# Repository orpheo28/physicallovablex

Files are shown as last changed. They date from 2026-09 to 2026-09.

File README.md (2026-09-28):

# PhysicalLovableX

Describe a physical product in one sentence; get a 3D model, its unit cost, a factory shortlist, and a package a factory can quote from.

## In 30 seconds

**What it does.** A Studio where you describe a product ("a Whoop competitor, screenless, 5-day battery"), see it in 3D with its cost at 500 / 2,000 / 10,000 units and its top factories, refine it by prompting, then press **Make it** to autofill the rest of the path to production: factories, negotiation, tooling, QC, logistics and duties, cash plan, brand. The output is a **Launch Dossier** (EN + CN).

**For whom.** Hardware founders, first consumer-electronics founders who have a prototype and pledged money and are stuck on production (`gtm-harness/context/icp.md`).

**The thesis.** Hardware ships late because nobody translates the idea into what a factory can build: making it manufacturable, choosing components, passing certification, speaking the factory's language. It is not mainly a design problem or a factory-access problem. We do the translation. The primitive is the **Factory Pack**: a spec package a factory can quote and build without back-and-forth. Every later layer (negotiation, QC, logistics, financing) consumes it (`docs/PRODUIT.md`, `docs/PRD.md` §1-3).

**How.** In software the AI writes code; in hardware, **CAD is code**. The AI writes build123d programs, they run in a sandbox, the result is measured, and on an error the AI repairs its own code.

## Links

| | |
|---|---|
| Live app | https://physicallovablex.vercel.app (password in the email) |
| Public docs | https://physicallovablex.vercel.app/docs |
| Agent guide | https://physicallovablex.vercel.app/agents.md (also `/llms.txt`) |
| Demo video | see email |

## What you can do

1. **Describe.** One sentence, in idea mode or prototype mode (paste a BOM).
2. **See.** The product in 3D, unit cost at 500 / 2k / 10k, and a top-3 factory shortlist on one screen. First version in 18-24 s over several live runs.
3. **Refine by prompting.** "Add SpO2 and skin-temperature sensing", "make it pink", "thinner, 8 mm pod". Each prompt creates a restorable version with a diff (CAD, BOM with real LCSC parts, costs, measured DFM, certifications, shortlist). Geometry changes are made by the AI editing its own build123d program, which is re-run, re-measured and self-repaired on error; the code is visible in the "CAD code" tab. Colour and feature refines take 4-7 s, geometry refines 11-24 s.
4. **Touch a part.** Click a part in the 3D view to change its colour, material or a dimension. This is a deterministic edit with no AI call (1.6-3.8 s in QA) and still produces a new version with a diff.
5. **Look inside.** Anatomy mode walks through the product layer by layer, generated from the real BOM. It is labelled "Illustrative internal layout — not a routed PCB".
6. **Make it.** 13 steps autofill to the Launch Dossier (EN + CN) in 54-88 s live, or instantly on the 7 showcases recorded through Make it (11 showcases in all).

**Pro CAD (shipped, on by default).** Standard fasteners, inserts and bosses with ISO 273 clearance holes (`app/api/cad/stdparts/`); assemblies with joints and measured interference and clearance checks (`app/api/cad/assembly/`: 0 interferences on all showcases, and it caught and fixed a real propeller collision on the drone); dimensioned technical drawings in the Studio, the Factory Pack and the Dossier (`app/api/cad/drawings/`). Flags `CAD_DETAIL_LEVEL=pro`, `CAD_ASSEMBLY=1`, `CAD_DRAWINGS=1` (`app/contracts/api.md`).

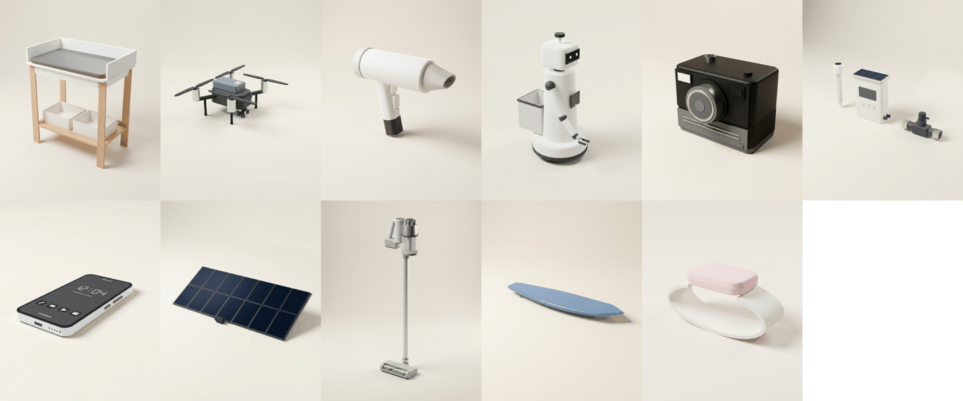
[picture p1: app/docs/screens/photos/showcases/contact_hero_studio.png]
Showcase gallery: 11 recorded products, rendered from their CAD


| Overview: cost at three volumes, shortlist, labels | Refine by prompting and by touching a part |
|---|---|
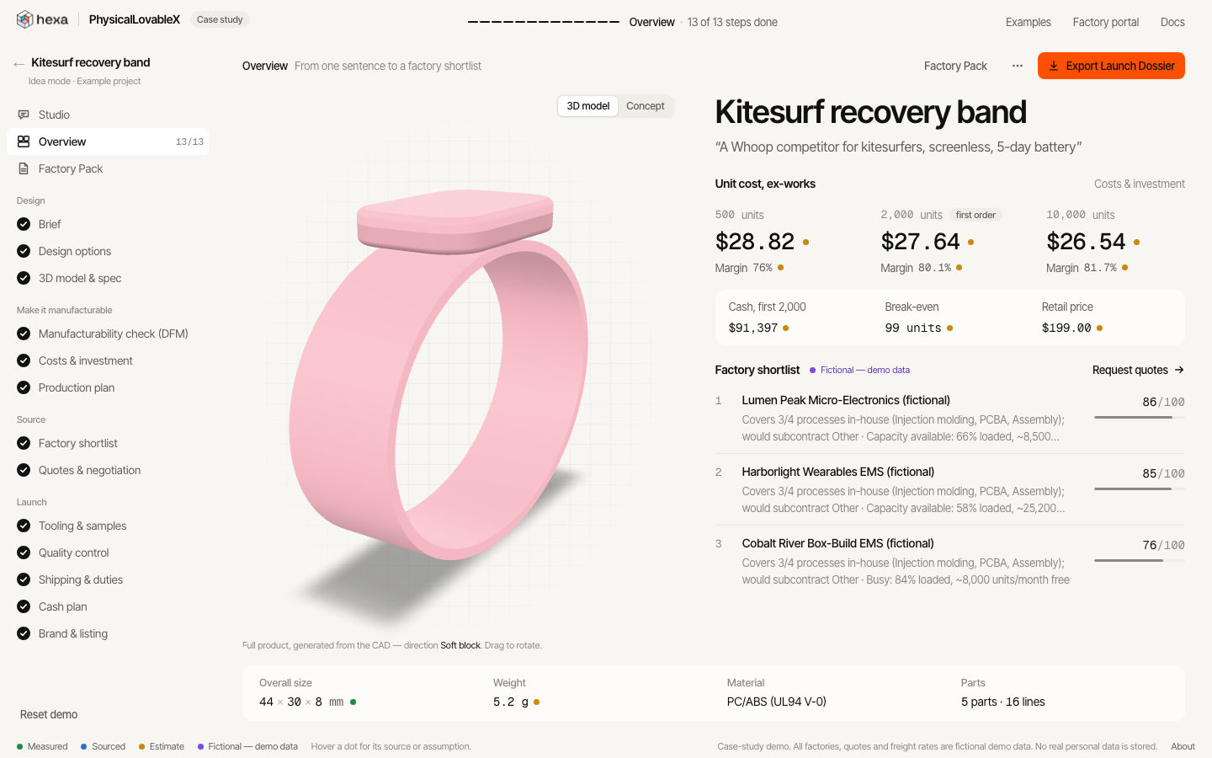
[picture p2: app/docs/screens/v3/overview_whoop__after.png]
Overview of the kitesurf recovery band
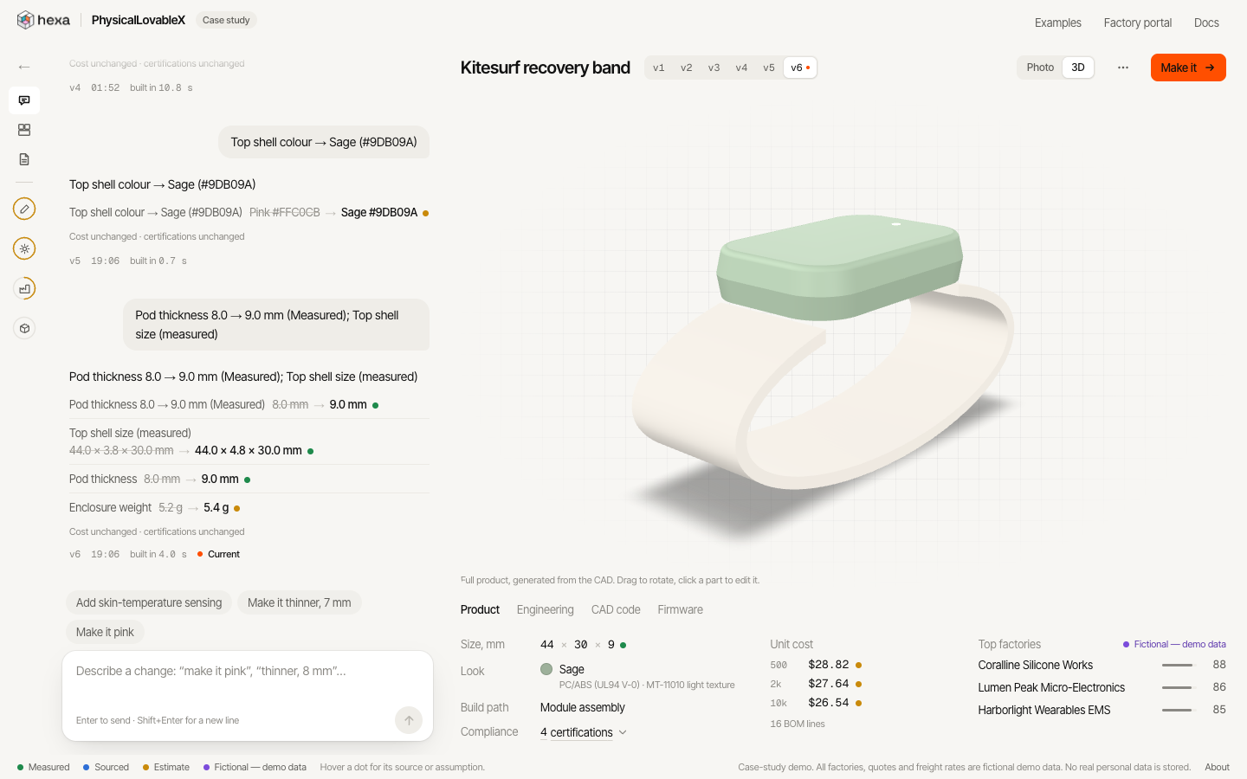
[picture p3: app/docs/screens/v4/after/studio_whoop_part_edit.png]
Studio with version history and part edits
|  |  |

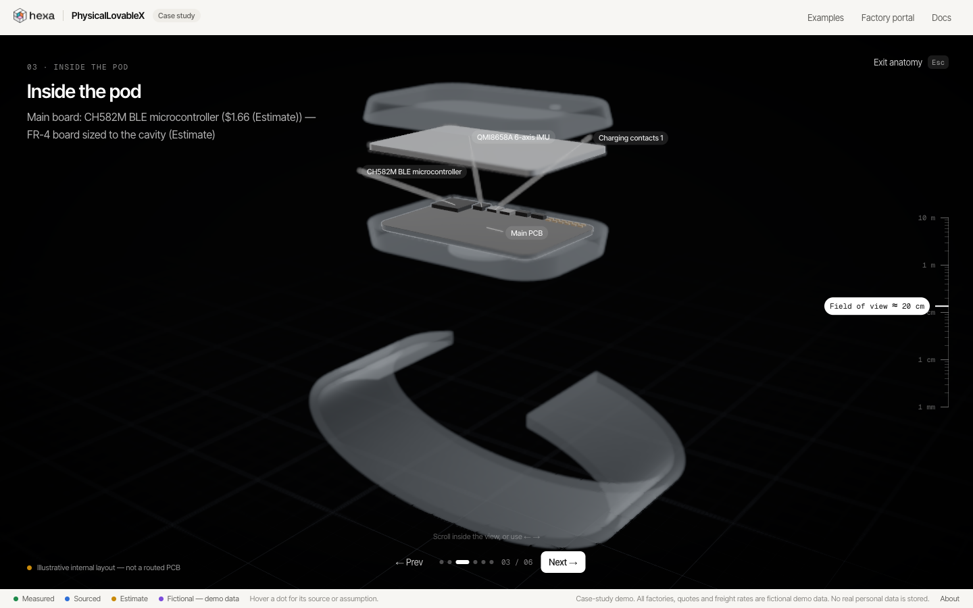
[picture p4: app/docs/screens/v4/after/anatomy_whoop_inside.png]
Anatomy mode: illustrative internal layout from the BOM


Timings: `docs/PRODUIT.md`, `app/docs/DEMO_SCRIPT.md` (measured live over several runs; they vary), `app/docs/QA_REPORT.md`.

## The brief → where it lives

| Case layer | What it means here | Where it lives |
|---|---|---|
| **Lovable layer** | Plain language in → design, CAD, spec, investment, production plan; refine by prompting | `app/api/studio/` (versions, refine, part edits), `app/api/cad/codegen/` (AI-written CAD), `app/api/stages/` (13-stage runner), `app/web/src/app/projects/[id]/studio/page.tsx` |
| **Alibaba layer + production MCP** | The spec is matched to a factory network that exposes capacity through an MCP; any agent can search capacity and request quotes | `app/factory_mcp/server.py` (7 tools), `app/api/mcp_http/` (served at `/mcp`), `app/docs/MCP_DEMO.md`, `app/web/src/app/factories/` (portal) |
| **Infra** | DFM, factory selection, agent negotiation, tooling, QC, logistics and duties, financing | `app/api/dfm/`, `app/api/agents/` (incl. `negotiation/`), `app/api/costs/` (cost, landed cost, HTS, freight), `app/api/engineering/` |
| **Value** | The Factory Pack and the Launch Dossier (PDF, EN + CN) | `app/api/export/` (`factory_pack.py`, `pdf.py`), `app/contracts/artifacts.py` (`FactoryPack`) |
| **Why now** | Generative AI can write and repair CAD code; the gap is translation, not sourcing (sourcing is commoditised) | `docs/PRD.md` §2-3, `app/docs/CAD_BENCH.md`, `gtm-harness/CLAUDE.md` (thesis v2) |

## What is real and what is simulated

Every number on screen, in the API and in the PDF carries one of four labels:

| Label | Meaning |
|---|---|
| **Measured** | Computed by code on the CAD (dimensions, volume, draft, wall thickness, physics checks) |
| **Sourced** | Real price or official rate, with source and date |
| **Estimate** | An assumption, shown |
| **Fictional — demo data** | Invented for the demo; factory names end with "(fictional)" |

**Data sources (Sourced):** LCSC / JLCPCB parts snapshot for component prices and stock (dated 2026-09-26); USITC HTS schedule and CBP CROSS rulings for the tariff line and duties; Drewry World Container Index for the sea-freight lane; eCFR and EUR-Lex for certification citations; EU PVGIS for solar yield; V-Trust for the QC man-day benchmark. Code: `app/api/costs/` (`lcsc.py`, `hts.py`, `precedent.py`, `freight.py`, `landed.py`), `app/api/agents/certification.py`, `app/api/engineering/solar.py`.

**Limits** (`app/docs/public/limits.md`):
- CAD is concept-level: good enough to see, measure, cost and brief a factory; not tooling-ready. About 80% of the translation is automated; humans and real factories cover the rest.
- The Anatomy internal layout is illustrative, not a routed PCB. Electronics stop at a power tree, netlist-level connections and a power budget.
- The generated firmware skeleton is not compiled or tested.
- All 15 partners (11 factories, 1 integrator, 3 installers), their capacity, quotes, negotiation replies, carrier freight quotes and transit days are fictional. The negotiation is a real agent loop over the MCP tools, but every reply is simulated; in Make it the quote is auto-approved and flagged.
- The HTS line is a precedent from CBP rulings, not a binding classification.
- The CN translation is machine-made and labelled "to be reviewed by a native speaker".

Stage-by-stage table of what is real: `app/README.md` ("Real vs simulated"). Audit of the labels: `app/docs/HONESTY_AUDIT.md`.

## Measured numbers

| What | Result | Source |
|---|---|---|
| Studio, first version | 18-24 s over several live runs | `docs/PRODUIT.md`, `app/docs/DEMO_SCRIPT.md` |
| Refines | colour and feature 4-7 s; geometry (AI edits its CAD) 11-24 s | same |
| Make it, 13 steps to the Launch Dossier | 54-88 s live (≈ $0.34 in one run) | same |
| Part edits (no AI) | colour 1.6 s, material 1.6 s, dimension 3.8 s (one QA run) | `app/docs/QA_REPORT.md` (3D wave regression, §3) |
| Core path, one live QA run | idea → v1 23.7 s; "Add SpO2…" 5.2 s; "Make it pink" 4.2 s; Dossier export 0.35 s, 38 pages | `app/docs/QA_REPORT.md` (§7) |
| Text-to-CAD benchmark | 20/20 prompts valid on the first try, 95 % within ±25 % of target size, 100 % OCCT-valid; ≈ 27 s per prompt | `app/docs/CAD_BENCH.md` |
| Retrieval-augmented CAD prompts (84 example programs) | no measurable gain on this benchmark; kept off by default | `app/docs/CAD_BENCH.md` |
| Backend tests | 719 passed, 31 skipped (final whole-suite run, C5 regression, 28 Sep; verdict "ready for pass-7") | `app/docs/QA_REPORT.md` ("C5 — pro CAD integration (28 Sep)") |
| Assembly checks | 0 interferences on all showcases; caught and fixed a real propeller collision on the drone | `app/api/cad/assembly/` |
| Web checks | `tsc --noEmit`, `lint`, production build: all pass (same run) | `app/docs/QA_REPORT.md` |
| Anatomy | 5 products, 6-7 steps each, open in ≤ 0.17 s | `app/docs/QA_REPORT.md` (§5) |

The QA report also lists the open bugs found at each wave, with severity.

## Architecture

```mermaid
flowchart LR
  L[Framer landing page] --> W
  U[Founder in a browser] --> W
  subgraph Vercel
    W[Next.js web app<br/>password gate · /backend proxy<br/>/docs · /agents.md · /llms.txt]
  end
  subgraph Railway
    A[FastAPI<br/>stage runner · Studio · cost engine]
    C[build123d sandbox<br/>AI-written CAD, measured]
    D[(SQLite<br/>projects · versions)]
    M[factory_mcp<br/>7 tools · fictional network store]
    H["/mcp<br/>Streamable HTTP, Bearer token"]
    A --> C
    A --> D
    A --> M
    H --> M
  end
  W --> A
  A --> O[OpenRouter<br/>main · fast · CN · image routes]
  X[External agents<br/>Claude Code, Claude Desktop, scripts] --> H
```

**Stack.** Python 3.12 with uv, FastAPI, build123d 0.13 (OpenCascade), SQLite, the official MCP Python SDK. Next.js 16, React 19, three.js with react-three-fiber (model-viewer fallback via `?viewer=basic`). Models through OpenRouter on four routes (main, fast, CN, image), configured by environment. Every LLM call goes through `app/api/llm.py` (JSON-schema validation, one retry); any stage failure serves a cached example with a visible banner. Deploy: Railway for the API (Dockerfile, volume at `/data`), Vercel for the web.

## Repository map

```
app/                     the product (see app/README.md)
  api/                   FastAPI backend
    stages/              13-stage runner, plug-in registry, fixture fallback
    studio/              versions, refine jobs, part edits, restore
    cad/                 build123d CAD: families, codegen/ (AI-written CAD), anatomy/, photos/, stdparts/, assembly/, drawings/
    dfm/                 measured DFM on the STEP
    costs/               cost engine, LCSC, HTS, duties, freight, landed cost
    agents/              brief, DFM review, certification, planning, brand, negotiation/
    engineering/         physics checks, electronics, firmware skeleton, build strategy, solar
    export/              Factory Pack assembly and Launch Dossier PDF
    mcp_http/            the production MCP over HTTP at /mcp
    fixtures/            cached examples and showcases (the fallback path)
  web/                   Next.js app (Studio, 13 stages, Overview, portal, public docs)
  factory_mcp/           production MCP server (7 tools) and the fictional network
  contracts/             Pydantic models, JSON schemas, API contract (read first)
  tests/                 pytest suites, CAD benchmark harness, 10-prompt runner
  docs/                  QA report, CAD benchmark, demo script, deploy, honesty audit, public docs, screenshots
  scripts/demo_start.sh  one-command local start
gtm-harness/             go-to-market agent harness (context, skills, workflows, playbooks)
gtm/                     landing copy, sequences, content plan, video scripts
docs/                    PRD.md (full spec), PRODUIT.md (one-page product definition)
```

**Start here** — the 10 files that explain the system fastest:

1. `app/contracts/api.md` — every route, section by section, including the Studio refine job
2. `app/api/stages/runner.py` — how a stage runs and falls back to a cached example
3. `app/api/studio/engine.py` — start, refine, restore; one commit per version or nothing
4. `app/api/cad/codegen/engine.py` — the AI writes build123d, the sandbox runs it, it is measured and repaired
5. `app/api/cad/anatomy/` — the illustrative internal layout built from the BOM (no LLM)
6. `app/api/costs/engine.py` — deterministic cost engine; the LLM only proposes BOM lines
7. `app/api/engineering/service.py` — physics checks, electronics, firmware skeleton
8. `app/factory_mcp/server.py` — the 7 production MCP tools
9. `app/web/src/app/projects/[id]/studio/page.tsx` — the Studio screen
10. `gtm-harness/CLAUDE.md` — ICP, signals, positioning, thesis in one page

## Go-to-market

- `gtm-harness/` is a Claude Code harness for founder-led outreach. `CLAUDE.md` is the one-page brief; `context/` holds the ICP (late crowdfunded consumer-electronics founders first), six scored buying signals with decay, positioning, competitor battlecards, metrics and personas.
- `gtm-harness/skills/` has nine repeatable procedures (ICP scoring, account research, signal-to-sequence, teardown, value pack, reply handling, call debrief, weekly update, AEO check); `workflows/` and `playbooks/` cover routing, campaigns, enrichment, and what to do when a founder replies.
- Rules built in: every claim carries a source or is marked Hypothesis; a human approves and sends every message; no contact data is stored in the repo.
- `gtm/` holds the landing page copy and Framer components, the written (not executed) sequences, a four-week content plan, the GTM stack by phase, and the demo and launch video scripts.

## How it was built

- **Orchestration.** One Monitor session planned the work and dispatched about 40 parallel Claude Code worker sessions (W0-W29, C1-C5). Each worker owned its folders (`app/README.md`, "Layout and owners").
- **Contracts first.** Pydantic models, JSON schemas, the API contract and generated TypeScript types were frozen before the first wave (`app/contracts/`). Changes are additive and recorded per worker in `api.md`.
- **Fixtures and fallbacks.** Every stage has a cached example: on an AI failure it serves that example with a visible "Cached example" banner instead of an error.
- **QA waves.** Dedicated QA sessions ran regression passes between waves, up to release checkpoint pass-6 (`app/docs/QA_REPORT.md`).
- **Timeline.** Saturday 26 to Monday 28 September 2026.
- **Budget.** The product's own model calls (development, QA, benchmarks) cost about $17 on OpenRouter, measured on the key's usage counter ($16.69 after the CAD benchmark, `app/docs/CAD_BENCH.md`). Each QA wave records its live spend in the QA report.

## Run it locally

```bash
cd app
cp .env.example .env        # optional: add OPENROUTER_API_KEY and the model routes; without a key every stage serves fixtures
uv sync
(cd web && npm install)
scripts/demo_start.sh       # API on :8000, production web build on :3000, seeds demos and showcases, prints READY
```

Tests:

```bash
uv run pytest                                   # offline, no key needed
cd web && npx tsc --noEmit && npm run lint && npm run build
```

Details: `app/README.md` (run, env guards, contracts), `app/docs/DEMO_DAY.md` (start script, offline backup). Deploy (Railway API + Vercel web): `app/docs/DEPLOY.md`. Production MCP setup: `app/docs/MCP_DEMO.md`.

## Roadmap (next 90 days)

- **Real factory onboarding through the MCP.** The registration flow exists; real, audited factories do not yet. First ones introduced by intermediaries who already hold factory trust (`docs/PRD.md` §18).
- **Human-reviewed Factory Packs (tier 2).** An engineer signs every pack before a real factory sees it, with a committed landed price.
- **Text-to-PCB.** Today electronics stop at the power tree and netlist-level connections.
- **A fine-tuned CAD model**, trained on programs that pass the sandbox and the measurements.

## Credits and licences

- [build123d](https://github.com/gumyr/build123d) — CAD kernel interface (OpenCascade)
- [three.js](https://threejs.org) — 3D viewer
- [Poly Haven](https://polyhaven.com) — CC0 studio HDRI (`app/docs/BRAND.md`)
- [earthtojake/text-to-cad](https://github.com/earthtojake/text-to-cad) (MIT) — DFM measurement ported in `app/api/dfm/measure.py`
- [CDFER/jlcpcb-parts-database](https://github.com/CDFER/jlcpcb-parts-database) (MIT) — LCSC / JLCPCB parts snapshot
- [bd_warehouse](https://github.com/gumyr/bd_warehouse) (Apache-2.0) — reference data for standard parts; not a dependency (`app/api/cad/stdparts/README.md`)

## License

Source-available for evaluation only ([LICENSE.md](LICENSE.md)): you may read, clone, run and analyse it (including with AI assistants) to evaluate the project. Any other use, including commercial use, redistribution, derivative works or model training, needs written permission. Copyright 2026 Orphéo Hellandsjo.

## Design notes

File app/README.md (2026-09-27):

# PhysicalLovableX — MVP

## What it is
The Lovable of physical products, built as a **Studio**: describe a product in a sentence, see it in 3D with its cost and top factories (first version in 18-24 s over several live runs), then refine it by prompting: colour and feature changes take 4-7 s, geometry edits 11-24 s, and each creates a restorable version with a diff (CAD, real LCSC parts, costs, measured DFM, certifications, shortlist).
In software the AI writes code; in hardware **CAD is code**: the AI writes build123d code, it runs in a sandbox, is measured and self-repaired on error (visible in the "CAD code" tab); physics checks then run on the measured model. Concept-level geometry: about 80% of the translation is automated, humans and real factories cover the last 20%.
**Make it** autofills the rest (factories via the production MCP, agent negotiation with auto-approvals flagged, tooling, QC, logistics and duties, cash plan, brand) to the Launch Dossier (EN + CN), 13 steps in 54-88 s live, or instantly on the 11 recorded showcases; the 13 stages stay as the detailed view, in 4 phases. The primitive is the **Factory Pack**.
Real: AI-written CAD, measured DFM and physics checks, LCSC prices, HTS/duties, PVGIS, Drewry freight index. Fictional and labeled: the 15 fictional partners (11 factories, 1 integrator, 3 installers), their quotes, carrier freight; firmware skeletons are generated, not compiled or tested. The production MCP is served over HTTP at `/mcp` (`docs/MCP_DEMO.md`). The build strategy (full design / module assembly / ODM customisation) is chosen per product, and 11 recorded showcases are included.
Specs: `../PRD.md` (§8.2-8.5), `../PLAN.md`, `../MONITOR.md`; demo: `docs/DEMO_SCRIPT.md`.

## Run
```bash
# API (from mvp/) — Python 3.12 via uv
cp .env.example .env            # add OPENROUTER_API_KEY + the 3 model routes; without a key every stage serves fixtures
uv sync
uv run uvicorn api.main:app --port 8107         # any free port; keep 8000/3000 for the deployed setup
# parallel dev sessions: isolate state, e.g. DB_PATH=api/data/w7.db FILES_DIR=api/data/files_w7 (the factory store follows: api/data/w7_network.db)
curl -X POST localhost:8107/demo/reset          # seeds the 2 cached examples (desk lamp, tracker card) + resets the factory network

# Web
cd web && npm install && NEXT_PUBLIC_API_URL=http://localhost:8107 npm run dev

# Tests (offline, no key, temp DB/network/CAD dirs — covers tests/, api/, factory_mcp/)
uv run pytest

# The 10 PRD test prompts against a running API (live if the key is set) → tests/results/<timestamp>.md
uv run python tests/run_prompts.py --base-url http://localhost:8107 [--only 3,4,5]

# Production MCP server (stdio) — see factory_mcp/README.md for Claude Code / Desktop config
uv run python -m factory_mcp.server
```

Env guards: `LLM_MAX_TOKENS` (per request), `LLM_MAX_REQUESTS` (per API process), `LLM_TIMEOUT_S`,
`LLM_REASONING_EFFORT` (default `low`), `STAGE_TIMEOUT_S` (default 45 — hard cap per stage and on the Factory Pack, then the
cached fixture with reason "timeout"). Key stays server-side; `.env` is gitignored.

Autorun is asynchronous (serverless-friendly): `POST /projects/{id}/autorun` → 202, then poll `GET /projects/{id}` every 2 s
(`autorun.state`, `autorun.current_stage`, per-stage status). `?wait=true` keeps the synchronous behaviour for scripts.

Latest live run: `tests/results/` (10/10 pass, wow screen ≈ 1 min per prompt — see the report for per-stage times).

## Deploy
Web on Vercel (root `web/`), API + CAD on Railway (`Dockerfile` + `railway.toml`, volume at `/data`). Full click-by-click steps,
env vars, rollback and costs: **`docs/DEPLOY.md`**. Agents prepare, the owner clicks deploy.

| Env (API) | Effect |
|---|---|
| `API_SHARED_KEY` | set → every route except `GET /health` (files included) needs header `X-App-Key`; unset → open (local dev). The web password (`APP_PASSWORD`) is a separate, web-only variable |
| `MAX_STORED_PROJECTS` | keep only the N most recent generated-CAD folders in `FILES_DIR` (default 30; Railway trial volume ≈ 0.5 GB) |
| `CORS_ORIGINS` | comma-separated allowed web origins (default `http://localhost:3000`) |
| `RATE_LIMIT_PER_DAY` | live runs per client IP per 24 h on `POST /projects`, `/stages/*/run`, `/autorun` (default 20, 0 = off; only when a key is set) → 429 |
| `DEMO_READONLY=1` | no live AI runs (403); cached demo projects, fixtures, portal and PDF still work — zero-cost public mode |
| `SEED_DEMO_ON_EMPTY=1` | seed the two demo projects at startup when the DB is empty (set in the Docker image) |
| `DB_PATH`, `FILES_DIR`, `FACTORY_MCP_DB` | `/data/app.db`, `/data/files`, `/data/network.db` in the image (Railway volume) |

Local container check: `docker build -t plx-api . && docker run -p 8000:8000 plx-api` (peak ≈ 365 MiB for a CAD build + export; image 2.0 GB, ≈ 470 MB compressed).
Honesty audit of the numbers shown to users: `docs/HONESTY_AUDIT.md`.

## Contracts (read before coding)
- `contracts/artifacts.py` — Pydantic models for the 13 stage artifacts, Factory Pack, network records, `Label`, `LabeledValue`.
- `contracts/api.md` — routes · `contracts/stage_runner.md` — plug-in API · `contracts/fixtures.md` — fixture layout.
- Regenerate schemas + TS types after a (Monitor-approved) contract change:
  `uv run python -m contracts.export_schemas && (cd web && npm run gen:types)`.

## Layout and owners
| Folder | Owner |
|---|---|
| `contracts/`, `api/main.py`, `api/llm.py`, `api/db.py`, `api/discovery.py`, `api/stages/` | W0 (W7 for integration fixes) |
| `web/` | W1 |
| `api/cad/`, `api/dfm/` | W2 |
| `api/costs/` | W3 |
| `api/agents/` (except `negotiation/`) | W4 |
| `factory_mcp/`, `api/agents/negotiation/` | W5 |
| `api/fixtures/`, `api/export/`, `tests/` | W6 |

Stage modules register with `@stage_handler(n)` and are auto-discovered at startup; nobody edits `api/main.py`.
Every LLM call goes through `api.llm.complete_json` (JSON schema validation + 1 retry); any stage failure serves the
cached fixture with `fallback: true` and a visible "Cached example" banner — the demo never 5xx's on an AI failure.

## Real vs simulated
Honesty labels everywhere (screen + PDF): **Measured** (computed on the CAD), **Sourced** (real price/official rate +
date + URL), **Estimate** (assumption shown), **Fictional — demo data**. Factory names are invented and end with "(fictional)".

| Stage / artifact | What is real | What is simulated or estimated | Label |
|---|---|---|---|
| 1 Brief | Live LLM (main route), ≤5 clarifying questions with defaults, idea + prototype (pasted BOM) modes | Target price when not stated | Estimate |
| 2 Design | 3 parametric directions (LLM proposes, code clamps), real GLB per direction | AI concept renders are illustrative, not the CAD | — |
| 3 CAD + spec | build123d two-shell enclosure → STEP / STL / GLB; dimensions from the STEP bounding box | Weight = measured volume × assumed density; BOM proposed by the LLM | Measured / Estimate |
| 4 DFM | **Measured** draft, undercut, projected area, wall thickness on the STEP (port of text-to-cad DFM, MIT); AI-reviewed alerts with cited rules (never contradict a measurement); rule-based certification map by market; component risk from the LCSC snapshot | Certification costs/lead times; clamp tonnage formula | Measured / Sourced / Estimate |
| 5 Investment | **Real LCSC/JLCPCB prices + stock** (snapshot 2026-09-26) for matched electronic lines; deterministic cost engine, 3 volumes, tooling, cash, margin, break-even | Mechanical parts, assembly, tooling ranges, unmatched parts | Sourced / Estimate |
| 6 Production plan | Process per part with reason | Lead times | Estimate |
| 7 Matching | Deterministic scoring via the production MCP (`search_capacity`) | **The 15 fictional partners (11 factories, 1 integrator, 3 installers) and their capacity** | Fictional — demo data |
| 8 RFQ + negotiation | Real agent loop over the MCP tools (`request_quote` → `submit_quote` → `counter_offer` → `accept_quote`), LLM factory agents with distinct personalities, clamped by policy | **Quotes, replies, final terms** | Fictional — demo data |
| 9 Tooling + samples | Milestones computed from the negotiated lead time; payment split follows the approved quote's terms; date checks | Durations beyond the quote | Estimate / Fictional |
| 10 QC | ISO 2859-1 sample size (General II), defects mapped to spec lines, $268/man-day benchmark | Inspection days | Sourced / Estimate |
| 11 Logistics | HTS from the closest **CBP CROSS ruling precedent** + cached USITC schedule (general rate Sourced; Section 301 Sourced when a ruling cites a 9903.88.xx heading, e.g. lamp 8513.10.40.00 = 3.5 % + 25 %, tracker 8517.62.00.90 = Free + 7.5 %); sea freight derived from the **Drewry WCI** lane rate (Sourced) | Classification itself (precedent, not binding — confirm with a broker), LCL/FCL derivation and air $6/kg by chargeable weight (Estimate), transit days (Fictional) | Sourced / Estimate / Fictional |
| 12 Financing | Cash curve = stage 5 total cash, allocated to stage 9 milestones | Financing options are typical ranges | Estimate |
| 13 Brand | Live LLM name options, packaging spec, landing copy, Shopify + Amazon drafts | — | Estimate |
| Factory Pack / PDF | Assembled from stages 1-6; CN machine translation via the CN route (labeled "to be reviewed by a native speaker") | — | as per source |

Cached examples (`api/fixtures/desk_lamp`, `api/fixtures/tracker_card`, regenerated by their `build_*.py`): measured DFM
values are the real output of `api/dfm/measure.py` on `api/cad/prebuilt/<id>/enclosure.step`; landed cost, duties,
freight and stages 11-12 are computed by the live `api/costs` code (`api/fixtures/_live.py`); LCSC prices are real
(jlcsearch, 2026-09-26); design images: `dN.png` = AI concept render (illustrative), `hero_dN.png` = rendered from the CAD.

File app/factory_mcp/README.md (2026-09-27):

# factory_mcp/ — Production MCP (PRD §10)

**Owner: W5.** The "Alibaba layer": a fictional production network exposed as an MCP server, so **any agent**
(ours, Claude, ChatGPT, a buyer's own agent) can query capacity the same way. Research (E_usines.md) found no
public capacity API: the network *creates* the data through factory onboarding (`register_capacity`).

> Everything here is **Fictional — demo data**: the 15 fictional partners (11 factories, 1 integrator, 3 installers), their capacity, quotes, replies and past performance.
> Every name ends with "(fictional)".

| File | What |
|---|---|
| `network.py` | Plain Python (no MCP import): SQLite store + the 7 tools + `list_factories / get_factory / list_rfqs` (factory portal) |
| `server.py` | MCP server (official SDK v2 `MCPServer`, ex-`FastMCP`) exposing the 7 tools over `network.py` |
| `data/factories.json` | 15 seed partners, `kind` factory / integrator / installer: W0's 4 ids + mould maker, box-build EMS, die-caster, 1688-style workshop; 3 installers (W20); 2 wearable EMS + 1 drone/robot integrator (W21); LSR overmolder Coralline (W21b) |
| `data/seed_rfqs.json` | Demo RFQs for the desk lamp (portal history) |
| `data/network.db` | Runtime state (gitignored). Path: `$FACTORY_MCP_DB`, else next to `$DB_PATH` (`app.db` → `factory_network.db`, `<name>.db` → `<name>_network.db`, so isolated DBs never share a store), else here. SQLite WAL |

## Tools
| Tool | Caller | Returns |
|---|---|---|
| `register_capacity(name, region, processes[], materials[], moq, certifications[], lead_time_days, monthly_capacity, current_load_pct)` | factory | `factory_id` |
| `search_capacity(process, material, quantity, certifications_required[], deadline?)` | platform | ranked `FactoryMatch[]` with `score_breakdown` + `reasons` |
| `get_factory_profile(factory_id)` | platform | `Factory` (capacity, audit notes, past performance) |
| `request_quote(factory_id, factory_pack_id, quantities[])` | platform | `rfq_id` |
| `submit_quote(rfq_id, unit_price_per_tier{qty: usd}, tooling_usd, moq, lead_time_days, payment_terms, exceptions[])` | factory agent | `quote_id` (new version) |
| `counter_offer(quote_id, proposed_changes{unit_price_pct, tiers, tooling_usd, moq, lead_time_days, payment_terms}, rationale)` | platform agent | new `Quote` version (`countered`) |
| `accept_quote(quote_id)` | platform, after founder approval | order draft |

`search_capacity` is deterministic: score = 100 × (0.35 process fit + 0.15 MOQ + 0.15 certifications + 0.15 load
+ 0.20 lead time); factories that do not run the process are excluded; ties break on id.

## Run
```bash
cd 04_LIVRABLE/mvp
uv run python -m factory_mcp.server          # stdio
```

**Claude Code**
```bash
claude mcp add physicallovablex-production -- uv --directory /ABS/PATH/04_LIVRABLE/mvp run python -m factory_mcp.server
```

**Claude Desktop** (`claude_desktop_config.json`)
```json
{
  "mcpServers": {
    "physicallovablex-production": {
      "command": "uv",
      "args": ["--directory", "/ABS/PATH/04_LIVRABLE/mvp", "run", "python", "-m", "factory_mcp.server"]
    }
  }
}
```
Then ask e.g. "Which factories can injection-mould PC/ABS at 2,000 units with ISO 9001?".
The API (stages 7-8, factory portal) and the MCP server share the same store when run with the same env.

## Tests
```bash
uv run pytest factory_mcp api/agents/negotiation     # offline, temp store, no key
```

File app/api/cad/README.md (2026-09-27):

# api/cad/

**Owner: W2 — CAD + DFM.** Only this session edits this folder.

- `build.py` — `build_direction(params, out_dir, name=None)` → `{"step","stl","glb"}`. build123d two-shell
  enclosure (top/bottom split at `split_ratio`, real wall, 1.5° draft on every vertical wall via tapered
  extrusions, drafted M2.5 screw bosses). Families: 0 soft rounded box · 1 puck · 2 slim slab. Cached by
  params hash in `<out_dir>/_cache/`. Files live in `api/data/files/<project_id>/` (`FILES_DIR` overrides).
- `directions.py` — `@stage_handler(2)`: LLM "fast" proposes 3 directions (one per family) → clamped by
  `normalize`; deterministic presets by brief category when the LLM is unavailable. GLB at `/files/<pid>/dN.glb`.
- `spec.py` — `@stage_handler(3)`: direction from `inputs.direction_id` → chosen → first. Dimensions Measured
  from the STEP bounding box, weight = measured volume × stated density (Estimate). BOM/block diagram:
  LLM "fast" → cached example BOM → generic template. `cad_files` = chosen `/files/<pid>/dN.glb` ("Full product — materials", first GLB = viewer default) then
  `/files/<pid>/enclosure.{step,stl,glb}` ("Moulded parts (DFM)"; DFM reads the STEP).
- `look.py` (W12) — per-part PBR materials + full-product viewer GLB. `look_for(material, finish)` → role → glTF
  material (moulded body/lower shell in the direction colour, anodised aluminium, powder coat, TPE rubber, lit frosted
  diffuser, status light pipe, USB-C port, stainless steel). `build_assembly` = the two shells + feet/button/light
  pipe/port (+ diffuser for lighting, stainless bowl for pet/food) → **dN.glb**. dN.step/stl and `enclosure.*` stay
  the moulded shells only (DFM input); stage 3 recolours `enclosure.glb` from the chosen direction.
- `renders.py` (W12) — one AI concept render per direction (`LLM_IMAGE_MODEL` via OpenRouter, 1024² PNG,
  `/files/<pid>/dN.png` → `render_url`). Runs in parallel with the CAD builds; 25 s timeout + 1 retry inside a 27 s
  stage budget, else `render_url = null` (never fails stage 2). Honesty: Assumption `a2_render` (estimate)
  "AI concept render — illustrative, not the CAD".
- `_blender_render.py` (W12, offline) — `blender -b -P api/cad/_blender_render.py -- in.glb out.png [1600] [128]`:
  Cycles render of a material GLB (3-point area lights, shadow catcher, #F7F6F3 seamless background, 3/4 camera
  framed on the bbox, denoise). Produced `prebuilt/<id>/hero_dN.png` for both demos (Blender 5.2.2, ~45 s each).
  Caption: "Rendered from the CAD". Not in the live path.
- `wearables.py` (W17) — families **3 wearable_band** (pod L × W × thickness incl. a 0.8 mm drafted optical sensor window,
  two drafted shells; `strap_width` / `strap_length` → LSR strap drawn in the full-product GLB only) and **4 ring**
  (length = width = outer Ø, height = band width, wall = band thickness; drafted annular halves + drafted inner sensor
  bump). Own plausible ranges in `normalize` (`build.py` delegates for family ≥ 3); `look.build_assembly` uses
  `assembly_parts` (top = body colour, bottom = accent, strap = body). Used by the Studio (api/studio) for wearables.
- `files.py` — `GET /files/{project_id}/{filename}`: `api/data/files/<pid>/` → `api/cad/prebuilt/<pid>/` → 404.
  Whitelisted names, resolved path must stay in its base dir.
- `prebuilt/` — committed demo CAD, regenerate with `uv run python -m api.cad._prebuild`:
  `demo_desk_lamp` (d1 column / d2 arc / d3 puck concepts as full lamps with materials + dN.png renders (`--renders`); enclosure = moulded head housing + base shell) and
  `demo_tracker_card` (small presets; enclosure = d3 slim slab 86 × 54 mm).
- `test_cad.py` — `uv run pytest api/cad api/dfm`.

Contracts: `contracts/artifacts.py`, `contracts/api.md`, `contracts/stage_runner.md`, `contracts/fixtures.md`. Never edit `contracts/`, `api/main.py`, `pyproject.toml`, `web/package.json` — send a CONTRACT CHANGE REQUEST to the Monitor.

## W29 — finished GLBs, parts, anatomy
- `glb.py` — every GLB the pipeline writes goes through `glb.finalize` (called by `look.apply_materials` and
  `families.apply_look`): scene root `product` → one node per part (`part_id`, PartMeta extras) → mesh children
  `<material role>.<n>`; baked transforms (metres, +Y up), OCCT normals averaged across face seams within 30°, welded
  vertices, no UVs; PBR + KHR clearcoat / sheen / transmission / ior / specular / emissive_strength per role.
  Tessellation: `build.glb_tolerance` (linear = size / 2500 mm, 0.12 rad). A finished GLB is only recoloured.
- `parts.py` — which label is which part: the label call sites (traced in the codegen sandbox and in-process family
  builds) → variable / comment keywords → semantic role; the P keys each part depends on → editable parameters.
  `partnames_curated.py` pins the names of the recorded showcase programs (keyed by the program minus its P dict).
- `anatomy/` — `GET /projects/{id}/anatomy`: package table (`packages.py`), numpy primitives (`mesh.py`), family rules
  + storyboard (`layout.py`); companion `anatomy_v<n>.glb` + `.json`, cached per version (showcases: precomputed).
- `_w29_regen.py` — `python -m api.fixtures._showcase w29 [slugs…]` rebuilds the showcase / demo GLBs, bakes /parts
  extras and anatomy (no LLM). Studio side: `api/studio/parts.py` (GET /parts), `api/studio/edit.py` (POST edit).

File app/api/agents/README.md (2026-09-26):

# api/agents/

**Owner: W4 — Agents.** Only this session edits this folder.

Stage 1 (brief + ≤5 clarifying questions, both modes), 6 (production plan), 9 (tooling + samples), 10 (QC), 13 (brand) via `@stage_handler(n)`; plus reusable functions for stage 4 (AI-reviewed DFM text, component risks, certification map) that W2 calls. Every LLM call goes through `api.llm.complete_json`. The `negotiation/` sub-folder belongs to W5.

Contracts: `contracts/artifacts.py`, `contracts/api.md`, `contracts/stage_runner.md`, `contracts/fixtures.md`. Never edit `contracts/`, `api/main.py`, `pyproject.toml`, `web/package.json` — send a CONTRACT CHANGE REQUEST to the Monitor.

## What lives here (W4)

| Module | Stage / function | LLM route | Without a key |
|---|---|---|---|
| `brief.py` | stage 1 (idea + prototype mode, ≤5 questions with defaults, answers from `inputs["answers"]`) | main | raises → fixture |
| `dfm_review.py` | `ai_review(spec, bom, measured) -> list[DFMIssue]` (stage 4, called by W2) | main | deterministic checklist |
| `certification.py` | `certification_map(brief, spec) -> list[Certification]` (stage 4, called by W2) | fast (optional nuance) | rule-based core |
| `production_plan.py` | stage 6 | fast (reasons + notes only) | code-written reasons, `generated_by="code"` |
| `tooling.py` | stage 9 (dates + 30/70 payments, Python date check → assumptions) | none | always code |
| `qc.py` | stage 10 (ISO 2859-1 General II, AQL 0/2.5/4.0, spec_refs validated) | fast | code-derived defects |
| `brand.py` | stage 13 | fast | raises → fixture |

`_common.py`, `_planning.py` are private helpers (lead-time table, sample-size table, formulas). Prompts: `prompts/*.md` (`{{placeholders}}`).

### `BriefArtifact.category` vocabulary (fixed — W2/W3 may rely on it for defaults)
`lighting`, `ble_accessory`, `iot_sensor`, `wearable`, `audio`, `input_device`, `kitchen_appliance`, `mechanical`, `other`.

### Stage 1 answers
`POST .../stages/1/run {"inputs": {"answers": {"q1": "US + EU", "q3": "€39"}}}` — keys are question ids (`q1`..`q5`) or topics (`markets`, `volume`, `target_price`, `battery`, `wireless`). An unanswered question keeps its default in `answer` and gets `skipped: true`.

### Stage 9 inputs
Optional `{"start_date": "YYYY-MM-DD"}` (default: next Monday). Lead time: stage 8 `final_terms` → recommended quote → stage 6 plan → defaults.

### Tests
`uv run pytest api/agents --ignore=api/agents/negotiation` — offline (key cleared by `api/agents/conftest.py`); `test_live_smoke.py` runs one tiny call per configured route only if `OPENROUTER_API_KEY` is set.

**Sourced citations (W13).** `certification.py` quotes 47 CFR Part 15 (15.19, 15.101, 15.103, 15.107, 15.109, 15.247, 15.407) from
`data/certs/fcc_part15.json` (written once by `_fetch_ecfr.py`, eCFR text as of 2026-09-22, retrieved 2026-09-26) in the FCC rows'
`applies_because`. CE / UKCA / UN38.3 rows carry hand-written EUR-Lex, gov.uk and IATA references (Sourced for the citation only);
costs and lead times stay Estimates.

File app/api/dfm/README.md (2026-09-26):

# api/dfm/

**Owner: W2 — CAD + DFM.** Only this session edits this folder.

- `measure.py` — measured geometry checks on a STEP file (straight two-half pull along ±Z by default):
  draft per B-rep face (flag < 1°, < 3° on textured finishes), undercut candidates (ray occlusion per body),
  projected area → clamp-tonnage estimate, sampled wall thickness. Every `measurement` is `label: measured`
  with the check in `source_or_assumption`; the tonnage is stated as an Estimate with its formula.
- `stage.py` — `@stage_handler(4)`: measured issues first, then `api.agents.dfm_review.ai_review` (W4),
  `api.agents.certification.certification_map` (W4) and `api.costs.lcsc.component_risk` (W3), each in its own
  try/except → that section from the project's cached example with an Assumption. ≥3 issues guaranteed.
  If the measured part fails (no STEP, OCCT crash) the handler raises and the runner serves the fixture.
- `test_dfm.py` — `uv run pytest api/cad api/dfm` (offline, no key).

## Credit

The measurement logic (draft per face vs pull with flat faces read exactly and curved faces at the 5th
percentile of their area, tangent bands excluded, absolute area floor; straight-pull occlusion undercut
test per body with zero-draft faces trapped only if blocked both ways; rasterised silhouette projection) is
ported from **earthtojake/text-to-cad**, `skills/dfm/scripts/mold_tool.py` (DFM skill, PR #391),
MIT License, Copyright (c) 2026 Thompson Labs LLC — https://github.com/earthtojake/text-to-cad.
The port works on OCCT B-rep faces (build123d/OCP) instead of trimesh meshes, so it needs no extra dependency.

MIT License text (as required): Permission is hereby granted, free of charge, to any person obtaining a copy
of this software and associated documentation files (the "Software"), to deal in the Software without
restriction, including without limitation the rights to use, copy, modify, merge, publish, distribute,
sublicense, and/or sell copies of the Software, and to permit persons to whom the Software is furnished to do
so, subject to the following conditions: The above copyright notice and this permission notice shall be
included in all copies or substantial portions of the Software. THE SOFTWARE IS PROVIDED "AS IS", WITHOUT
WARRANTY OF ANY KIND, EXPRESS OR IMPLIED.

Contracts: `contracts/artifacts.py`, `contracts/api.md`, `contracts/stage_runner.md`, `contracts/fixtures.md`. Never edit `contracts/`, `api/main.py`, `pyproject.toml`, `web/package.json` — send a CONTRACT CHANGE REQUEST to the Monitor.

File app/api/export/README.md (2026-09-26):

# api/export/

**Owner: W6 — Fixtures + Export + Tests.** Only this session edits this folder.

`@provider("export_pdf")` → Launch Dossier PDF bytes (ReportLab, CN via STSong-Light) and `@provider("factory_pack")` → assemble FactoryPack from stages 1-6 (+ CN questions via route `cn`).

Contracts: `contracts/artifacts.py`, `contracts/api.md`, `contracts/stage_runner.md`, `contracts/fixtures.md`. Never edit `contracts/`, `api/main.py`, `pyproject.toml`, `web/package.json` — send a CONTRACT CHANGE REQUEST to the Monitor.

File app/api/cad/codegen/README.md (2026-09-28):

# api/cad/codegen/ — text-to-CAD engine (W19)

In hardware, CAD is code. The LLM (route `main`) writes a build123d program, we run it in a sandbox, measure the
result, and feed errors back for self-repair, the way Cursor fixes a compile error. Deterministic parametric
families (`api/cad/families/`) are both the seed the LLM starts from and the fallback when it fails.

```python
from api.cad.codegen import generate_cad, refine_cad, classify, seed_for, LABEL

r = generate_cad(brief, requirements=None, category=None, seed_family=None,       # new model
                 project_id=pid, dims=(L, W, H) | Dimensions | None, colour="#RRGGBB")
r = refine_cad(pid, "make the bin 20% larger")                                     # edit latest model_vN.py
r = generate_cad(brief, previous_code=code, instruction="…", project_id=pid)        # same, explicit
```

`r` = `{status: ok|repaired|fallback|failed, version, code, source, label, category, seed_family, files{step,stl,glb},
urls{…: /files/<pid>/model_vN.*}, code_url (/projects/<pid>/cad/code/N), bbox_mm, volume_mm3, parts[{label, role,
bbox_mm, volume_mm3}], attempts[{n, kind, llm_seconds, run_seconds, error, error_kind}], notes, parent_version, seconds}`.
Files: `model_vN.{py,glb,step,stl,json}` in the project files dir. Versions are never overwritten.

- `classify.py`: brief → `wearable | furniture_child | vacuum | home_robot | irrigation | solar_roof | board |
  lighting | ble_accessory | generic` → (family, variant).
- `sandbox.py`: AST whitelist (imports only build123d/math, no open/exec/eval/getattr/dunders/"_" attributes/file
  I/O), then `python -I -B _runner.py` in a fresh temp dir, clean env (no secrets), rlimits (CPU, AS
  `CODEGEN_MEM_MB`=1280, DATA `CODEGEN_DATA_MB`=640, FSIZE; single-threaded OpenBLAS — tuned for a 1 GB container, see docs/DEPLOY.md), 25 s wall clock kills the process group, macOS Seatbelt (no network, no writes
  outside the temp dir).
- `_runner.py`: child process. Restricted builtins + import guard, calls `build()`, checks solids, exports.
- `routes.py`: `GET /projects/{id}/cad/code/{n}` (files.py does not serve `.py`). Mount with `register(router)`.

Honesty: `LABEL` = "AI-generated CAD (concept level) — geometry measured on the result"; fallbacks carry
`FALLBACK_LABEL` and a note. Tests: `uv run pytest tests/test_codegen.py tests/test_cad_families.py` (LLM mocked).

## Retrieval-augmented prompts (C4, `CODEGEN_RAG=1`, default off)

- `library.py` + `examples/`: 84 sandbox-verified build123d programs (17 family seeds, the generic example, 66 idioms:
  `encl_` enclosures, `form_` revolve/loft/sweep/threads, `mech_` patterns/mirrors/joints), docstring = title,
  description, `tags:`; measured facts in `examples/index.json` (`python -m api.cad.codegen.library --reindex`).
- `retrieval.py`: pure-Python BM25 → up to 4 examples (2 in edit mode) within a 9,000-char budget (5,000 in edit
  mode), seed family excluded, weak matches dropped.
- `engine.py`: when the flag is on — `SYSTEM + RAG_RULES` (verified build123d do/don't list), the examples block
  appended to the generate/edit prompt, `repair_hints(error)` in repair prompts, and `result["rag"]["examples"]`.
  Flag off = prompts byte-identical to before (tested).
- Measured in docs/CAD_BENCH.md (`tests/cad_bench.py`): no gain over the current prompt with `gpt-6-sol`
  (100 % valid first try in both modes), 2.7× prompt tokens → left off. Tests: `tests/test_codegen_rag.py`.

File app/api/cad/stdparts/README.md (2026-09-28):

# api/cad/stdparts/ — standard parts + DFM detail (C1)

**Switch:** `CAD_DETAIL_LEVEL=basic|pro` (default `basic`; read at call time). At `basic` every family, seed program
and GLB is exactly what it was before C1 (golden test `tests/test_c1_stdparts.py::test_basic_is_unchanged`, recorded
from the pre-C1 HEAD). At `pro` the families add real hardware, joints and moulding features.

| module | what |
|---|---|
| `tables.py` | dimension tables (ISO / datasheets) + unit-price Estimates + citations |
| `hardware.py` | `StdPart` constructors: `screw` (pan ISO 14583 / countersunk ISO 14581 / socket ISO 4762), `pt_screw`, `hex_nut`, `washer`, `heat_set_insert`, `dowel_pin`, `wood_dowel`, `wood_screw`, `cam_lock`, `magnet`, `bearing`, `spur_gear`, `tripod_insert`, `fin_box`, `leash_plug`, `gasket` |
| `dfm.py` | rule-applying generators: `screw_boss`, `rib`, `gusset`, `snap_fit`, `uniform_fillet`, `parting_split`, `clearance_hole`, `tap_hole`, `weld_lip`, `gasket_groove` (+ `RULES` with citations) |
| `joints.py` | `screw_joint` (screw + insert / nut / tapped / thread-forming + boss, sized from the tables), `add_parts`, `named`, `material_role`, `std_length` |
| `bom.py` | `bom_lines(parts)`, `bom_items(lines)` → `BOMItem`, `merge_into(spec_items, lines)`, `family_lines(name, params)`, `hardware_names` / `node_extras` (GLB node names + extras) |
| `enclosure.py` | W2 / W17 two-shell products (lamp, boxes, tracker card, wearable pod): `enclosure_details(params)`, `pro_viewer_parts(params, features)`, `joint_for(params)` — in-process only |
| `level.py` | `detail_level()`, `is_pro()` |

A `StdPart` has `.part` (build123d solid in its own frame), `.meta` (kind, role, standard, size, material…) and `.bom`
(part text, standard, `unit_price_usd`, `price_label="estimate"`). `.at(x, y, z, rx, ry, rz)` / `.along(origin,
direction)` place a copy tagged `std_meta`. Geometry is cached per spec and drawn as 16-sided prisms (below the GLB
30° crease angle, so they shade round at ~60 triangles each); threads are not modelled (length / pitch in the meta).

## Dimension tables (all mm)

| part | standard | M2 | M2.5 | M3 | M4 | M5 |
|---|---|---|---|---|---|---|
| socket head dk / k / key | ISO 4762 | 3.98 / 2 / 1.5 | 4.68 / 2.5 / 2 | 5.68 / 3 / 2.5 | 7.22 / 4 / 3 | 8.72 / 5 / 4 |
| pan head dk / k / drive | ISO 14583 | 4.0 / 1.6 / T6 | 5.0 / 2.1 / T8 | 5.6 / 2.4 / T10 | 8.0 / 3.1 / T20 | 9.5 / 3.7 / T25 |
| countersunk dk / k | ISO 14581 (90°) | 4.4 / 1.2 | 5.5 / 1.5 | 6.3 / 1.65 | 9.4 / 2.7 | 10.4 / 2.7 |
| hex nut m / s | ISO 4032 | 1.6 / 4 | 2 / 5 | 2.4 / 5.5 | 3.2 / 7 | 4.7 / 8 |
| washer d1 / d2 / h | ISO 7089 | 2.2 / 5 / 0.35 | 2.7 / 6 / 0.55 | 3.2 / 7 / 0.55 | 4.3 / 9 / 0.9 | 5.3 / 10 / 1.1 |
| clearance fine / medium / coarse | ISO 273 | 2.2 / 2.4 / 2.6 | 2.7 / 2.9 / 3.1 | 3.2 / 3.4 / 3.6 | 4.3 / 4.5 / 4.8 | 5.3 / 5.5 / 5.8 |
| tap drill (d − P) | ISO 2306 | 1.6 | 2.05 | 2.5 | 3.3 | 4.2 |
| heat-set insert OD / L / hole | McMaster-Carr 94459A | 3.6 / 4 / 3.2 | 4.0 / 4 / 3.6 * | 4.7 / 5.7 / 4.0 | 6.3 / 8.2 / 5.6 | 7.1 / 9.5 / 6.4 |
| insert boss OD (2 × hole) | Covestro part design guide | 6.4 | 7.2 | 8.0 | 11.2 | 12.8 |

M1.6: ISO 4762 3.14 / 1.6, ISO 1580 pan 3.2 / 1.0, ISO 7046 countersunk 3.0 / 0.96, ISO 4032 1.3 / 3.2.
\* M2.5 insert interpolated (not in the 94459A table) — Estimate. Values cross-checked against the data tables of
bd_warehouse 0.3.0 (Apache-2.0).

Other parts: bearings ISO 15 (608 = 8 × 22 × 7, 625, 688, 6000, 6001, 6200) · dowel pins ISO 2338 m6 · wood dowels
DIN 68150 (Ø8 × 35) · cam connector Häfele Minifix 15 (Ø15 × 13.5 cam, Ø8 bolt hole, 24 mm edge) · tripod socket
ISO 1222 (1/4"-20 UNC, 5.5 mm min depth) · spur gears ISO 53 (20°, addendum 1·m, dedendum 1.25·m) · NdFeB discs,
fin box, leash plug: catalogue classes. Unit prices: catalogue order of magnitude at ~2,000 pcs, labelled Estimate.

## DFM rules (dfm.RULES)

| generator | rule | source |
|---|---|---|
| `screw_boss(…, "insert")` | hole = insert datasheet hole, OD = 2 × hole, height ≥ insert length + 0.5 | McMaster-Carr 94459A; Covestro *Part and Mold Design* |
| `screw_boss(…, "pt")` | hole 0.8·d, OD 2·d, engagement ≥ 2·d | EJOT DELTA PT design guide |
| bosses | 0.5° outside draft | Protolabs design guide |
| `rib` / `gusset` | thickness 0.6 × wall, height ≤ 3 × wall, 0.5° draft | Protolabs (60 % rule); Covestro |
| `snap_fit` | y = 0.67·ε·L²/h, L ≥ 5·h, ε(PC/ABS) = 2.5 %, 30° lead-in, 90° retention | Covestro *Snap-Fit Joints for Plastics* |
| `uniform_fillet` | r_in ≥ 0.5·t, r_out = r_in + t | Protolabs |
| `clearance_hole` / `tap_hole` | ISO 273 fits, DIN 974-1 counterbores / d − P | ISO 273, DIN 974-1, ISO 2306 |
| `weld_lip` | 90° energy director, height = base / 2 | Branson / Emerson ultrasonic part design |
| `gasket_groove` | depth 0.75·cord (25 % squeeze), width 1.4·cord | Parker O-Ring Handbook ORD 5700 |
| `parting_split` | split on the widest section, 0.3 mm reveal | Protolabs |
| draft | families keep their own draft (W2 1.5°, tapers): pro never removes it | — |

## Families at pro (`# === PRO DETAIL ===` block in each family module)

| family | pro detail |
|---|---|
| drone | body split on its parting line, 4 × M2 into inserts; 8 × M3 socket + nuts clamp the arms; motors on M3 16 × 19 (≥ 22 mm stators) or M2 12 × 12; M5 prop nuts |
| stick_vacuum | motor housing split + 3 radial PT screws into bosses; floor head 4 × PT screws into bosses; snap-fit bin latch + release button |
| home_robot | 6001-2Z bearing per wheel + M5 axle screw + washer; torso → base 4 × M4 into inserts in bosses; rear access panel, 4 × M3 countersunk into inserts |
| camera | bottom plate split off, 4 × M2 countersunk into inserts; 2 × M2 per end cap; ISO 1222 tripod insert |
| smartphone (ODM) | 2 × M1.6 countersunk at the bottom edge into the tapped frame; 6 × M1.6 board screws into tapped midframe bosses |
| irrigation | EPDM perimeter gasket in a face-seal groove, lid 4 × M4 into inserts |
| furniture | 16 beech dowels Ø8 × 35 + 8 Minifix cams at the rail / leg joints, 8 wood screws 4 × 30 into the top |
| board | fin boxes flush in the bottom (replace the basic slabs) + leash plug in the deck — no screws |
| lamp / boxes (W2 0-1) | `enclosure.py`: screws up through W2's floor bosses into inserts in new top-shell bosses (M2 / M2.5 / M3 by footprint) |
| tracker card (W2 slab ≤ 90 × 14) | ultrasonic-weld energy director on the bottom-shell rim, screwless |
| wearable pod (W17) | 2 × M2 into inserts in top-shell bosses |

Placed hardware becomes one GLB node per spec (`"M3 × 12 socket screws ×16"`, role fastener, layer `fasteners`,
extras: standard, size, count, `bom_item_id` = `hwN`, `unit_price` Estimate, DFM rule for features). The spec BOM
lines come from `bom.family_lines(name, params)` → `bom.merge_into(spec_items, lines)` (same `hwN` ids).

## Codegen sandbox

AI programs may `from api.cad.stdparts import <name>` for the names in `SANDBOX_NAMES` only (AST check in
`codegen/sandbox.py`, re-checked by the runner's import guard; `import api…`, star imports and other modules stay
forbidden). The package imports only build123d / math / dataclasses / os at module level. At pro the family seed
code includes its pro block; `PROMPT_SNIPPET` documents the helpers for the system prompt.

## Dependency decision: bd_warehouse not added

bd_warehouse 0.3.0 installs against build123d 0.13 and its fasteners / bearings build, but: `SpurGear` fails
("Edges are disconnected"), a `HeatSetNut` is 90 faces / 0.6 s (knurls) — 8 of them blow the 5 s budget, its fastener
classes are BuildPart-context oriented, and the codegen sandbox needs an auditable pure-build123d module. We vendor the
few parametric parts as our own code (numbers cross-checked against bd_warehouse's CSVs, credited above); no new
dependency, pyproject.toml / uv.lock unchanged.

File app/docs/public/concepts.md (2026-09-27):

# Concepts

## Factory Pack

The Factory Pack is the primitive: a spec package a factory can quote and build without back-and-forth. It contains the structured spec, CAD, BOM with component risk, DFM alerts, certification checklist, estimated landed cost, questions for the factory (EN + CN) and the assumption register.

Every later step consumes it: negotiation starts from it, QC checks against it, financing uses its cost model, logistics uses its landed cost. Each Studio version produces its own Factory Pack. Fetch it with `GET /projects/{id}/factory-pack`.

## Versions and diffs

Every prompt in the Studio creates a **version**. A version records:

- `message` — what you asked.
- `status` — `running`, `done` or `failed`.
- `changes[]` — a typed diff. Each change has an `area` (color, material, shape, dimensions, feature, component, price, markets, requirement, certification, cost), a `label`, `before`, `after` and a `label_kind`.
- `preview` — GLB and render URLs, the CAD program URL (`code_url`), measured dimensions, unit costs, top factories, required certifications.
- `cad_pending` — true while the AI CAD model of the version is generated or edited in the background.

How a refine works: one LLM call turns your message into typed operations (set color, set material, set dimensions, add a component, `regenerate_geometry` for a change of form, ...). Code then applies them deterministically: every value is re-checked and clamped, the CAD is rebuilt, the spec is measured on the new STEP, the BOM is matched to LCSC parts, DFM re-runs, costs and the shortlist are recomputed. The model never invents a measurement.

Restoring a version makes it current. Steps 8-13 and the Factory Pack of the previous current version are discarded (they described another product); Make it rebuilds them.

## The 13 steps in 4 phases

| Phase | # | Step |
|---|---|---|
| **Design** | 1 | Brief |
| | 2 | Industrial design (3 directions) |
| | 3 | CAD + technical spec |
| **Make it manufacturable** | 4 | DFM, components, certification |
| | 5 | Investment (500 / 2k / 10k, tooling, cash, margin, break-even) |
| | 6 | Where and how to produce |
| **Source** | 7 | Factory matching |
| | 8 | RFQ + agent negotiation |
| **Launch** | 9 | Tooling + samples |
| | 10 | Quality control (AQL) |
| | 11 | Logistics + duties |
| | 12 | Financing (cash curve) |
| | 13 | Brand + distribution |

Steps 1-7 are what the Studio keeps current. **Make it** runs 8-13 and assembles the Factory Pack.

## Honesty labels

Every number renders with one label. Hover for its source or assumption.

| Label | Meaning |
|---|---|
| **Measured** | Computed on the CAD (e.g. bounding box from the STEP, wall thickness, draft). |
| **Sourced** | A real price or official rate with a date and URL (LCSC parts, HTS duty rates, Drewry index, PVGIS, standards citations). |
| **Estimate** | An assumption, shown. Mechanical parts, assembly, tooling ranges, certification costs, lead times. |
| **Fictional — demo data** | Invented for the demo: the factory network, quotes, negotiation replies, carrier freight, transit days. |

If a step could not run live it serves a cached example and the app shows a "Cached example" banner (`fallback: true`). A cached example may be a different product.

## Build strategies

The engineering layer picks how a product of its category realistically gets built. All figures (MOQ, entry cost, lead time) are Estimates with stated assumptions.

| Strategy | Meaning | Categories |
|---|---|---|
| **Full design** | You design every part; a factory builds to your CAD and drawings. | furniture (baby), surfboard, lighting, tracker, generic |
| **Module assembly** | You design around bought-in, pre-certified modules (motor + driver, battery pack, radio module, heater + fan). | drone, irrigation, wearable, hair dryer, vacuum, rooftop solar |
| **ODM customization** | Nobody designs these from scratch for a first product: customise an ODM's reference platform. | smartphone, camera, home robot |

The result is the `build_strategy` field of the engineering artifact (`GET /projects/{id}/engineering`); its `strategy` is `full_design`, `module_assembly` or `odm_customization`. It is also shown in the Factory Pack and the Launch Dossier.

## Categories supported

Category packs: wearable, furniture (baby), home robot, vacuum, irrigation, rooftop solar, surfboard, lighting, tracker, **drone**, **hair dryer**, **camera**, **smartphone**, and a generic consumer-electronics pack. Factories can list specialities: a specialist of another category scores 50% on process fit in matching.

## Showcase gallery

`GET /examples` lists recorded examples, complete through Make it. Opening one costs nothing: everything is cached, including Studio versions and AI CAD programs. See [Engineering](/docs/engineering).

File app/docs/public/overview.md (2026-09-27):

# Overview

PhysicalLovableX turns a sentence into a physical product you can see, refine and prepare for manufacturing.

In software, the AI writes code. In hardware, **CAD is code**: the AI writes [build123d](https://github.com/gumyr/build123d) code, runs it in a sandbox, measures the result and repairs its own errors. You see the product in 3D with its unit cost and a factory shortlist, change it by prompting, and press **Make it** to run the rest of the path to a launch package.

## The loop

| Step | What happens |
|---|---|
| **Describe** | One sentence: "A Whoop competitor, screenless, 5-day battery." |
| **See** | The product in 3D, its unit cost at three volumes, and the top factories, on one screen. |
| **Refine** | Prompt changes ("add SpO2 and skin-temperature sensing", "make it pink", "thinner, 8 mm pod", "target retail $149"). Each prompt creates a restorable **version** with a diff: CAD, BOM with real LCSC parts, costs, measured DFM, certifications, shortlist. |
| **Make it** | One action runs factories (via the production MCP), agent negotiation, tooling, QC, shipping and duties, cash plan and brand, and produces the **Launch Dossier** (EN + CN). |

Recorded examples open instantly at no AI cost from the showcase gallery (`GET /examples`). The Studio is the primary interface. The 13 stages behind it are the detailed view of the same project (see [Concepts](/docs/concepts)).

## Recorded timings

Measured live over several runs. Not guarantees, and they vary with load and the product:

- First version: 18-24 s.
- Colour or feature refine: 4-7 s.
- Geometry refine (the AI edits its CAD program): 11-24 s.
- Make it, 13 steps to the Launch Dossier: 54-88 s live; instant, $0 on a recorded showcase.

## What is real, what is demo

Every number in the product carries one label: **Measured**, **Sourced**, **Estimate** or **Fictional — demo data**.

- **Real:** AI-written CAD and its measurements, measured DFM checks, physics checks, LCSC prices and stock (dated snapshot), HTS lines from CBP CROSS rulings, the Drewry freight index, PVGIS solar yield.
- **Fictional and labeled:** the 11 factories, 1 integrator and 3 installers, their capacity, quotes and negotiation replies, carrier freight quotes and transit days.
- **Categories:** wearables, furniture, home robot, vacuum, irrigation, rooftop solar, surfboard, lighting, tracker, drone, hair dryer, camera, smartphone. The build strategy (full design, module assembly or ODM customization) is chosen per category.
- **Generated, not verified:** firmware skeletons are labeled "not compiled or tested".

Details in [Limits](/docs/limits).

## Connect your agent

The production MCP is served over Streamable HTTP at `/mcp`. Use your own token; never paste it into a shared config.

**Claude Code** (from the project's demo guide):

```bash
claude mcp add --transport http physicallovablex-production \
  https://physicallovablex-production.up.railway.app/mcp \
  --header "Authorization: Bearer $MCP_TOKEN"
```

**Claude Desktop** (stdio bridge via `mcp-remote`, needs Node). Edit `claude_desktop_config.json`:

```json
{
  "mcpServers": {
    "physicallovablex-production": {
      "command": "npx",
      "args": ["-y", "mcp-remote", "https://physicallovablex-production.up.railway.app/mcp",
               "--header", "Authorization:${AUTH_HEADER}"],
      "env": { "AUTH_HEADER": "Bearer PASTE_MCP_TOKEN_HERE" }
    }
  }
}
```

**Cursor** and **Codex** (untested): both are MCP clients that accept a Streamable HTTP server URL with a custom header. Point them at `https://physicallovablex-production.up.railway.app/mcp` with header `Authorization: Bearer <token>`. We have not tested these two clients; if your client only speaks stdio, use the `mcp-remote` bridge shown above.

**Any MCP client, no setup** — check the endpoint with curl:

```bash
curl -s https://physicallovablex-production.up.railway.app/mcp \
  -H "Authorization: Bearer $MCP_TOKEN" \
  -H "Content-Type: application/json" \
  -H "Accept: application/json, text/event-stream" \
  -d '{"jsonrpc":"2.0","id":1,"method":"tools/list"}'
```

Full reference: [Production MCP](/docs/production-mcp).

## Where next

- [Quickstart](/docs/quickstart) — first product in the app and through the API.
- [Concepts](/docs/concepts) — Factory Pack, versions, the 13 steps, honesty labels, build strategies.
- [Studio API](/docs/studio-api) — every route.
- [Production MCP](/docs/production-mcp) — the 7 tools.
- [Engineering](/docs/engineering) — category packs, build strategy, physics checks, firmware, prototype path.
- [Limits](/docs/limits) — honest scope.
- [agents.md](/agents.md) — instructions for AI agents.

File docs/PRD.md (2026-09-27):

# PRD — PhysicalLovableX

| | |
|---|---|
| Status | v1.2 — locked for the case study (26/09/2026) |
| Market | US-first founders (FCC first), Chinese factories; EU (CE/UKCA) supported in the certification map |
| Owner | Orphéo |
| Companion docs | `PRODUIT.md` (one-page definition), `PLAN.md` (build and delivery plan), `gtm-harness/context/*` (ICP, positioning, signals) |
| Evidence base | `../02_RECHERCHE/parallel/00_SYNTHESE.md`, `D_unit_economics.md`, `E_usines.md`, `B_concurrence.md`, `../02_RECHERCHE/lecons_inputs.md` |

---

## 1. TL;DR

PhysicalLovableX turns an idea or a working prototype into a manufactured, shipped, ready-to-sell product.

**The experience is a Studio:** describe a product in a sentence, see it in 3D with its cost and top factories, refine it by prompting ("measure heart rate", "make it pink", "thinner, 8 mm pod", "target $149"), then press **Make it** to autofill the rest of the pipeline up to a Launch Dossier (EN + CN). Every prompt creates a restorable version with visible diffs (§8.2). The 13 stages (§8) are the detailed view of the same project.

- **Top layer ("Lovable"):** plain language in → industrial design, CAD, technical spec, investment needed, where and how to produce.
- **Bottom layer ("Alibaba"):** the spec is matched to a curated network of Chinese factories that expose their capacity through a **production MCP**.
- **Our infra:** DFM, factory selection and negotiation, tooling, QC, logistics, financing.

**Positioning:** in software the AI writes code; in hardware, **CAD is code**. The AI writes build123d code, it runs in a sandbox, is measured, and is self-repaired on error. **Honest scope:** concept-level geometry; about 80% of the translation is automated; humans and real factories cover the last 20% (tier 2). A working prototype takes weeks, not minutes.

**The bet (thesis v2):** the bottleneck in hardware is neither design nor the factory. It is the **translation** between the two: making the product manufacturable, choosing components, passing certification, and speaking the factory's language.

**The primitive is the Factory Pack:** a spec package a factory can quote and build without back-and-forth. Every later layer consumes it.

---

## 2. Problem and evidence

| # | Evidence | Source |
|---|---|---|
| 1 | More than 75% of Kickstarter projects deliver late; ~9% never deliver | Mollick, SSRN (2014, 2015) — `00_SYNTHESE.md` facts 1-2 |
| 2 | Hardware demand is growing: Kickstarter Design & Tech pledges +64% in 2025; the most funded campaign ever is hardware (eufyMake E1, ~$47M) | Kickstarter PBC Report 2025 — facts 3-4 |
| 3 | In 30 hand-coded late campaigns, **18 of 24 documented causes** are engineering/redesign, components or certification — not factory access | `gtm-harness/CLAUDE.md` (small, non-random sample) |
| 4 | "We didn't speak [the manufacturer's] language" — Halliday COO | Engadget, 21/07/2026 |
| 5 | US duty now depends on the HTS line: IEEPA duties not collected since 24/02/2026, Section 301 remains, de minimis suspended | CBP, Federal Register — `D_unit_economics.md` |
| 6 | Factory capacity is not digitised: no public machine-capacity API found; what is digitised is discovery and RFQ | `E_usines.md` |
| 7 | Designers are disconnected from manufacturing; DFM is the biggest gap (Diode, Davide Asnaghi) | a16z podcast — `lecons_inputs.md` |

**What the market sells today:** sourcing and matching (Accio $19.90-199/month, agents 5-10%, No Logo 25% flat, Cavela, Haizol), text-to-CAD (Zoo, Backflip, Atech), QC ($268/man-day). **Nobody owns the translation and nobody publishes delivery or defect data** (`B_concurrence.md`).

### 2.1 Market anchors (verified) and sizing logic

| Anchor | Figure | Source |
|---|---|---|
| Kickstarter, all categories, 2025 | 20,374 funded projects, $891.8M pledged; Design & Tech pledges +64% vs 2024 | Kickstarter PBC Report 2025 |
| Kickstarter Technology + Design, Q1 2026 | 314 funded campaigns, $67.23M | TCF Q1 2026 (third-party, medium) |
| US imports of goods from China, 2025 | $308.4B | BEA, 19/02/2026 |
| Sourcing agent fee benchmark | 5-10% of order value | Dragon Sourcing |

**Sizing logic (to validate, not a claim):** revenue pool = hardware launches per year × average production order × take rate. Crowdfunding is only the **visible, datable** entry point (public ship dates make the pain measurable); the larger pool is DTC and Amazon brands importing physical products from China. No verified size exists for China sourcing agents (`C_marche.md`, "Manques").

---

## 3. Thesis and what would kill it

**Thesis v2:** founders lose months and margin between "the prototype works" and "the factory ships good units", because nobody translates the product into manufacturable, certifiable, quotable form.

**Kill criteria (tested by discovery, see §3.1 and §20):**
- Founders say the delay was tolerable and they would not pay to remove it (vitamin, not painkiller) — `00_SYNTHESE.md` §2.1.
- Founders say the blocker was cash or demand, not translation.
- Founders already have a trusted "contact in Shenzhen" who does the translation well.

### 3.1 Riskiest assumptions — test, metric, decision

| # | Assumption | Test | Metric | Decision rule |
|---|---|---|---|---|
| A1 | The blocker is translation (DFM, components, certification, factory language), not factory access | 30 discovery messages → calls | Share of founders naming a translation-type blocker first | Majority → keep thesis v2; minority → reposition on the blocker they name |
| A2 | It is a painkiller: founders pay to remove it | Ask what they paid third parties and what they would pay for a committed landed price | Named spend + willingness to pay | No spend and no willingness → drop tier 2 pricing, keep tier 1 as data play |
| A3 | Founders will hand over a real product | Offer a free human-reviewed Factory Pack to call participants | Packs accepted | < 3 accepted in lighthouse → rethink wedge |
| A4 | Factories will share capacity through the MCP | Onboard 3 factories manually in lighthouse | Capacity profiles completed; RFQ-to-quote time | Refusal → RFQ-only flow, capacity inferred from quotes |

---

## 4. Users

### 4.1 Primary — Segment A: funded hardware creator (user = buyer = founder)
- Small team, first or second product, no own factory, money already pledged, public ship date.
- Examples from our list: The Minimal Phone, Pilet, Wordrunner, AIVELA, SwiftShape, Circular Ring 2, GAMR (`03_DISCOVERY/comptes.csv`).
- **Job to be done:** "Get my working prototype produced at the promised price and quality, on a date I can tell my backers."

### 4.2 Secondary — Segment B: DTC brand adding a physical product
- Weaker hypothesis: no documented production problem in our 4 DTC accounts (`icp.md`).

**Early Customer Profile vs ICP (27/09):** the early customer is 4.1 narrowed to late crowdfunded consumer-electronics founders (beachhead scoring 26/30, access ×2; `icp.md` "Beachhead scoring", deck A8, my scoring = hypothesis); the later ICP is funded hardware startups (prototype, no campaign) and 4.2 brands, once one case is documented end to end.

### 4.3 Top of funnel — idea-stage creator
- Plain-language idea, no prototype. Served free (land grab), feeds data and future Segment A.

### 4.4 Supply side — factory
- SME factory in China selling through agents, trading companies, 1688, Canton Fair (`E_usines.md`).
- **Job to be done:** "Receive qualified, complete RFQs that I can quote fast, and fill idle capacity."

**Not a target:** established manufacturers with their own chain (Anker/eufyMake, Creality, AYANEO) — high urgency, low fit.

---

## 5. Goals and non-goals

### Goals — demo (this week)
- G1. A reviewer types any product idea and reaches an exportable Factory Pack in under 5 minutes.
- G2. The full concept is visible end to end: 13 stages, from brief to brand, with a founder view and a factory view.
- G3. Every number shows its assumption; every simulated element is labeled.
- G4. The demo never crashes in front of the jury.

### Goals — business (after the case, for Hexa)
- G5. Prove founders will hand over a real product for production (lighthouse, tier 2).
- G6. Publish the first on-time and defect rate in the category.

### Non-goals
- Photorealistic rendering or advanced CAD (commodity).
- A real marketplace, payments, real logistics booking.
- Automating the last 10%: humans review every Factory Pack before it reaches a real factory.
- Paid acquisition (see `lecons_inputs.md`, Lovable).

---

## 6. Success metrics

| Level | Metric | Target |
|---|---|---|
| Demo | Time from prompt to wow screen and Factory Pack (auto-run mode) | < 5 min live, < 30 s cached |
| Demo | Test prompts completed without crash (see Appendix A) | 10/10 |
| Activation | **Factory Pack exported** (the "wow moment") | North-star input |
| Quality | Factory Packs signed off by a human engineer before reaching a real factory | 100% (tier 2) |
| Conversion | Factory Pack → RFQ sent to real factories (tier 2) | Tracked from lighthouse |
| North star | **Units delivered on time and within spec** | Published publicly from run 1 |
| Trust | On-time rate, defect rate, rejected lots | Published per run |
| Supply | Factories with capacity registered in the MCP; RFQ-to-quote time | Tracked from lighthouse |

No LTV targets: meaningless at this stage (Elena Verna, `lecons_inputs.md`).

---

## 7. Product principles

1. **Translation over generation.** Design is the input; the value is what makes it manufacturable.
2. **Show the assumption.** No number without its source or hypothesis, one click away.
3. **Label the fiction.** "Fictional — demo data" and "Estimate" are visible, never hidden.
4. **Humans on the last 10%.** AI drafts; an engineer signs before a real factory sees it.
5. **One artifact, many consumers.** Every stage reads from and writes to the project; the Factory Pack is the spine.
6. **Wow first.** The first screen after the prompt must show the product, its cost and a factory shortlist.

---

## 8. Scope — the Studio and the 13 stages

The product has one project and two ways to see it. The **Studio** (§8.2) is the primary interface: prompt, see, refine, Make it. The **13 stages** below are the detailed view of the same project: every Studio action reads and writes the same stage artifacts. Stages are grouped in four phases, as in the UI: **Design** (Brief · Design options · 3D model & spec) · **Make it manufacturable** (Manufacturability check · Costs & investment · Production plan) · **Source** (Factory shortlist · Quotes & negotiation) · **Launch** (Tooling & samples · Quality control · Shipping & duties · Cash plan · Brand & listing).

### 8.0 The 13 stages (detailed view)
Each stage: reads the project state, writes one artifact, has a cached fallback, and shows a status (not started / draft / validated).

| # | Stage | Input | Output (artifact) | Key requirements | Acceptance criteria | Demo |
|---|---|---|---|---|---|---|
| 1 | **Brief** | Prompt, or prototype description + pasted BOM | `brief.json` | Two modes; ≤5 clarifying questions (markets, volume, target price, battery, wireless) | Both modes produce a valid brief; questions skippable | Real |
| 2 | **Industrial design** | Brief | 3 design directions | Parametric variants (dimensions, shape, material); user picks one | 3 distinct directions rendered; choice persisted | Real |
| 3 | **CAD + spec** | Chosen direction | `spec.json`, STEP, STL | build123d enclosure; GLB viewer (`<model-viewer>`, fallback three.js); dimensions, materials, electronics block diagram | STEP downloads and opens; viewer rotates; spec editable | Real |
| 4 | **DFM** | Spec + BOM + CAD | `dfm.json` | **Measured** geometry checks on the CAD (draft angles, undercuts, projection along pull direction — adapted from the text-to-cad DFM skill) + AI-reviewed alerts (wall thickness, tolerances, assembly); risky components (EOL, single source, lead time, stock) with alternatives; certifications by market (CE, FCC, UKCA, battery transport) | ≥3 relevant alerts per test case; every alert has a fix and a cited rule; each alert labeled **"Measured"** or **"AI-reviewed"** | Real |
| 5 | **Investment** | Spec + BOM + DFM | `costs.json` | Electronic BOM lines matched to **real LCSC/JLCPCB parts** (price + stock, snapshot date); mechanical parts and assembly estimated; unit cost at 500 / 2,000 / 10,000; tooling; certification cost; total cash needed; margin at target price; break-even units | Formulas in §11; each line labeled **"LCSC price, <date>"** or **"Estimate"** with its assumption | Real (partly sourced) |
| 6 | **Production plan** | Spec + costs | `production_plan.json` | Process per part (injection, CNC, sheet metal, PCBA), region, lead times | One process per part with reason | Real |
| 7 | **Factory matching** | Factory Pack | Ranked shortlist | Query production MCP; score on process fit, MOQ, certifications, load, lead time | Top 3 with explicit reasons | Simulated network |
| 8 | **RFQ + negotiation** | Factory Pack + shortlist | Quotes, transcript, selected factory | Agent sends RFQ via MCP; 3 factory agents reply; negotiation agent compares and counters (price, MOQ, lead time, payment terms); user approves | Transcript visible; final terms stored | Simulated |
| 9 | **Tooling + samples** | Selected quote | Milestone plan | T0 / T1 / golden sample, dates, 30/70 payment schedule | Timeline rendered; dates consistent with lead times | Generated plan |
| 10 | **QC** | Spec + DFM | Inspection plan | AQL level, critical/major/minor defects derived from spec, pre-shipment inspection cost ($268/man-day benchmark) | Every critical defect maps to a spec line | Generated plan |
| 11 | **Logistics** | Costs + quote | Final landed cost | Incoterm, sea vs air, duties by assumed HTS (Section 301 note), broker/port, warehouse | Landed cost reconciles with stage 5 | Simulated rates |
| 12 | **Financing** | Milestones + costs | Cash curve | Cash out per milestone; options: preorders, crowdfunding, inventory financing | Curve sums to total cash of stage 5 | Generated plan |
| 13 | **Brand + distribution** | Brief + spec | Brand kit | Name options, packaging spec, landing copy, Shopify/Amazon listing draft | All four present | Real |

**Final export: Launch Dossier (PDF)** — Factory Pack (EN + CN) + outputs of all stages + assumption register.

### 8.1 The Factory Pack (primitive) — required contents
1. Product summary and target markets
2. Structured spec (dimensions, materials, finishes, tolerances)
3. CAD (STEP) and drawings
4. BOM with component risk and alternatives
5. DFM alerts and resolutions
6. Certification checklist by market
7. Target quantities and cost estimate
8. Questions for the factory (EN + CN; CN is machine-translated and labeled "to be reviewed by a native speaker")
9. Assumption register

---

### 8.2 Studio: prompt-to-product loop

**Principle:** the founder never fills a form to get a first product, and never re-runs a pipeline by hand to change one. They talk to the product; the pipeline re-computes.

| Step | What the user does | What the system does | Stages touched | Status |
|---|---|---|---|---|
| Describe | Types one sentence (idea mode) or pastes a BOM (prototype mode) | Brief, first design direction, CAD, DFM, costs, production plan, factory shortlist; shown as 3D + unit cost at 3 volumes + top-3 factories | 1-7 | Real (shortlist fictional) |
| Refine | Types a change: add a sensor, change a colour, change a dimension, change a target price | Interprets the prompt as a spec change, creates a **new version**, re-runs only what the change invalidates, shows the diff | 3-7 as needed | Real (target: see below) |
| Restore | Clicks an earlier version | That version becomes current; later versions stay in the timeline. Stages 8-13 and the Factory Pack are cleared and **Make it must run again** | all | Real |
| Make it | One click | Autofills stages 8-13: RFQ through the production MCP, agent negotiation (auto-approval flagged), tooling, QC, logistics and duties, cash plan, brand; assembles the Factory Pack and the Launch Dossier | 8-13 | Simulated (factories, quotes, freight) + generated plans + real brand kit |

**A version** = a full snapshot of the project (spec, CAD, BOM, costs, DFM, certifications, shortlist) plus the prompt that created it. Restoring never deletes later versions, but it clears stages 8-13 and the Factory Pack (they belong to the version they were built from), so Make it runs again after a restore or a refine.

**The diff** shown after each prompt lists what changed, each with its label:
- **CAD** rebuilt (dimensions and features, **Measured** on the new model);
- **BOM** lines added, removed or swapped, electronic lines with the real LCSC part number, price and stock (**Sourced**, snapshot date);
- **Costs**: unit cost at 500 / 2,000 / 10,000, cash needed, margin at the target price (delta vs the previous version);
- **DFM**: alerts opened or closed, re-measured on the new CAD (**Measured** / AI-reviewed);
- **Certifications**: rows added or removed in the certification map by market;
- **Factory shortlist**: reordered or changed factories and why (**Fictional — demo data**).
A prompt that changes nothing in a category says so ("no change"); the diff is never padded.

**Make it and auto-approval.** Autofill takes the decisions a human would take with sensible defaults, notably approving the negotiation agent's recommended quote. On screen (stage 8) the approval reads **"Auto-approved (autofill mode)"** with a **"Change factory"** action. The Launch Dossier carries the assumption `a8_autofill`: "Auto-approved in autofill mode — review and change the selected factory before any real order". The user can reopen any stage and change it.

**Performance (measured).** Ranges are from several live runs through the UI; single values are marked "one run".
| Item | Value | Status |
|---|---|---|
| First version (v1), live | 18-24 s (AI-written CAD ≈ 23 s in the background) | **Measured**, several runs |
| Stages 1-7, live AI, 10 PRD prompts | 56-76 s (≈ 1 min) | **Measured** (`tests/results/20260926-203730.md`) |
| Colour or feature refine | 4-7 s (≈ $0.01 each in one run) | **Measured**, several runs |
| Geometry refine (the AI edits its CAD program) | 11-24 s | **Measured**, several runs |
| "Make it pink" concept render | arrived 16 s after the refine | **Measured**, one run |
| Restore a version | 1.8 s | **Measured**, one run |
| Make it: 13 steps to the Launch Dossier, live | 54-88 s (≈ $0.34 in one run) | **Measured**, several runs |
| Text-to-CAD generation | ≈ 28-34 s | **Measured**, 7 live prompts |
| Cached example, opening a stage | ≈ 1-2 s | **Measured** (QA report) |
| Make it on a recorded showcase (7 of 11 are 13/13) | instant, $0 | **Built** (W21) |

**Fallbacks.** Every Studio step keeps the platform rule (§12): schema validation, one retry, then the cached fixture with a visible "Cached example" banner. If a refine prompt cannot be applied, a version card with status **failed** and a plain-language error appears in the timeline, and the previous version stays current ("vN is still the current product"). Live AI down: the cached desk-lamp example (complete, stages 1-13) and the factory portal remain fully usable.

**Not in scope:** free-form CAD editing beyond parametric changes; changes that need a new mechanism or a different product category (the Studio says so and suggests a new project); multi-user editing.

### 8.3 Text-to-CAD: the AI writes the CAD

CAD is code (build123d). Instead of picking a template, the AI **writes the CAD program** for the product, which is executed in a sandbox and then measured on the resulting solid. On an execution or geometry error, the error is fed back and the AI repairs its code (like a coding agent on a compile error). The code is shown in a "CAD code" tab. Parametric families (board, furniture, stick_vacuum, home_robot, irrigation, solar_array, wearable_band, ring) are used as seeds and as fallbacks when generation fails.

| Item | Result | Status |
|---|---|---|
| Live prompts producing a recognisable product | 7/7 (surfboard, changing table, home robot, stick vacuum, irrigation kit, rooftop solar, vacuum edit v1→v2) | **Measured** |
| Self-repairs needed | 1 in 7 | **Measured** |
| Time per generation | ≈ 28-34 s | **Measured** |
Scope: **concept-level geometry** to reason about dimensions, fit, mass and cost. It is not production-tooled CAD; a human engineer reviews before a real factory sees it (§7, principle 4).

### 8.4 Engineering layer

- **Category packs:** 10 packs, each with the applicable standards and verified citations (used by the certification map and by DFM).
- **Physics checks on the measured CAD**, each returning pass / warn / fail with its inputs: tip-over angle, board volume in litres and buoyancy, battery life from the power budget, vacuum air watts, irrigation pressure, and solar yield from PVGIS (**Sourced**; e.g. Biarritz, 35 m² → 5.59 kWp, 6,860 kWh/yr).
- **Electronics architecture and power budget** per product.
- **Firmware skeleton** (Zephyr BLE or Arduino Wi-Fi), generated and labeled **"not compiled or tested"**.
- **Prototype path:** parts, cost and time to a first prototype (e.g. kitesurf wearable: $317, 4 weeks).
- **Non-factory supply:** rooftop solar routes to certified installers (**Fictional — demo data**) instead of factories.

### 8.5 Build strategy and showcase (built, W21)

- **Build strategy auto-selected** per product, with the honest industrial path: **full design** (furniture, board, lamp, tracker), **module assembly** (drone, irrigation, wearable, hair dryer, vacuum), **ODM customisation** (smartphone, camera, home robot). New categories: drone, hair dryer, camera, smartphone.
- **Showcase gallery:** 11 recorded examples opening instantly at no AI cost. Complete through Make it (13/13): whoop_kitesurf, changing_table, stick_vacuum, irrigation_biarritz, solar_biarritz, surfboard_beginner, drone_follow. Start-only: home_robot, hair_dryer, instant_camera, minimal_phone.
- **Drone checks:** thrust-to-weight, hover time, and EU class C0/C1/C2 (**Sourced** from EUR-Lex).

## 9. Two views

- **Founder app:** project dashboard, stage sidebar (13), timeline from brief to delivered, status per stage, "Export Launch Dossier".
- **Factory portal:** a fictional factory logs in, sees its capacity profile (processes, MOQ, certifications, lead times, current load), and the RFQs received. This makes the two-sided "Alibaba layer" visible.

---

## 10. Production MCP — specification

Local MCP server. All data fictional in the demo.

| Tool | Caller | Input | Output |
|---|---|---|---|
| `register_capacity` | Factory | processes[], materials[], moq, certifications[], lead_time_days, monthly_capacity, current_load_pct | factory_id |
| `search_capacity` | Platform | process, material, quantity, certifications_required[], deadline | ranked factories + reasons |
| `get_factory_profile` | Platform | factory_id | profile, audit notes, past performance (fictional) |
| `request_quote` | Platform | factory_id, factory_pack_id, quantities[] | rfq_id |
| `submit_quote` | Factory agent | rfq_id, unit_price per tier, tooling, moq, lead_time, payment_terms, exceptions[] | quote_id |
| `counter_offer` | Platform agent | quote_id, proposed changes, rationale | new quote version |
| `accept_quote` | Platform (after user approval) | quote_id | order draft |

**Transport (built):** the same 7 tools are served over HTTP at `/mcp` on the API (Streamable HTTP, JSON), in the same process and store as the web portal, with Bearer-token auth (`MCP_TOKEN`). Any MCP client (Claude Code, Claude Desktop through `mcp-remote`, a ChatGPT connector, a script) can use it; setup in `mvp/docs/MCP_DEMO.md`. Scripted proof: a factory agent registers "Tidewater Wearables (fictional)", which then appears in the web portal and ranks #1 (96/100) for "LSR silicone + PCBA, 2,000 units"; a buyer agent then requests a quote for 500 / 2,000 / 10,000. All factories stay fictional.

**Why MCP:** any agent (ours, Claude, ChatGPT, a buyer's own agent) can query capacity in the same way — "Waniwani for industrial capacity". Research shows capacity data does not exist publicly (`E_usines.md`): the MCP must **create** it through factory onboarding, not aggregate it.

---

## 11. Cost and landed-cost model

**Landed cost per unit** = FOB + freight + insurance + duties (HTS + Section 301 where applicable) + broker/port + 3PL + agent/platform fee + QC + tooling amortisation (`D_unit_economics.md`).

| Parameter | Default assumption | Source |
|---|---|---|
| Simple injection mold (1 cavity) | $1,000-3,000 | Zetar Mold 2026 (vendor, medium) |
| Complex multi-cavity steel mold | $30,000-100,000 | idem |
| Sourcing agent benchmark | 5-10% of order | Dragon Sourcing |
| Pre-shipment inspection | $268 per man-day | V-Trust |
| Section 301 | 7.5% / 25%+ by HTS line — shown as assumption | CBP / White House |
| IEEPA | not collected since 24/02/2026 | CBP CSMS 67834313 |
| De minimis | suspended | Federal Register 24/06/2026 |
| Section 122 | 10% temporary surcharge announced Feb 2026 for 150 days; current status to verify — shown as a toggle | CBP CSMS 67844987 |
| Volume curve | unit cost falls with tier (500 → 2,000 → 10,000); factor exposed as editable assumption | Demo assumption |
| Electronic components | Real unit prices and stock from the JLCPCB/LCSC basic & preferred parts snapshot (daily-updated, MIT); live lookup via jlcsearch where available | [CDFER/jlcpcb-parts-database](https://github.com/CDFER/jlcpcb-parts-database), [jlcsearch](https://github.com/tscircuit/jlcsearch) |
| HTS line (cached examples) | Set by hand from the official USITC HTS and cited; live lookup out of scope | [hts.usitc.gov](https://hts.usitc.gov/) |

Deterministic Python computes the numbers; the LLM only proposes BOM lines and assumptions. Every output lists its assumptions.

---

## 12. AI system

| Agent | Role | Model use |
|---|---|---|
| Spec copilot | Brief → structured spec; clarifying questions | LLM, JSON schema output |
| Design generator | 3 parametric directions → build123d parameters | LLM → deterministic CAD |
| DFM reviewer | Measured geometry checks first, then AI-reviewed alerts, component risks, certifications | Deterministic geometry checks (build123d/OCCT) + LLM with checklist prompt; LLM never overrides a measurement |
| Cost engine | BOM → costs | LLM proposes BOM lines; Python matches electronic lines to the LCSC snapshot and computes all maths |
| Matcher | Scores factories from MCP | Deterministic scoring |
| Negotiation agent | Compares quotes, counters, recommends | LLM with policy (price, MOQ, lead time, terms) |
| Factory agents (×3, fictional) | Reply to RFQs with personalities (cheap/slow, fast/expensive, balanced) | LLM |
| Planner | Tooling, QC, logistics, financing plans | LLM + Python checks |
| Brand agent | Names, packaging, copy, listing | LLM |

All LLM calls: JSON schema validation, retry once, then cached fallback.

---

## 13. Data model (SQLite)

`Project`(id, name, mode, created_at, status) · `Brief` · `DesignOption` · `Spec` · `BOMItem`(part, qty, unit_cost_est, risk, alternative) · `DFMIssue`(severity, description, fix) · `Certification`(market, standard, cost_est, lead_time) · `CostModel`(tier, unit_cost, tooling, landed_cost, assumptions_json) · `Factory`(fictional=true, profile_json) · `RFQ` · `Quote`(version) · `NegotiationTurn` · `Milestone` · `QCPlan` · `LogisticsPlan` · `FinancingPlan` · `BrandKit` · `Artifact`(stage, path, type).

---

## 14. UX — key moments

1. **Landing:** hero ("Describe it. See it. Refine it. Make it."), the four-phase flow, two buttons: "I have an idea" / "I have a prototype".
2. **Describe → first result:** one sentence in; a progress indicator on every step; the **wow screen** appears with the product in 3D, unit cost at 3 volumes and top-3 factories in one view. Stages 2-7 run with sensible defaults (first design direction, default volumes) and remain editable.
3. **Refine by prompting:** a prompt box under the product; a "CAD code" tab shows the AI-written build123d program with line numbers (when the version has one), an "Engineering" tab shows the checks (pass / warn / fail), power budget, standards and prototype path, and a "Firmware" tab offers the generated skeleton as a zip ("not compiled or tested"). After each prompt, a new version appears in the version list and **diff chips** show what changed (CAD, BOM, cost, DFM, certifications, shortlist), with the cost delta. Any version can be restored.
4. **Make it:** one button. Progress shows stages 8-13 as they complete; auto-approved decisions are marked.
5. **Detailed view:** the 13 stages in four phases, for anyone who wants to inspect or override a stage. Includes the negotiation transcript (agent-to-factory messages, side-by-side quotes, the recommendation) and the timeline with the cash curve underneath.
6. **Export:** Launch Dossier PDF (EN + CN).
7. **Showcase gallery:** 11 recorded examples (7 complete through Make it), instant.
8. **Reset demo:** one button restores the two cached projects.

## 15. Non-functional requirements

- **Robustness:** every stage has a cached fallback; no unhandled exception reaches the UI; two fully cached examples (magnetic desk lamp, simple electronic accessory) run offline.
- **Latency:** each live stage < 30 s; progress indicator on every call.
- **Cost guard:** max tokens per request; max requests per session; key only server-side.
- **Security:** `.env` never committed; password-protected deployment via env var; no real personal data.
- **Models:** model-agnostic client (OpenAI-compatible, via OpenRouter) with three routes from env: `LLM_MAIN_MODEL` (reasoning), `LLM_FAST_MODEL` (light steps, factory agents), `LLM_CN_MODEL` (Chinese Factory Pack, a Chinese-native model). Never hard-coded. Product point: the infra routes each task to the best model; production use with real founders' unreleased designs requires an IP/data-residency policy per provider.
- **Honesty:** four labels, used consistently on screen and in the PDF — **Measured** (computed on the CAD), **Sourced** (real price or official rate, with date), **Estimate** (assumption shown), **Fictional — demo data** (factories, quotes, freight). README lists real vs simulated.

---

## 16. Real vs simulated (demo)

| Real (live AI + code) | Simulated (labeled) |
|---|---|
| Brief, design, CAD/STEP/GLB, spec, versions and diffs, **measured DFM checks**, certification map, **real LCSC component prices and stock** (dated snapshot), **HTS line from CBP CROSS rulings** and duty rates with their cited headings, **Drewry WCI** freight index as the base of the sea-freight lane, eCFR citations, cost engine, production plan, brand kit, plans for tooling/QC/financing, the negotiation logic (real agent loop over the MCP tools) | The 15 fictional partners (11 factories, 1 integrator, 3 installers), their capacity, quotes and negotiation replies; carrier freight quotes and transit days; factory past performance; the auto-approval in Make it (a real code path, but the decision stands in for a human) |

Also real: the AI-written CAD code and its measurements, physics checks on the measured CAD, PVGIS solar yield (Sourced). Simulated or labeled: the firmware skeleton is generated and **not compiled or tested**; certified solar installers are fictional. Estimates stay estimates: mechanical parts, assembly, tooling ranges, certification costs and lead times, and the classification precedent itself (confirm with a broker) are labeled **Estimate** on screen.

## 17. Business model and GTM link (hypotheses)

| Tier | Offer | Role in GTM | Price hypothesis |
|---|---|---|---|
| 1 — Self-serve | Idea/prototype → Factory Pack, free | Land grab, data, wow moment | Free (freemium = marketing budget) |
| 2 — Accompanied production | Human-reviewed pack, RFQ, negotiation, samples, QC, committed landed price | Lighthouse: 10 founders with proven demand | Commission on the production order (benchmarks: agents 5-10%, No Logo 25%) |
| 3 — Infra | Financing, logistics, reorders, MCP access for third-party agents | Venture scale | Take rate + financing margin |

Pricing is not optimised at this stage; it is a hypothesis to test in lighthouse conversations (variant to test: pay at validated milestones — factory quote, sample, order). Lighthouse founders are non-paying customers until proof of value; we test willingness to pay (amount already paid to intermediaries, W5 deposit/LOI), we don't optimise price. Go-to-market = 1 ICP + 1 offer + 1 channel (late funded electronics founders + free human-reviewed Factory Pack + signal-based founder outreach); one complete case (prototype → Factory Pack → factory quote) becomes the main sales artifact in W5-W6 before widening.

**Why venture-scale despite low frequency:** a founder launches a product every 12-18 months (unlike Lovable's daily use), but each production run is $20k-200k of order value; retention comes from reorders and new SKUs (`lecons_inputs.md`).

**Entry wedge:** "I have a prototype" mode for Segment A — founders with a working prototype and money pledged.

**One category first (decided 27/09):** consumer electronics (PCB + enclosure: wearables, minimalist phones, small devices). 28 of the 36 drafted discovery accounts are in it (`03_DISCOVERY/envoi/A_ENVOYER.md`; 9 of the top 10 in `icp.md`), and it is where real LCSC parts and FCC / certification checks add most. The Studio stays broad; the lighthouse, the outreach and the first factories come from this one category. Focus choice, not a finding: revisit after campaign 01 (`GTM_Lessons_PhysicalLovableX.md`: Walsh, Holly Chen, Klaviyo fiches).

---

## 18. Roadmap

| Phase | When | What | Exit criteria |
|---|---|---|---|
| 0 — Demo | This week | This PRD, 13-stage demo | Case study delivered |
| 1 — Lighthouse | 90 days | 10 founders in consumer electronics, concierge tier 2, 3 real factories onboarded by hand through ecosystem intermediaries (sourcing agents, QC inspectors, 3PLs, CAD freelancers), not cold RFQ | ≥3 production runs started; first published on-time/defect rates; PMF signal per side: founders start a second design or hand a pack to a factory, factories return a quote from the pack without back-and-forth (target ≤5 working days, hypothesis) |
| 2 — Land grab | 3-9 months | Self-serve tier 1 public; community; makerspace "build a product" weekends | Factory Packs exported per week; pack → RFQ conversion |
| 3 — Infra | 9-24 months | Real production MCP network, financing, logistics; open Factory Pack format | Factories self-register capacity; third-party agents query the MCP |

---

## 19. Risks and mitigations

| Risk | Mitigation |
|---|---|
| Delay is tolerated → vitamin | Discovery kill criteria (§3); target founders with public pressure (refund sites, complaints) |
| Sourcing commoditised (Accio, agents, No Logo) | Compete on translation + committed price + published outcomes, not on price |
| Accio owns the supply side | MCP open to any agent; own the spec layer, not the supplier list |
| Guarantee costs money | Price the guarantee in the commission; start with simple products |
| Factories won't share capacity | Onboard manually in lighthouse, introduced by intermediaries who already hold factory trust (sourcing agents, QC inspectors, 3PLs, CAD freelancers) rather than cold RFQ; RFQ flow creates the data |
| Founder-market fit (the founder has not shipped hardware) | Advisor who has run a production + the engineer who signs every pack |
| Design confidentiality / IP (factories; third-party LLMs) | NDA with every factory before it sees a pack; IP / data-residency policy per LLM provider before production use (§15) |
| One category too narrow | The Studio stays broad (solar, drones, lamps still run); only the lighthouse is focused; revisit after campaign 01 |
| AI errors in DFM/certification | Human engineer signs every pack before a real factory sees it |
| Tariff volatility | HTS-level duty engine, assumptions visible, updated per run |

---

## 20. Open questions for discovery

1. When did you realise delivery would slip, and what blocked first: design, components, certification, or factory?
2. What did you pay third parties (agents, engineers, QC), and would you pay for a committed landed price?
3. What does your daily exchange with the factory look like?
4. What would you do differently first?
5. Do you have a next product, and when?

Results go to `03_DISCOVERY/verbatims.md`; this PRD is updated after every 5 conversations.

---

## Appendix A — Test prompts (all must pass)
1. Magnetic rechargeable desk lamp, minimalist, sold €89 (cached)
2. Bluetooth tracker card for wallets (cached — the "simple electronic accessory")
3. Smart dog bowl that weighs food, Wi-Fi
4. Mechanical keyboard with hot-swap switches, aluminium case
5. Portable espresso maker, manual pump, no electronics
6. Kids' audio player with NFC figurines
7. Smart ring measuring sleep (prototype mode, pasted BOM)
8. E-ink phone, minimalist (prototype mode)
9. Bike light with brake detection
10. Desktop air-quality monitor with CO2 sensor

### Studio scenario (demo and video) — "the Whoop competitor"
Start (idea mode): *"A Whoop competitor: a screenless wrist-worn band, 5-day battery, tracks sleep and strain."*
Then, one prompt at a time, each creating a version:
1. *"Add SpO2 and skin-temperature sensing."* → BOM gains sensor parts with their LCSC numbers, prices and stock (Sourced); cost and DFM re-measured; the certification map changes. (Not "add heart-rate": a Whoop-class band already has it, so the diff would show nothing.)
2. *"Make it pink."* → finish and colour change; cost delta small or nil, and the diff says so; a concept render arrives later.
3. *"Thinner, 8 mm pod."* → the AI edits its CAD program (visible in the "CAD code" tab); measured dimensions and DFM re-measured (8.0 mm in one run); alerts may open.
4. *"Target retail $149."* → margin, break-even and shortlist re-computed against the new price.
5. **Make it** → stages 8-13 autofilled; Launch Dossier exported.
Measured live over several runs: start 18-24 s; colour and feature refines 4-7 s; geometry refines 11-24 s; Make it 54-88 s. One-run values: restore 1.8 s, Make it ≈ $0.34, refine ≈ $0.01, "thinner, 8 mm pod" measured 8.0 mm, pink render 16 s later.
Acceptance: each prompt yields a new version with a diff and can be restored; no crash; every number labeled. Certification and DFM diff lines per prompt are confirmed on the live build before the demo (`mvp/docs/DEMO_SCRIPT.md`).

## Appendix B — Build accelerators (open source)
- [earthtojake/text-to-cad](https://github.com/earthtojake/text-to-cad) (MIT) — CAD agent skills, STEP/STL/GLB export, viewer; DFM skill ([PR #391](https://github.com/earthtojake/text-to-cad/pull/391), merged 21/09/2026) → stage 3-4.
- [CDFER/jlcpcb-parts-database](https://github.com/CDFER/jlcpcb-parts-database) (MIT) and [jlcsearch](https://github.com/tscircuit/jlcsearch) (MIT) → stage 5.
- three.js GLTFLoader; fallback [occt-import-js](https://github.com/kovacsv/occt-import-js) → 3D viewer.
- [USITC HTS](https://hts.usitc.gov/) → stage 11.
- Optional: [build123d-mcp](https://github.com/pzfreo/build123d-mcp), [Vercel Next.js FastAPI starter](https://vercel.com/templates/next.js/nextjs-fastapi-starter).
- Q3 evidence only: [Text2CAD](https://huggingface.co/datasets/SadilKhan/Text2CAD), [CAD-Coder](https://huggingface.co/datasets/gudo7208/CAD-Coder), [Text-to-CadQuery](https://github.com/Text-to-CadQuery/Text-to-CadQuery).

## Appendix C — Sources
See `../02_RECHERCHE/parallel/00_SYNTHESE.md` (verified facts with URLs), `D_unit_economics.md`, `E_usines.md`, `B_concurrence.md`, `../02_RECHERCHE/concurrents.md`, `../02_RECHERCHE/lecons_inputs.md`.

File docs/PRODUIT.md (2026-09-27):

# PhysicalLovableX — product one-pager

Full detail: `PRD.md`. This page is the summary; if they differ, PRD.md wins.

## Narrative
Hardware doesn't ship late because of design or because of the factory. It ships late because nobody translates the idea into what the factory can build. We do that translation.

**Pitch line:** From idea or prototype to 1,000 units shipped, without speaking the factory's language.
**Product line:** Describe it. See it. Refine it. Make it.

## Positioning
In software the AI writes code. In hardware, **CAD is code**: we let the AI write it, run it, measure it and fix it. The AI writes build123d code, it runs in a sandbox, the result is measured, and on an error the AI repairs its own code (like a coding agent on a compile error). The code is visible in the app ("CAD code" tab).

**Honest scope:** concept-level geometry. About 80% of the translation from idea to a factory-ready package is automated; humans and real factories cover the last 20% (tier 2, human-reviewed). A working prototype takes weeks, not minutes.

## The Studio — prompt-to-product loop (the demo)
1. **Describe.** One sentence: "A Whoop competitor, screenless, 5-day battery."
2. **See it.** The product in 3D, its unit cost, and the top factories, on one screen. **Measured live over several runs: first version in 18-24 s** (the AI-written CAD arrives in the background, ≈ 23 s for v1). The full stages 1-7 run took 56-76 s on 10 test prompts.
3. **Refine it by prompting.** "Add SpO2 and skin-temperature sensing", "make it pink", "thinner, 8 mm pod", "target retail $149". Each prompt creates a **new version** and shows what changed: CAD rebuilt, BOM with real LCSC parts, costs, DFM re-measured, certifications, factory shortlist. **Measured live over several runs: colour and feature refines 4-7 s; geometry refines, where the AI edits its own CAD program, 11-24 s** (≈ $0.01 per refine in one run); restoring a version 1.8 s (one run). Feature prompts add parts at real LCSC prices and change cost and the certification map; "thinner, 8 mm pod" edits the CAD code and is re-measured (8.0 mm in one run); the "make it pink" render arrived 16 s later (one run).
4. **Make it.** One action autofills the rest: factories via the production MCP, agent negotiation (auto-approvals flagged), tooling, QC, logistics and duties, cash plan, brand. **Measured live over several runs: 13 steps to the Launch Dossier in 54-88 s** (≈ $0.34 in one run). On the recorded showcases Make it opens instantly, at $0.
5. **Launch Dossier** (EN + CN): the Factory Pack plus the output of every stage and the assumption register.

The 13 stages remain the **detailed view**, grouped in four phases: **Design** (1-3) · **Make it manufacturable** (4-6) · **Source** (7-8) · **Launch** (9-13). Restoring an earlier version makes it current; later versions stay, and Make it runs again.

## Engineering layer (built)
- **Text-to-CAD:** the AI writes build123d code, run in a sandbox, measured, self-repaired on error. 7/7 live prompts produced a recognisable product (surfboard, changing table, home robot, stick vacuum, irrigation kit, rooftop solar, a vacuum edit v1→v2), one self-repair, ≈ 28-34 s per generation. Parametric families serve as seeds and fallbacks (board, furniture, stick_vacuum, home_robot, irrigation, solar_array, wearable_band, ring).
- **Category packs:** 10 packs with standards and verified citations.
- **Physics checks on the measured CAD** (pass / warn / fail): tip-over angle, board litres and buoyancy, battery life from the power budget, vacuum air watts, irrigation pressure, and PVGIS solar yield (**Sourced**, e.g. Biarritz 35 m² → 5.59 kWp, 6,860 kWh/yr).
- **Electronics architecture + power budget**, and a generated **firmware skeleton** (Zephyr BLE or Arduino Wi-Fi), labeled "not compiled or tested".
- **Prototype path** with cost and time (e.g. kitesurf wearable: $317, 4 weeks).
- Rooftop solar goes to certified installers (fictional) instead of factories.

## Production MCP over HTTP (built)
The 7 tools are served at `/mcp` (Streamable HTTP, Bearer token). Any agent (Claude Code, Claude Desktop, a ChatGPT connector, a script) can search capacity, request quotes and register capacity, in the same store as the web portal. Scripted proof: a factory agent registers "Tidewater Wearables (fictional)", which appears in the portal and ranks #1 (96/100) for "LSR silicone + PCBA, 2,000 units"; the buyer agent then requests a quote for 500 / 2,000 / 10,000. Setup: `mvp/docs/MCP_DEMO.md`.

## Build strategy and showcases (built)
- **Build strategy chosen automatically:** *full design* (furniture, board, lamp, tracker) / *module assembly* (drone, irrigation, wearable, hair dryer, vacuum) / *ODM customisation* (smartphone, camera, home robot), with the honest industrial path for each. New categories: drone, hair dryer, camera, smartphone.
- **Showcase gallery** of 11 recorded examples. Complete through Make it (13/13): whoop_kitesurf, changing_table, stick_vacuum, irrigation_biarritz, solar_biarritz, surfboard_beginner, drone_follow. Start-only: home_robot, hair_dryer, instant_camera, minimal_phone. They open instantly, at $0.
- Drone checks: thrust-to-weight, hover time, EU class C0/C1/C2 (**Sourced** from EUR-Lex).

## Primitive — the Factory Pack
A spec package a factory can quote and build without back-and-forth: structured spec, CAD, BOM with component risk, DFM alerts, certification checklist, estimated landed cost, questions for the factory (EN + CN), assumption register.
Every later layer consumes it: negotiation starts from it, QC checks against it, financing uses its cost model, logistics uses its landed cost. It is also the data that compounds into the moat. Each Studio version produces its own Factory Pack.

## Enablers
1. Spec copilot  2. DFM + component check  3. Certification map  4. Cost and landed-cost engine  5. Factory matching through the production MCP  6. Factory Pack export

## The full journey (13 stages, detailed view)
| # | Phase | Stage | Concept layer | Demo |
|---|---|---|---|---|
| 1 | Design | Brief (idea OR prototype + BOM) | Lovable | Real |
| 2 | Design | Industrial design (3 directions) | Lovable | Real |
| 3 | Design | CAD + technical spec | Lovable | Real |
| 4 | Manufacturable | DFM, components, certification | Core | Real — geometry checks **measured** on the CAD |
| 5 | Manufacturable | Investment (500 / 2k / 10k, tooling, cash, margin, break-even) | Lovable | Real — electronics at **real LCSC prices**, rest "Estimate" |
| 6 | Manufacturable | Where and how to produce | Lovable | Real |
| 7 | Source | Factory matching + factory portal (MCP) | Alibaba | Simulated |
| 8 | Source | RFQ + agent negotiation | Infra | Simulated |
| 9 | Launch | Tooling + samples | Infra | Generated plan |
| 10 | Launch | Quality control (AQL) | Infra | Generated plan |
| 11 | Launch | Logistics + duties | Infra | Duties Sourced (CBP rulings), freight lane derived from Drewry WCI, carrier and transit simulated |
| 12 | Launch | Financing (cash curve, options) | Infra | Generated plan |
| 13 | Launch | Brand + distribution (name, packaging, landing, listing) | Idea → brand | Real |
Final export: Launch Dossier.

## Trust labels
Every number carries one label: **Measured** (on the CAD), **Sourced** (real price or official rate, dated), **Estimate** (assumption shown), **Fictional — demo data**.

**Real:** brief, design, CAD, measured DFM, certification map, LCSC part prices and stock (snapshot dated), HTS line from CBP rulings, Drewry freight index, eCFR citations, cost engine, production plan, brand kit. **Fictional:** the 15 partners (11 factories, 1 integrator, 3 installers), their capacity, quotes and negotiation replies, carrier freight quotes and transit days.

## Two entry modes
- **"I have an idea"** — demo headline, faithful to the brief; starts the Studio.
- **"I have a prototype"** — GTM wedge: founders with a working prototype and money pledged who are stuck on production.

## Wow moment
Prompt → the product in 3D, its unit cost at three volumes, and a top-3 factory shortlist on one screen (first version in 18-24 s over several live runs; 56-76 s for the full stages 1-7 on 10 prompts). Then the change that sells the product: type "add SpO2 and skin-temperature sensing" and watch real LCSC parts, the cost, the certification map and the version diff change in 4-7 s.

## Business model (hypothesis)
Free up to the Factory Pack (land grab, data) → commission on the production order (tier 2, human-accompanied, committed landed price) → take rate on financing and logistics (tier 3).

## Not building
Sophisticated CAD rendering (commodity: Zoo, Backflip, Atech), a real marketplace, payments, real logistics booking.

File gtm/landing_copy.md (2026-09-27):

# Landing page copy — for Orphéo's Framer page

## Framer build checklist
1. **Sections, in this order:** Hero → Built on real data → How it works → Change one thing → CAD is code → Two ways in → The problem → What Make it fills in → Every number carries a label → Build it the right way → Any agent can ask for a quote → Next: a real factory network → Closing CTA → Footer.
2. **Components:** `gtm/framer/SourceGrid.tsx` = "Built on real data" strip under the hero (6 cells, text below). `gtm/framer/DiffBeam.tsx` = "Change one thing", beside the table (Center `v2`, Caption and chips below). Set both in the right panel; do not edit the .tsx.
3. **Meta title:** `PhysicalLovableX — Describe it. See it. Refine it. Make it.`
4. **Meta description:** `Describe a hardware product in one sentence. See it in 3D with its cost, refine it by asking, export a Launch Dossier. Demo: factories are fictional.`
5. **Search:** noindex on (Site settings → SEO). Free `*.framer.website` domain. Delete the "Made in Framer" badge only if the plan allows.
6. **Favicon:** the neutral app icon `mvp/web/src/app/icon.svg` (export to PNG 32/180 px). Never the Hexa mark. No Hexa logo or name anywhere on the page.
7. **OG image:** `deck/screens/hero_*.png` when it exists (folder not created yet); until then `mvp/docs/screens/v2/studio_03_v1.png`, 1200 × 630 crop.
8. **CTA links:** every "Start a product" → `https://physicallovablex.vercel.app/?mode=idea`; "I have a prototype" → `https://physicallovablex.vercel.app/?mode=prototype`. Both params are read by the app (`StartProject.tsx`) and survive the password page. Open in the same tab.
9. **Mobile check (390 px):** H1 on 2-3 lines, tables stack or scroll inside their block, SourceGrid set to 2 columns × 3 rows, DiffBeam keeps ≥ 340 px width or swap for its static fallback `v2/w15c_studio_cad_code_diff.png`; no horizontal page scroll.
10. **Before publishing:** click every CTA once, confirm the footer line and every "Fictional — demo data" mention are visible, search the page for "Hexa" (0 hits).

---

**Product name is a working name** (`{PRODUCT}` = PhysicalLovableX). Tone (see `mvp/docs/BRAND.md`): precise, calm, engineering. Plain sentences, specific numbers, no superlatives, no "revolutionary". Do not add: logo walls, testimonials, pricing, "Backed by" pills, social-proof counters.
Body copy can be trimmed to fit; do not add claims. Sources in `[ ]` render as small footnote links. Every claim below is measured or sourced (PRODUIT.md, PRD.md §8-§10 and §16, PLAN.md §8, `mvp/docs/HONESTY_AUDIT.md`, `mvp/docs/DEMO_SCRIPT.md`). File paths in backticks are for Orphéo only: never print them on the page.

**Primary CTA (all buttons that start the product):** **Start a product** → `https://physicallovablex.vercel.app/?mode=idea`

---

## Hero
**H1:** Describe it. See it. Refine it. Make it.
**Subhead:** Say what you want to build in one sentence. In about 20 seconds you see the product in 3D, its unit cost, and a shortlist of demo factories. Then change it by asking: "thinner", "make it pink", "target $149". When it is right, Make it fills in the rest and assembles a Launch Dossier.
**CTA:** **Start a product**
**Secondary text link:** *I have a prototype* → `https://physicallovablex.vercel.app/?mode=prototype`
**Under the CTA (small):** A working demo. The factories and their quotes are fictional — demo data. Every number shows its source or its assumption.

## Built on real data (SourceGrid strip)
**Eyebrow:** Built on real data
Six cells, text only, no logos (not an endorsement). Pill on the detail face: **Sourced**. Name · tag · detail:

| Name | Tag | Detail |
|---|---|---|
| LCSC | Parts | 29,976 in-stock parts, priced. Snapshot 26 Sep 2026. |
| USITC HTS | Duties | US tariff lines and duty rates, by product code. |
| CBP rulings | Classification | 8 of 10 test products matched to an official ruling. |
| Drewry WCI | Freight | Sea-freight index for the shipping lane. 24 Sep 2026. |
| EU PVGIS | Energy | Solar yield per roof and per site, from the EU JRC. |
| eCFR | Standards | FCC Part 15 rules, quoted with section and link. |

[`mvp/api/costs/data/SNAPSHOT.md` · PLAN.md §8 pass 2-3 · `mvp/api/costs/data/freight_wci.json` · PRD.md §8.4 · `mvp/api/agents/certification.py`]

## How it works — four steps
Heading: **A conversation with your product.**

1. **Describe it.** "A Whoop competitor, screenless, 5-day battery." One sentence is enough.
2. **See it.** The product in 3D, its unit cost at 500, 2,000 and 10,000 units, and a shortlist of three demo factories, on one screen. 18 to 24 seconds in our live runs.
3. **Refine it.** Ask for a change in plain words. A colour or feature change takes 4 to 7 seconds; when the AI has to edit the geometry, 11 to 24 seconds. Each one makes a new version and shows what moved: the CAD, the parts list, the cost, the manufacturing checks, the certifications, the factory shortlist. Go back to any version.
4. **Make it.** One click fills in the rest: quotes and negotiation with the demo factories, tooling, quality control, shipping and duties, cash plan, brand. 54 to 88 seconds in our live runs. You get a Launch Dossier in English, with a machine-translated Chinese version to be reviewed by a native speaker.
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

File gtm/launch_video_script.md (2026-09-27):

# Launch cut — 30-45 s social video

> **⚠️ Asset ready for launch day — NOT to be published without Hexa's go.**
> Internal file. Nothing below is posted, scheduled or uploaded anywhere until that go. The video itself never shows or says "Hexa" (see "Public-safety rules").

**Why this asset exists:** phase 2 opens the primitive in public (deck slide 5 box, slide 11). Lovable's own start was an open-source tool plus a tweeted demo video, then a waitlist (Anton Osika on GPT Engineer, `02_RECHERCHE/lovable.md`, Vidéo 4, 00:21:51). This is that demo video for our open launch: short, silent-readable, one
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

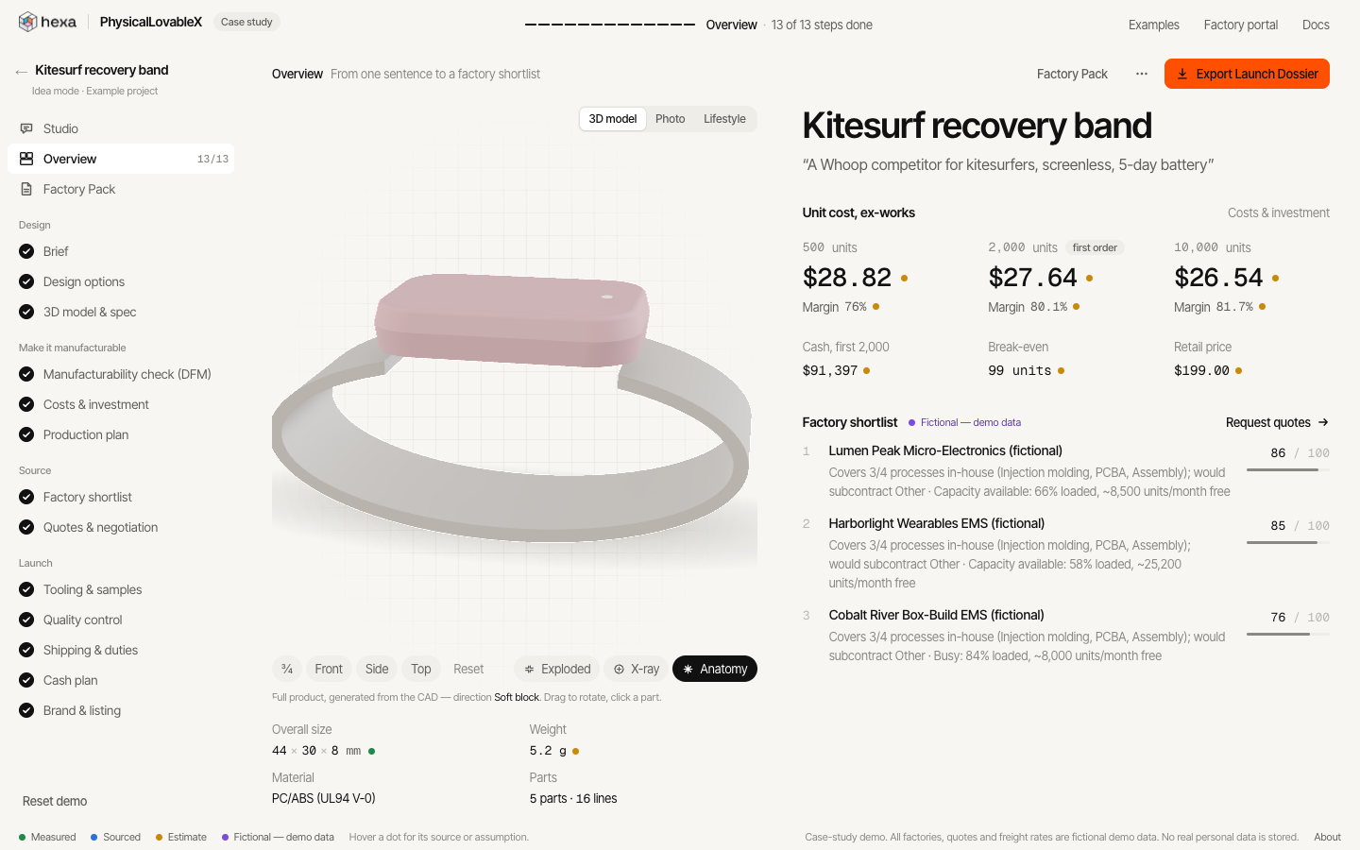
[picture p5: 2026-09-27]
app/docs/screens/v4/after/overview_whoop.png

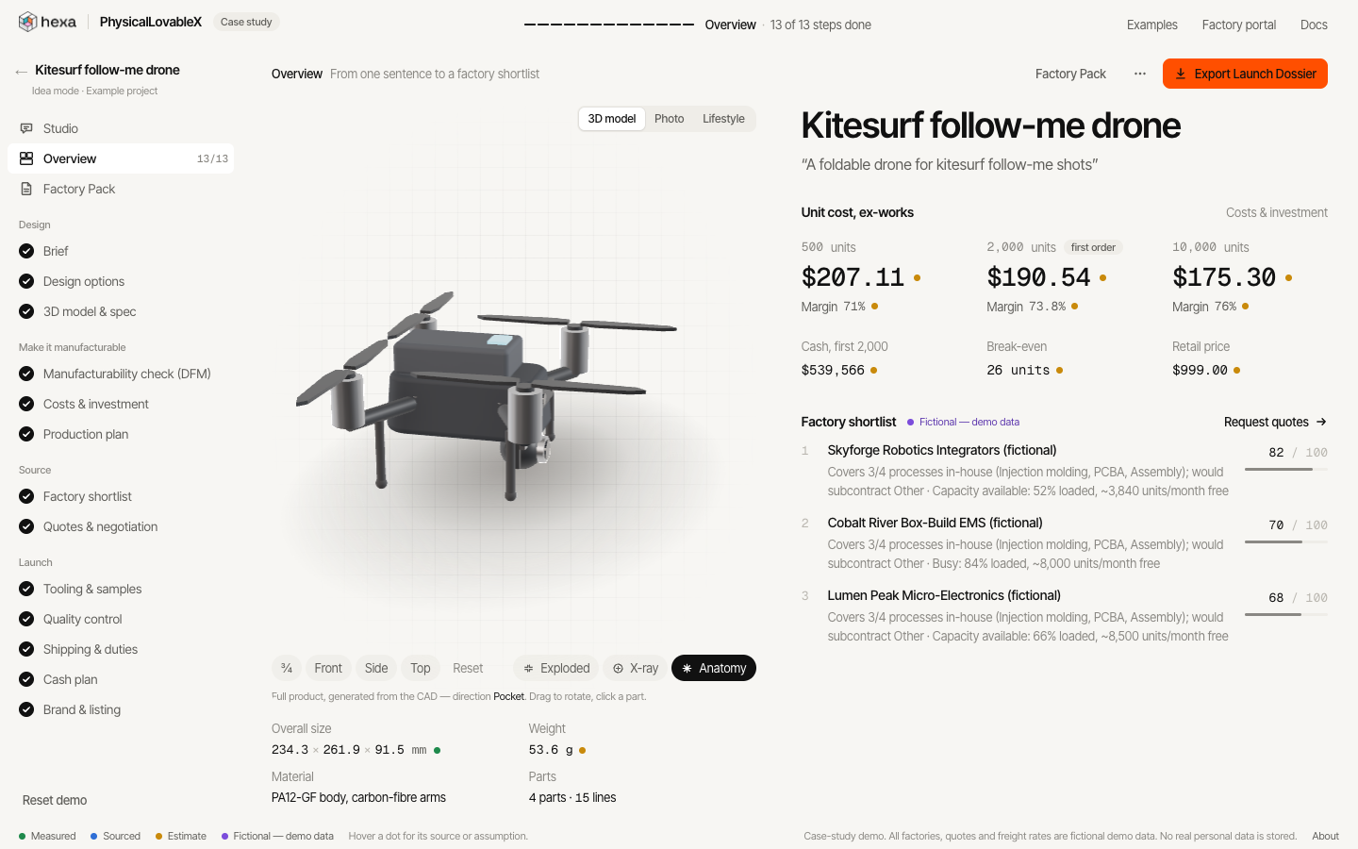
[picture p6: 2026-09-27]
app/docs/screens/v4/after/overview_drone.png

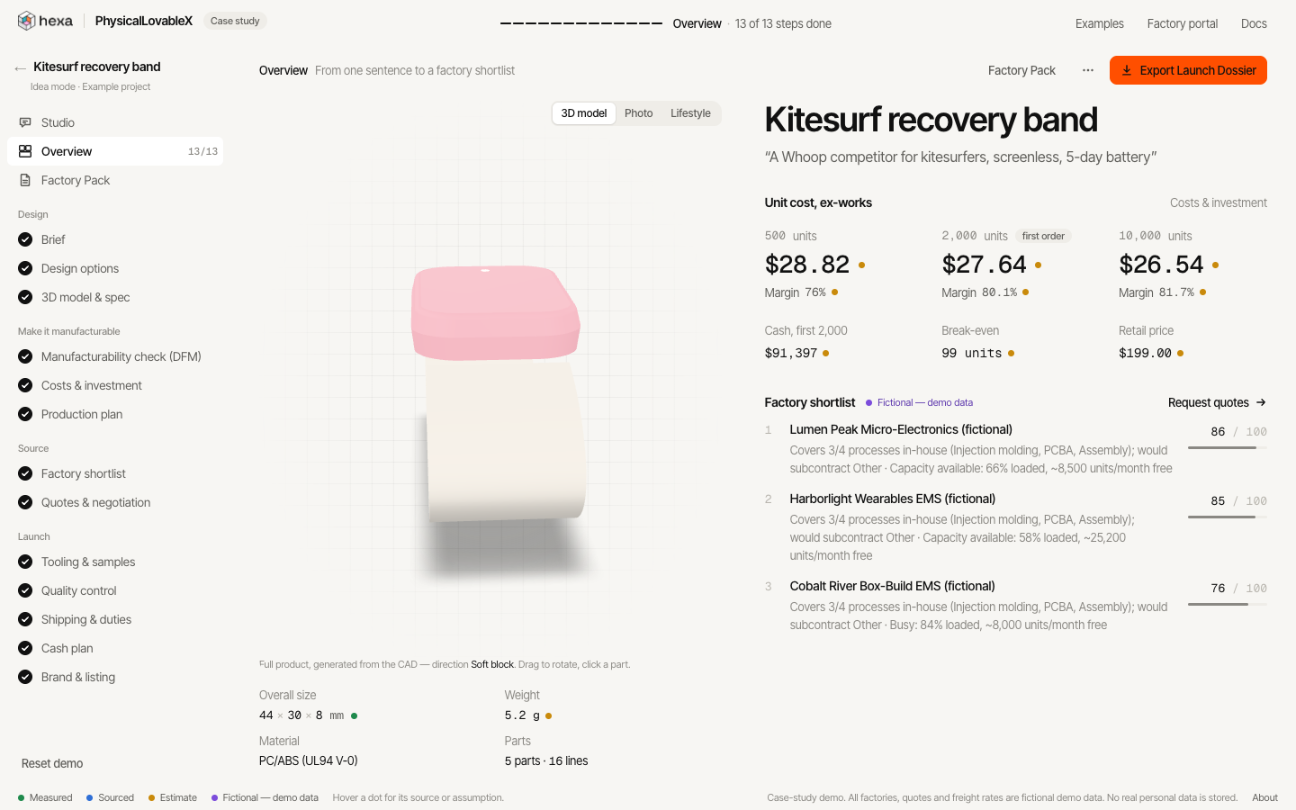
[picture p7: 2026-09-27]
app/docs/screens/v4/after/overview_whoop_viewer_basic.png

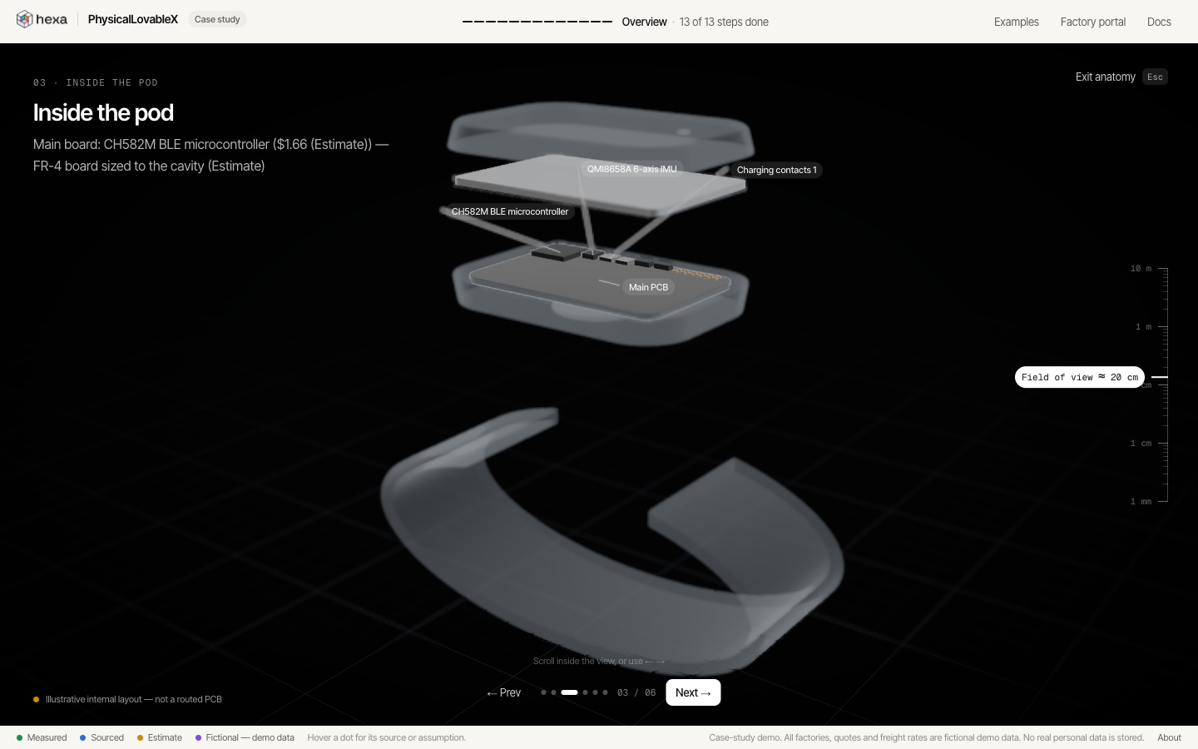
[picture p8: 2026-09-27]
app/docs/screens/v4/after/overview_whoop_anatomy.png

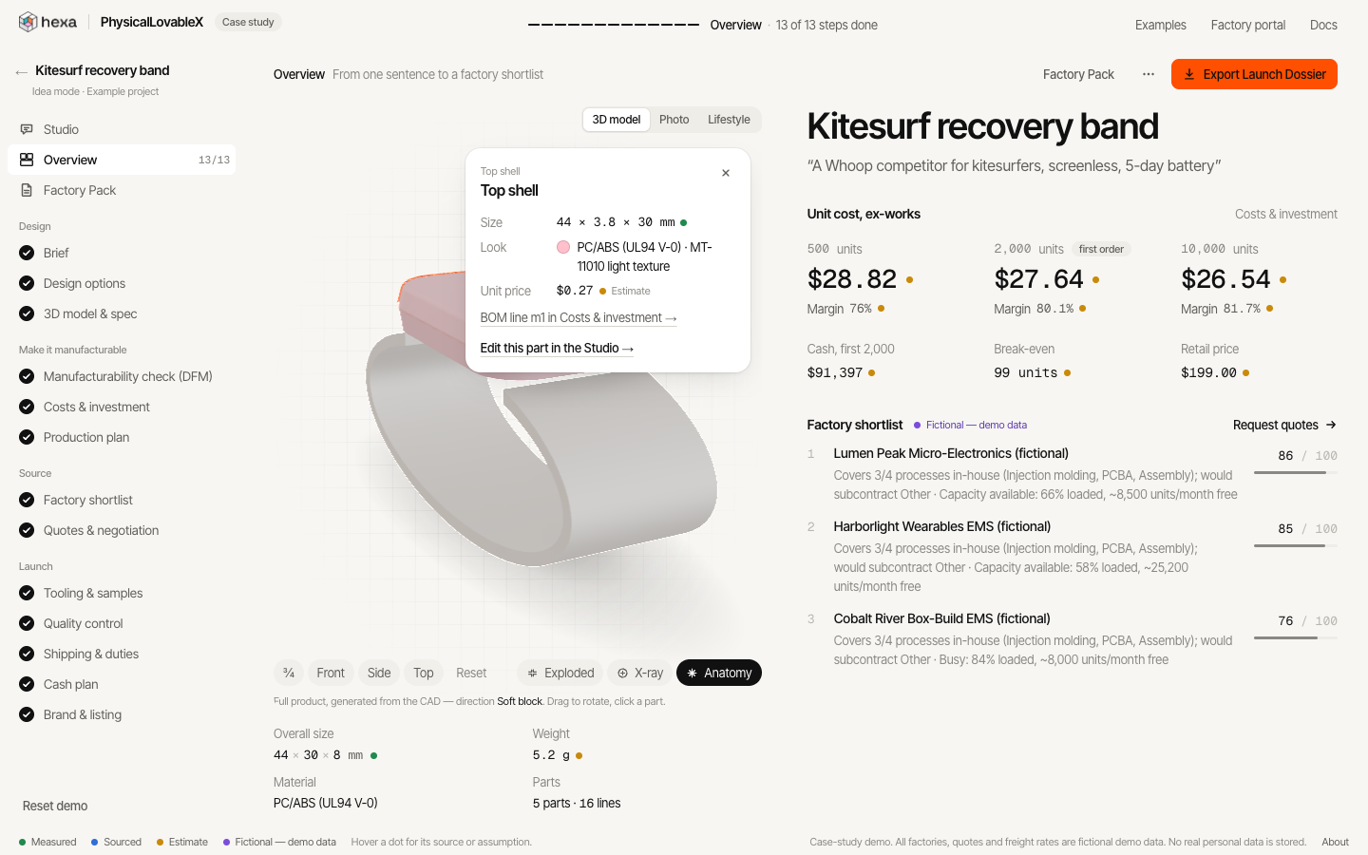
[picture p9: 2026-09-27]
app/docs/screens/v4/after/overview_whoop_part_card.png

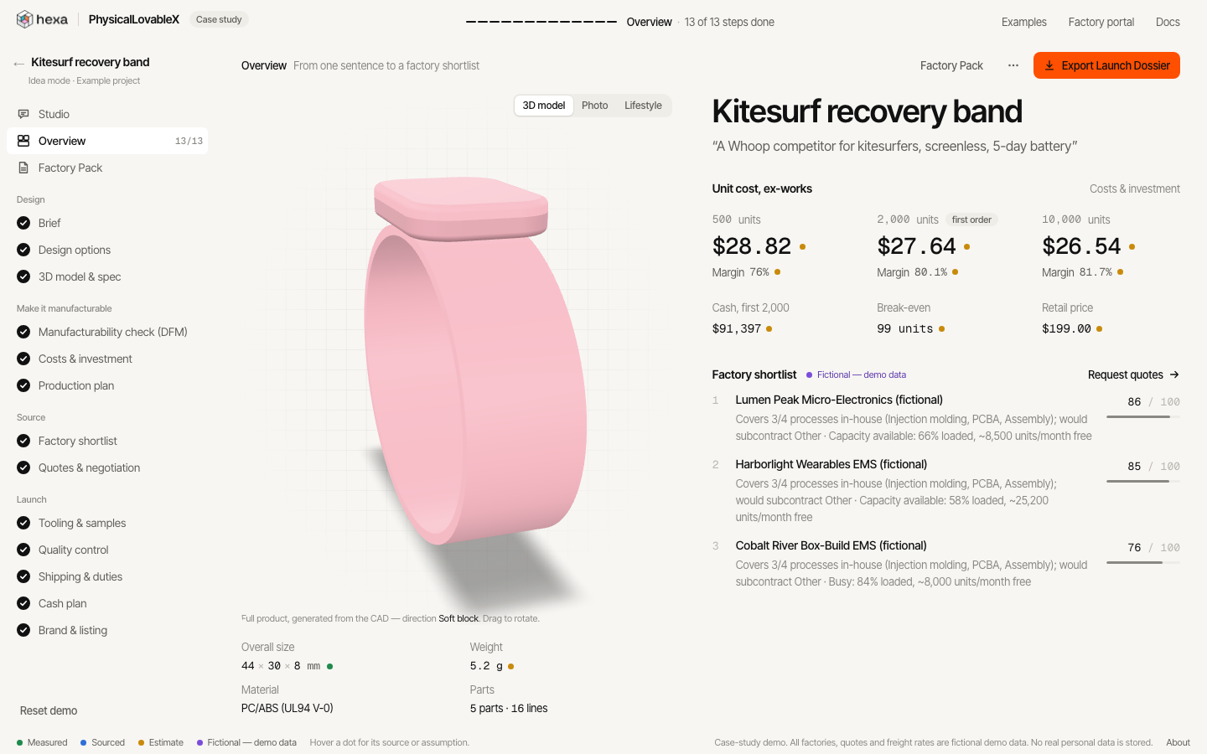
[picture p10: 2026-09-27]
app/docs/screens/v4/before/overview_whoop.png

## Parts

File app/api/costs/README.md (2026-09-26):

# api/costs/

**Owner: W3 — Costs.** Only this session edits this folder. Stages 5 (Investment), 11 (Logistics), 12 (Financing), plus BOM matching and component risk used by stage 4.

## Public interfaces (cross-session contract — signatures are stable)
```python
from api.costs.lcsc import match_bom, component_risk
match_bom(items: list[BOMItem], order_qty: int = 2000) -> list[BOMItem]
#   electronic lines → lcsc_pn + unit_cost_est (Sourced "LCSC price, 2026-09-26", price break at order_qty × qty per unit);
#   unmatched → Estimate with the assumption written in source_or_assumption. Non-electronic lines unchanged. Input not mutated.
component_risk(items: list[BOMItem]) -> list[ComponentRiskItem]
#   electronic lines + Li-ion cells: low stock (<1000 medium, <100 high), extended part, single source, unmatched, UN38.3;
#   alternatives from the snapshot; stock = Sourced LabeledValue. lead_time_weeks is None.
from api.costs.financing import cash_curve, check_cash
from api.costs.landed import landed_cost, hts_line
```

## Modules
| File | Role |
|---|---|
| `lcsc.py` | snapshot loader, matcher, component risk |
| `bom.py` | BOM from stage 3 spec → pasted BOM → LLM ('fast') proposal → category template, then `match_bom` |
| `engine.py` | `@stage_handler(5)`: tiers, tooling, certifications, cash breakdown, margin, break-even |
| `landed.py` | `landed_cost()`, HTS lookup, `@stage_handler(11)` |
| `financing.py` | `cash_curve`, `check_cash`, `@stage_handler(12)` |
| `hts.py` | reads the USITC HTS cache: `duty_for(hts10, s301_heading)` → MFN + Section 301 rate + source_url + fetched_on |
| `precedent.py` | `find_precedent(example, text)`: closest cached CBP CROSS ruling (deterministic, no LLM, no network) |
| `freight.py` | Drewry WCI snapshot: lane rate ÷ units per 40ft (units = 67 m³ ÷ packed unit volume, Estimate) |
| `_fetch_hts.py`, `_fetch_cross.py` | one-off fetch scripts (never run in tests or at demo time); outputs committed |
| `data/` | `jlcpcb_parts.csv` (see `SNAPSHOT.md`), `hts.json` (fallback lines), `hts/<heading>.json`, `cross/<slug>.json`, `freight_wci.json` |

**Sourced data (W13).** Stage 11 HTS = code of the closest cached CBP ruling (assumption a7, label sourced, "not a binding
classification"); MFN from the cached USITC schedule; Section 301 is Sourced only when a cached ruling cites the 9903.88.xx
heading for the same 10-digit code, else Estimate 25%. Sea FCL freight = Drewry lane rate (a8, Sourced) ÷ units per 40ft (a9,
Estimate); LCL/air/express stay Fictional. No precedent → previous behaviour, label estimate. Destination: Los Angeles, East
Coast (New York lane) when the brief says so. Refresh: rerun the `_fetch_*.py` scripts and commit `data/`.

Stage 5 inputs: `volumes`, `volume_factor` (0.5-1.0), `reference_quantity`. Stage 11 inputs: `section_122`, optional `mode`.
Tests: `uv run pytest api/costs` (offline, temp DB, no key).

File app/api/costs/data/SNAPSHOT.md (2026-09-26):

# JLCPCB / LCSC parts snapshot

| | |
|---|---|
| Source repo | https://github.com/CDFER/jlcpcb-parts-database (derived from https://github.com/yaqwsx/jlcparts) |
| Files used | `jlcpcb-components-basic-preferred.csv` and `jlcpcb-components.sqlite3` (in-stock parts, ≥5 pcs), both from https://cdfer.github.io/jlcpcb-parts-database/ |
| Snapshot date | **2026-09-26** (file `Last-Modified: 2026-09-26 05:54 GMT`; per-part `fetched_at` between 2026-09-14 and 2026-09-25) |
| Licence | MIT (Copyright (c) 2024 Chris) — https://github.com/CDFER/jlcpcb-parts-database/blob/main/LICENSE |
| Local file | `jlcpcb_parts.csv` (~7.7 MB, 29,976 parts) |

## What is in it
- The published basic/preferred CSV held only 109 rows on the snapshot date (diodes, transistors, ESD; 1 basic, 105 preferred). It has no connectors or power ICs, so it cannot serve a BOM matcher on its own.
- We therefore merged it with the in-stock SQLite of the same repo (same licence): every part with a category, stock ≥ 5 and a price. Columns trimmed to
  `lcsc, category, subcategory, mfr, package, manufacturer, library_type, preferred, basic, description (≤160 chars), stock, price, fetched_at`.
- `library_type`: `base` = JLCPCB basic part, `expand` = extended part (JLCPCB charges a feeder loading fee per extended part type). `preferred = 1` = JLCPCB preferred part.
- `price` is the LCSC quantity-break string `min-max:price,…` in USD; `lcsc` is the numeric part of the LCSC/JLCPCB number (`C<lcsc>`).
- Part numbers of this snapshot differ from the older W0 fixture examples (`C725790` etc. came from a live jlcsearch query); both are real LCSC parts, the desk-lamp fixture is not regenerated from this file.

## Refresh
```
curl -sL https://cdfer.github.io/jlcpcb-parts-database/jlcpcb-components-basic-preferred.csv
curl -sL https://cdfer.github.io/jlcpcb-parts-database/jlcpcb-components.sqlite3
```
then re-run the merge described above and update `SNAPSHOT_DATE` in `api/costs/lcsc.py`.

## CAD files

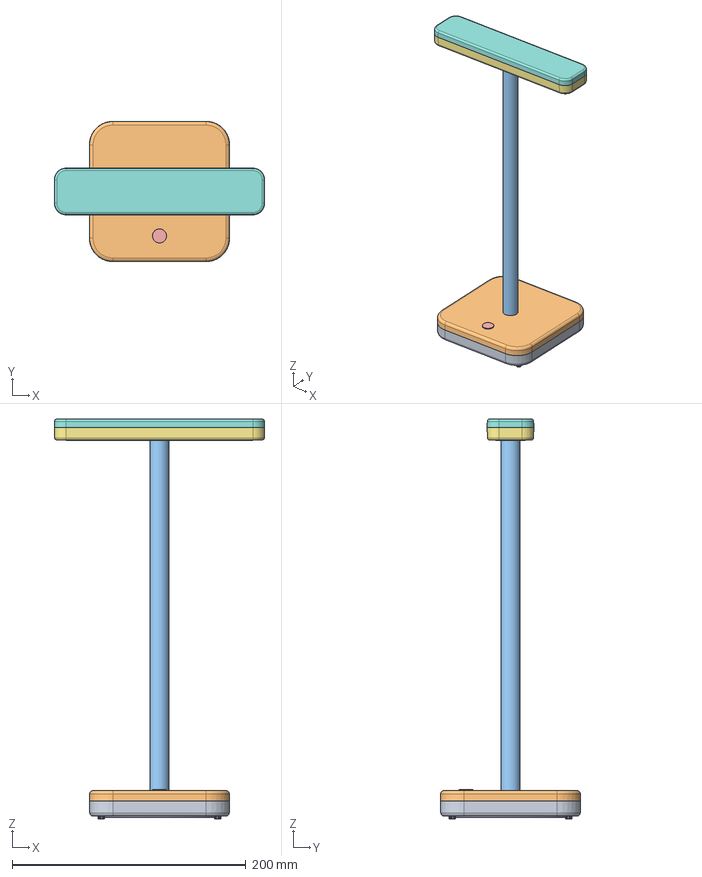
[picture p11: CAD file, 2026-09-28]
app/api/cad/prebuilt/demo_desk_lamp/d1.step
180.0 x 120.0 x 342.4 mm
accent.1
metal.1
diffuser.1
metal.2
rubber.1
accent.2
steel.117 x 4
brass.118 x 4

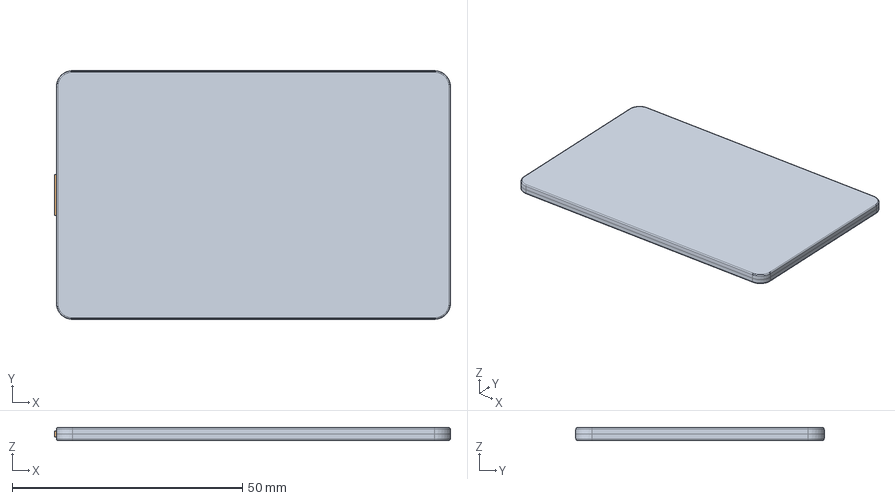
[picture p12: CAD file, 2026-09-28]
app/api/cad/prebuilt/demo_tracker_card/d3.step
86.0 x 54.0 x 2.80 mm
accent.1
button.1

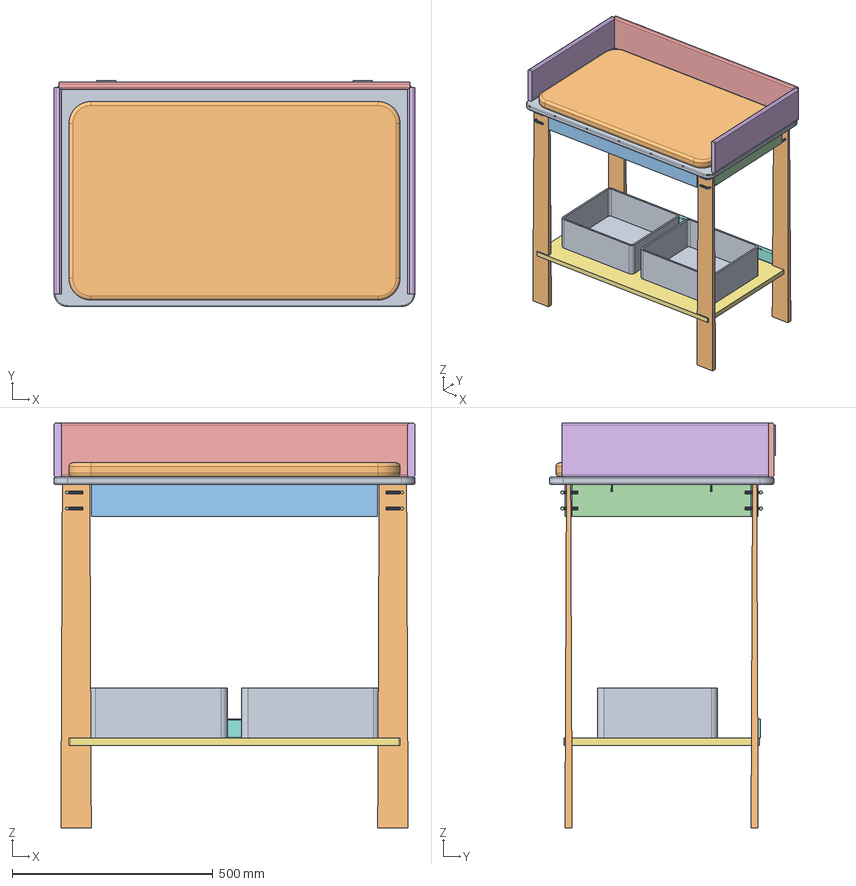
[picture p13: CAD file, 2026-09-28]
app/api/cad/prebuilt/showcase_changing_table/model_v2.step
900.0 x 564.5 x 1010.0 mm
wood.1
wood.2
wood.3
wood.4
wood.5
wood.6
fabric.1
fabric.2
coat.1
steel.1
steel.2
hardwood.141 x 16
steel.142 x 8

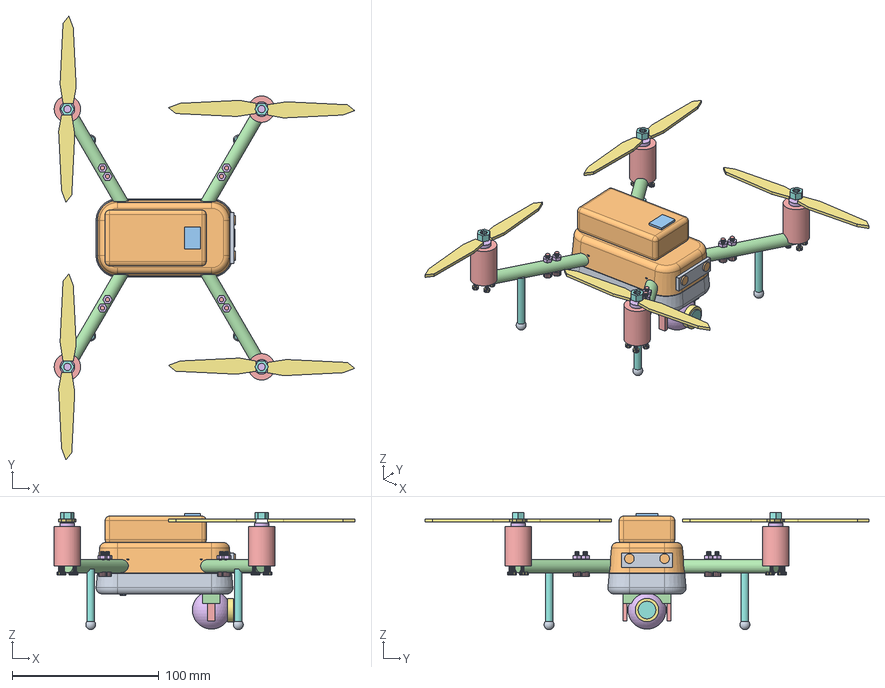
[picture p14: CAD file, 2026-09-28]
app/api/cad/prebuilt/showcase_drone_follow/model_v1.step
204.9 x 302.7 x 80.0 mm
coat.1
glass.11
glass.12
metal.1
coat.11
metal.21
coat.31
coat.43 x 2
rubber.1
rubber.11
metal.2
coat.12
metal.22
coat.32
coat.45 x 2
rubber.2
rubber.12
metal.3
coat.13
metal.23
coat.33
coat.47 x 2
rubber.3
rubber.13
metal.4
coat.14
metal.24
coat.34
coat.49 x 2
rubber.4
rubber.14
accent.1
led.1
metal.40
coat.51
coat.52
coat.60
metal.61
glass.1
steel.151 x 4
brass.152 x 4
steel.182 x 8
steel.183 x 8
steel.187 x 16
steel.188 x 4

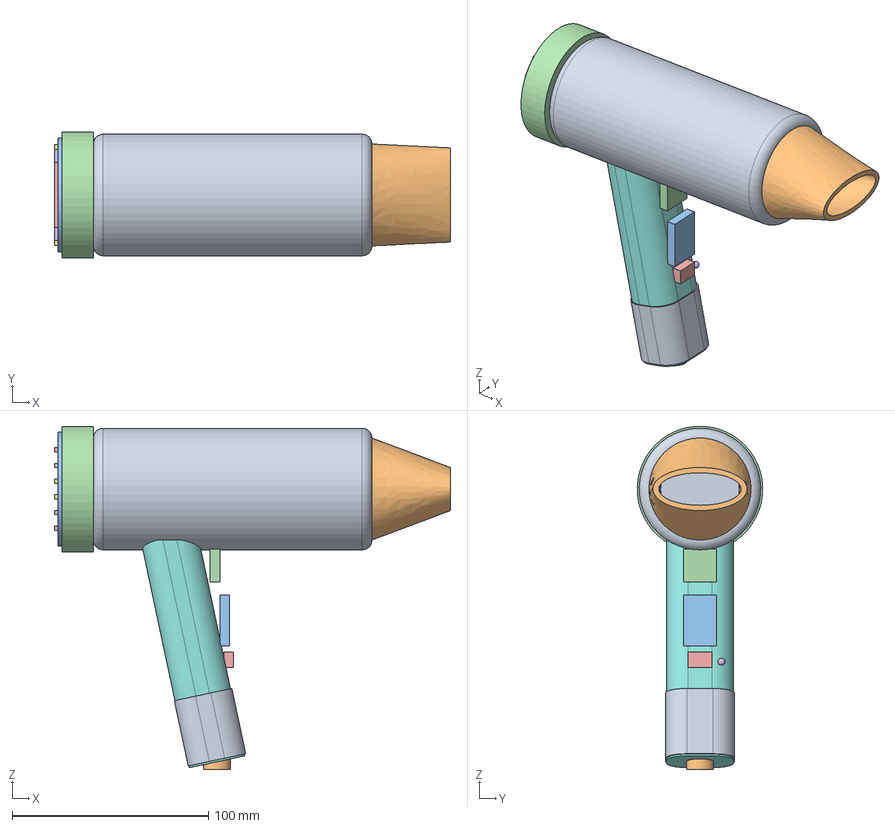
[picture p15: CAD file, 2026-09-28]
app/api/cad/prebuilt/showcase_hair_dryer/model_v1.step
201.8 x 64.0 x 174.9 mm
accent.1
coat.1
accent.2
coat.2
rubber.1
rubber.2
button.1
button.2
button.3
led.1

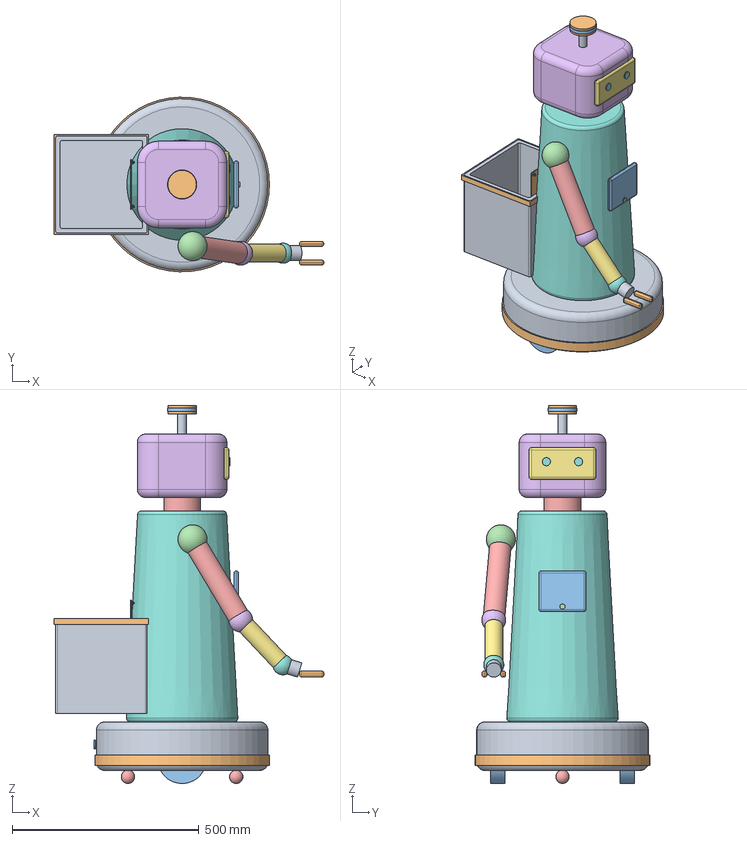
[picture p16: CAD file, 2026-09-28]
app/api/cad/prebuilt/showcase_home_robot/model_v1.step
722.0 x 467.8 x 1012.5 mm
rubber.1
rubber.2
metal.1
rubber.3
metal.2
rubber.4
rubber.5
coat.1
glass.1
glass.2
accent.1
rubber.6
glass.3
led.1
coat.2
glass.4
led.2
led.3
metal.3
coat.3
glass.5
coat.4
coat.5
coat.6
metal.4
rubber.7
rubber.8
metal.5
metal.6
steel.137 x 2
steel.138 x 2
steel.139 x 2
steel.149 x 4
brass.150 x 4
accent.152
steel.162 x 4
brass.163 x 4

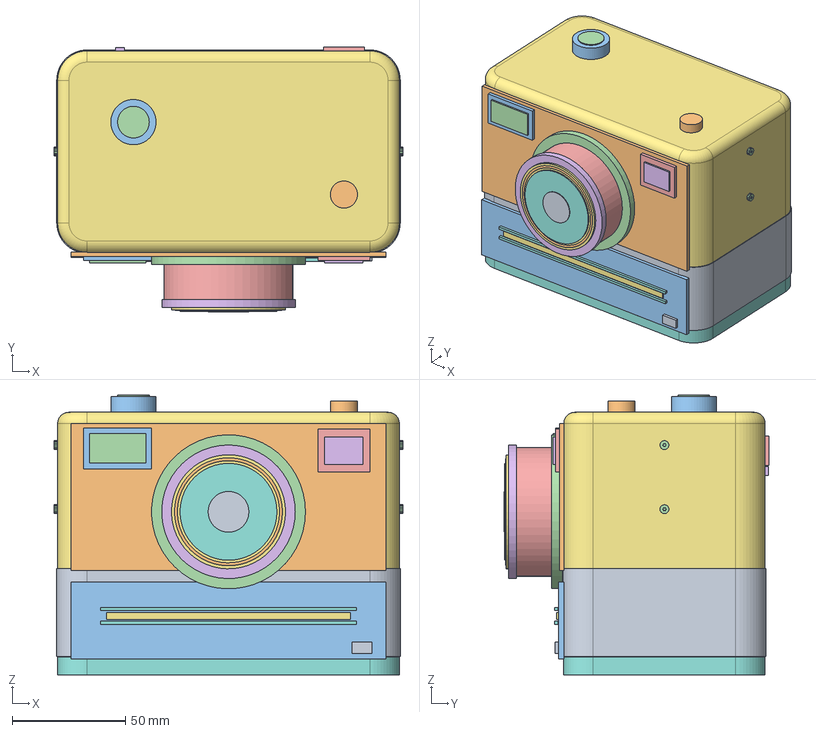
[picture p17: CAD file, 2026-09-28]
app/api/cad/prebuilt/showcase_instant_camera/model_v1.step
154.2 x 117.3 x 123.5 mm
rubber.1
accent.1
coat.1
coat.2
metal.1
coat.3
metal.2
glass.1
glass.2
steel.1
coat.4
diffuser.1
coat.5
glass.3
port.1
metal.3
metal.4
button.1
button.2
metal.5
coat.6
glass.4
led.1
brass.125
steel.136 x 4
brass.141 x 8
steel.140 x 4

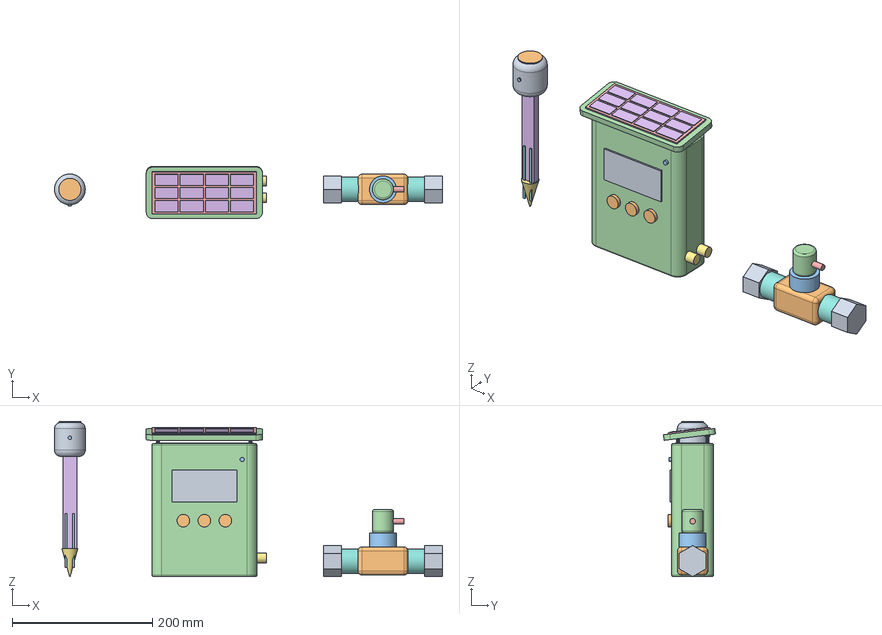
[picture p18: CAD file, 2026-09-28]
app/api/cad/prebuilt/showcase_irrigation_biarritz/model_v1.step
554.0 x 74.4 x 221.5 mm
glass.1
button.1
button.2
button.3
led.1
accent.1
coat.1
cell.1
cell.2
cell.3
cell.4
cell.5
cell.6
cell.7
cell.8
cell.9
cell.10
cell.11
cell.12
rubber.1
rubber.2
coat.2
metal.1
metal.2
coat.3
coat.4
rubber.3
rubber.4
accent.2
accent.3
steel.1
steel.2
cell.13
led.2
rubber.136
steel.143 x 4
brass.144 x 4

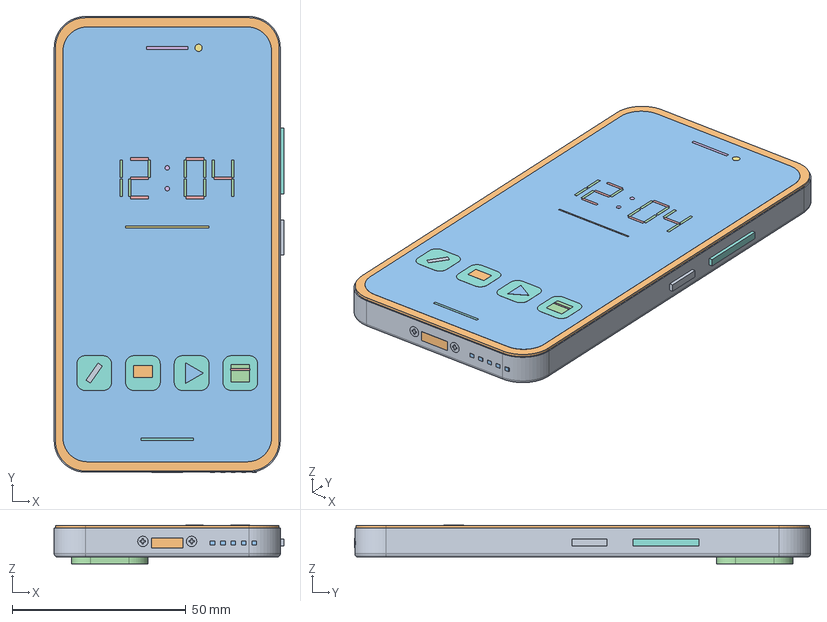
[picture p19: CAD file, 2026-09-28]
app/api/cad/prebuilt/showcase_minimal_phone/model_v1.step
66.0 x 131.1 x 11.1 mm
metal.1
glass.1
coat.1
glass.2
metal.2
glass.3
diffuser.1
button.1
button.2
port.1
coat.2
coat.3
coat.4
coat.5
coat.6
diffuser.2
diffuser.3
diffuser.4
diffuser.5
diffuser.6
diffuser.7
diffuser.8
diffuser.9
diffuser.10
diffuser.11
diffuser.12
diffuser.13
diffuser.14
diffuser.15
diffuser.16
diffuser.17
diffuser.18
diffuser.19
diffuser.20
diffuser.21
accent.1
accent.2
accent.3
accent.4
diffuser.22
diffuser.23
diffuser.24
diffuser.25
coat.7
diffuser.26
glass.4
diffuser.27
steel.154 x 2
steel.159 x 6
metal.149
metal.151
metal.153
metal.156
metal.158
metal.160

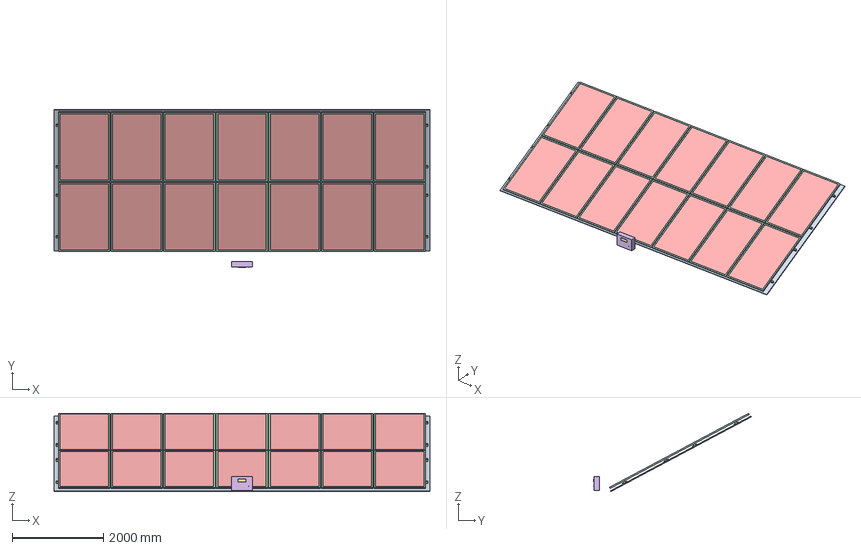
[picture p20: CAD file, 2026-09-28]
app/api/cad/prebuilt/showcase_solar_biarritz/model_v1.step
8258.0 x 3470.8 x 1722.2 mm
roof.1
metal.1
steel.1
steel.2
metal.2
steel.3
steel.4
coat.1
cell.1
coat.2
cell.2
coat.3
cell.3
coat.4
cell.4
coat.5
cell.5
coat.6
cell.6
coat.7
cell.7
metal.3
steel.5
steel.6
metal.4
steel.7
steel.8
coat.8
cell.8
coat.9
cell.9
coat.10
cell.10
coat.11
cell.11
coat.12
cell.12
coat.13
cell.13
coat.14
cell.14
coat.100
glass.1
led.1

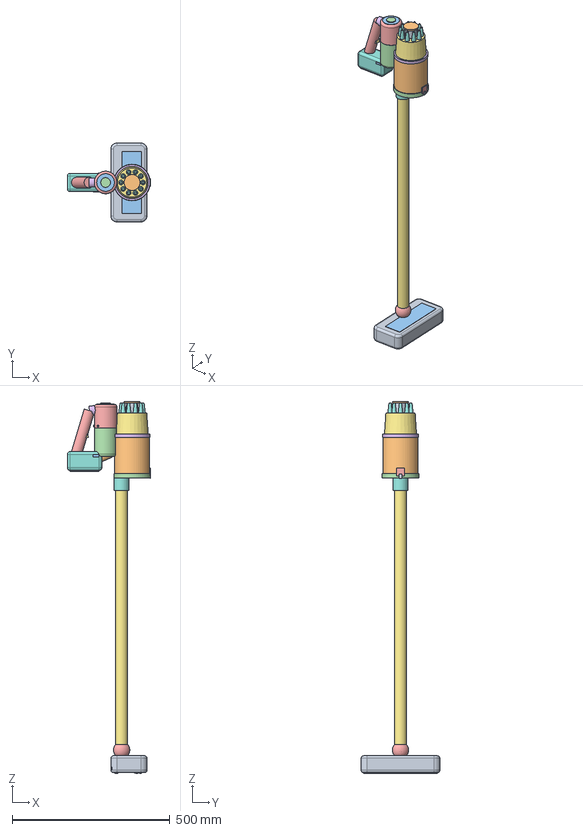
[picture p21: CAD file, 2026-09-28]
app/api/cad/prebuilt/showcase_stick_vacuum/model_v2.step
264.9 x 250.0 x 1180.4 mm
accent.1
rubber.1
clear.1
rubber.2
rubber.3
metal.1
accent.2
metal.2
accent.3
button.1
clear.2
fabric.1
accent.4
button.2
rubber.4
metal.3
accent.10
accent.11
accent.12
accent.13
accent.14
accent.15
accent.16
accent.17
accent.18
accent.19
coat.1
coat.2
metal.4
button.3
accent.5
coat.3
led.1
steel.151 x 7
accent.140
accent.142
accent.144
accent.146
accent.148
accent.150
accent.152
accent.153

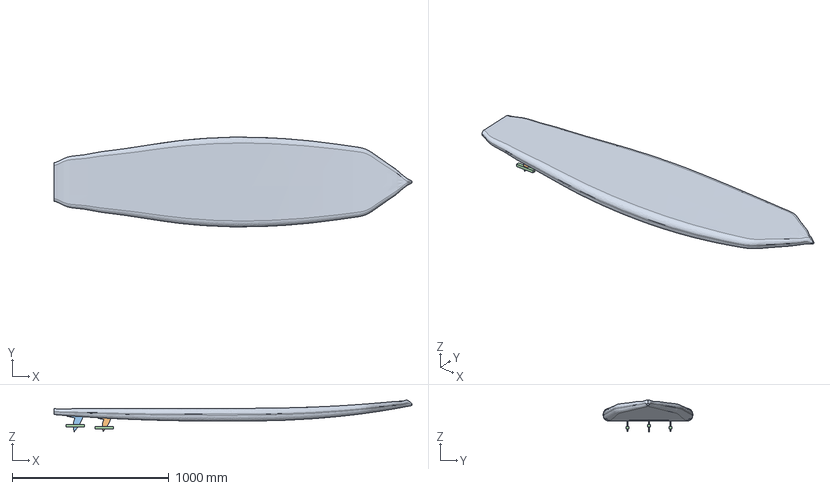
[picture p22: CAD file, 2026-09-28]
app/api/cad/prebuilt/showcase_surfboard_beginner/model_v2.step
2286.0 x 572.6 x 203.4 mm
fin.1
fin.2
fin.3
coat.106 x 3

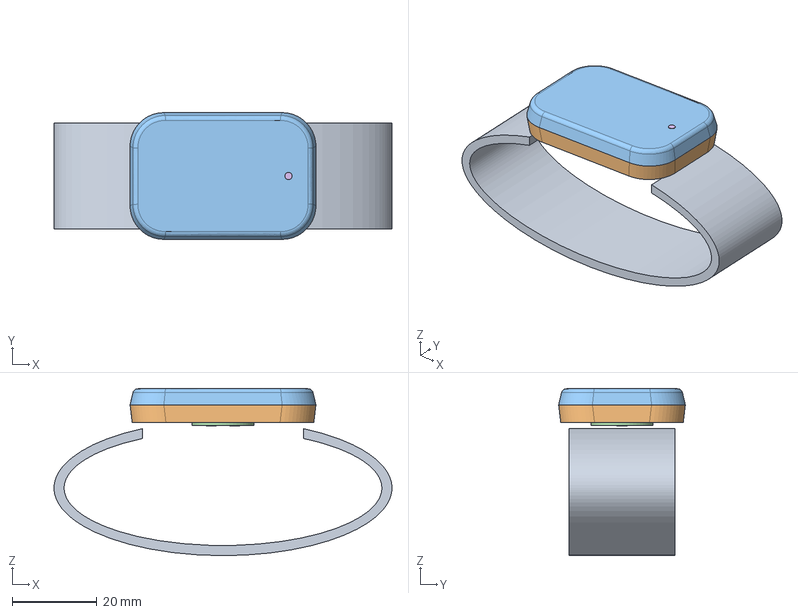
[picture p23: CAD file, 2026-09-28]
app/api/cad/prebuilt/showcase_whoop_kitesurf/model_v2.step
80.0 x 30.0 x 39.6 mm
fabric.1
glass.1
led.1
led.2
diffuser.1

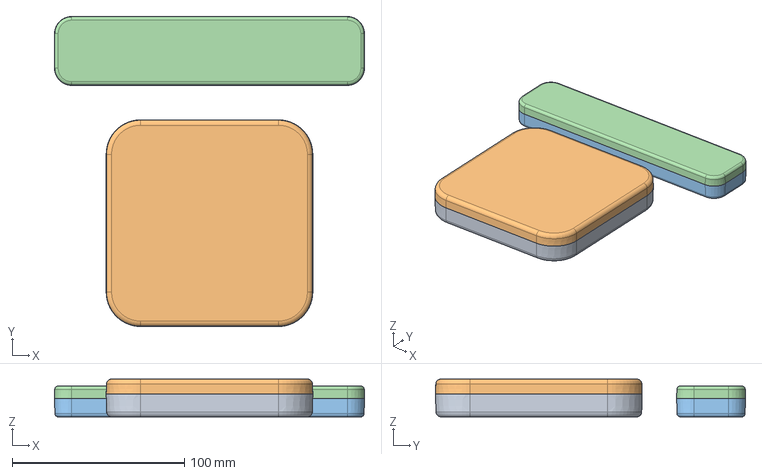
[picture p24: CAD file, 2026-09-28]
app/api/cad/prebuilt/demo_desk_lamp/enclosure.step
180.0 x 180.0 x 22.0 mm

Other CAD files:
app/api/cad/prebuilt/demo_tracker_card/enclosure.step
app/api/cad/prebuilt/showcase_drone_follow/v2.step
app/api/cad/prebuilt/showcase_hair_dryer/d1.step
app/api/cad/prebuilt/showcase_home_robot/v1_enclosure.step
app/api/cad/prebuilt/demo_desk_lamp/enclosure.stl
app/api/cad/prebuilt/demo_tracker_card/enclosure.stl
app/api/cad/prebuilt/showcase_changing_table/model_v1.step
app/api/cad/prebuilt/showcase_changing_table/v1_enclosure.step
app/api/cad/prebuilt/showcase_changing_table/v1_enclosure.stl
app/api/cad/prebuilt/showcase_changing_table/v2_enclosure.step
app/api/cad/prebuilt/showcase_changing_table/v2_enclosure.stl
app/api/cad/prebuilt/showcase_drone_follow/d1.step
app/api/cad/prebuilt/showcase_drone_follow/v1_enclosure.step
app/api/cad/prebuilt/showcase_drone_follow/v1_enclosure.stl
app/api/cad/prebuilt/showcase_drone_follow/v2_enclosure.step
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

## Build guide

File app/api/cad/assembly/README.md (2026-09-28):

# api/cad/assembly/ — assemblies, joints, measured interference (C2)

**Owner: C2.** Behind `CAD_ASSEMBLY=1` (default 0 = no route, no engineering group, no cost lines). Contract:
`contracts/api.md` "Assembly (C2)". Tests: `tests/test_c2_assembly.py`.

Pipeline (per version, cached in `FILES_DIR/<pid>/assembly_v<n>.json`):
1. **Solids** — the labelled STEP next to the version GLB (`model_v<k>.step`, `v<n>.step`, `v<n>_enclosure.step`), grouped into
   parts by the GLB's W29 node tree (`part_id` → mesh children `<role>.<n>`). Legacy W2 directions without a labelled STEP → 404.
2. **Contacts** (`engine.measure_pairs`) — OCCT boolean common for every pair with overlapping boxes (> 0.01 mm³ counts),
   BRepExtrema distance for pairs within 3 mm.
3. **Tree + mates** (`mates.py`) — Prim's spanning tree from the root (largest shell / frame) over the contact graph; each part
   waits for its best-paired parent (prop → motor → arm → hinge → fuselage, lens → gimbal camera, button → the part it shares a
   name word with…); soft parts (rubber / fabric) never carry structural parts. `classify` → kind / method / DOF + rule.
4. **Joints** (`engine.Posed`) — build123d `RigidJoint` / `RevoluteJoint` / `LinearJoint` on the parent, the child copied into
   the joint frame with a `RigidJoint` at its origin, `connect_to` re-places it (closure residual measured).
5. **Checks** — interference classified by rigid bodies (union over rigid / locked joints); motion study (props 12 poses,
   buttons pressed 0.5 mm, lids 0-100°, gimbal ±20°) with the moving subtree; clearances; screw material by line ∩ solid →
   ISO screw length, insert fit and engagement; fasteners → BOM lines (`fasteners.py`, C1 `api.cad.stdparts` if importable).
6. **Exploded vectors** — from the joint axis, cumulative along the tree.

Measured on the four recorded showcases (engine c2.1): whoop 6 parts / 0 interferences (strap drawn 1.4 mm clear of the pod →
`asm_support` warn), stick vacuum 28 / 0 (52 fasteners), home robot 27 / 0 (5 floating parts → warn), drone 25 / **6
interferences**: its 5-inch props overlap each other (motors 100 mm apart, Ø127 mm props) and sweep through the top battery —
a real defect of the recorded concept, found by the motion study.

## C5 — how to enable
1. Set `CAD_ASSEMBLY=1` (API env: Railway + local). Route, engineering "assembly" group (→ Factory Pack via `engineering`) and
   the `EngineeringArtifact.assembly` field turn on; nothing else is needed for those.
2. Parts metadata (owner of `api/studio/parts.py`), in `enriched()` after the loop builds `out`:
   ```python
   from api.cad.assembly import service as asm
   if asm.enabled():
       try:
           extra = asm.part_extras(ctx.pid, ctx.n)
           for e in out:
               e.update(extra.get(e["part_id"], {}))
       except Exception:  # noqa: BLE001 — parts never fail because of the assembly
           pass
   ```
3. Costs (owner of `api/costs/bom.py`), in `load_bom` just before `return match_bom(items, order_qty), gen, notes`:
   ```python
   from api.cad.assembly.service import costs_hook
   items = costs_hook(ctx, items)   # no-op when CAD_ASSEMBLY=0; replaces a generic "Fastener set" line
   ```
4. Web (W1): show `checks` with `domain == "assembly"` as an "Assembly" group; exploded view may use
   `PartMeta.explode_vector × explode_distance_mm`. PDF / Factory Pack renderer: `pack.engineering.assembly` (tree + checks).

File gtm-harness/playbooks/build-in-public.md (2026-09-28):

# Playbook: build in public

**Trigger:** Hexa's go to go public. **Post-go only:** until then, nothing public names the project (`03_DISCOVERY/messages.md`). Cadences below are Hypothesis (our choice) unless sourced.

**Sources:** Elena Verna, Lovable (`02_RECHERCHE/lovable.md`, Vidéo 1): "growth is a trust problem"; employees encouraged to "build in public and grow their social followings and really reach your customer through your own team's voices"; "committed to launching every day" plus "tier one launches" every one to two months; the team "beeswarm[s]" on each other's posts. Anton Osika: GPT Engineer launched as an open-source tool with a demo video, then a waitlist, then Lovable (same file, Vidéo 4; deck slide 5). Maja Voje, ["Turn Building in Public into your most profitable GTM channel"](https://knowledge.gtmstrategist.com/p/turn-building-in-public-into-your): 30 minutes a day, and "Building in Public ≠ Bragging in Public" (`04_LIVRABLE/GTM_Lessons_Substack_MajaVoje.md`).

## Who posts
- **Founder-led first:** the founder's own account, 30 minutes a day, on what was learned: a coded delay cause, a pack finding, a factory round-trip. Real numbers with their labels, no vanity metrics (Voje).
- **Employee-led next:** everyone who ships posts what they shipped, in their own words. Marketing (when it exists) only amplifies tier-1 launches (Verna).

## Cadence
| Rhythm | What | Example |
|---|---|---|
| Each shipped release | Ship-and-post: one short post or changelog line per real change | "Refines now re-measure DFM on the CAD: 4-7 s" (`PRODUIT.md`) |
| Weekly | One learning from the field, anonymised | A delay cause from `03_DISCOVERY/verbatims.md`, with the founder's permission if recognisable |
| Every 1-2 months | **Tier-1 launch**: a bundle with a story and a demo video | Open Factory Pack format + production MCP spec, Osika-style open launch (`gtm/launch_video_script.md`) |
| From run 1 | **Trust brand:** publish on-time rate, defect rate, rejected lots per run | No competitor publishes them (`02_RECHERCHE/parallel/B_concurrence.md`); `PRD.md` §6 |

## Bee-swarming
In the first hours after any team or founder post, the rest of the team comments with substance (a detail, a question, a counter-example), not "great post". One person goes down the list at the end of the day (Verna's routine). Lighthouse ambassadors may join (`playbooks/lighthouse-ambassadors.md`), never scripted.

## Trust rules (growth is a trust problem)
- Every number carries its label: Measured, Sourced, Estimate, Fictional — demo data (`PRODUIT.md`).
- Never show a demo factory, quote or volume as real (`context/profile.md`).
- Publish the bad runs too: a late lot or a failed QC is part of the rate.
- Never name a late founder or their product without written permission; talk about the problem, never the backers' anger (`skills/signal-to-sequence`).

## Measure (monthly, in `skills/weekly-update`)
Posts shipped vs planned; inbound conversations that cite a post; intros from ambassadors. Followers alone do not count (`context/metrics.md`).

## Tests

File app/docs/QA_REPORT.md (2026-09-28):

# QA report — W10 (26 Sept 2026, evening)

**Verdict: ready with fixes** (fixture path and password mode are solid; section F, the one live UI run, is **not done yet** — waiting for "W9e done").

Test rig: API `:8110` (`DB_PATH=api/data/w10.db`, `OPENROUTER_API_KEY` emptied = fixture path), web `:3110`.
Caveat: another session's `next dev` (pid 93663, port 3111) holds the Next 16 lock on `web/`, so a second dev server could not start from `web/`.
I ran a **snapshot copy** of `web/` (taken ≈ 21:40, uncommitted W9e state) from the scratchpad. Re-check the final `web/` after W9e.
Scripts and screenshots: `tests/results/qa/` (Playwright scripts `b*.mjs`, `g.mjs`; stage dumps in `stages/`).

## A. Automated — PASS
- `uv run pytest`: **225 passed, 3 skipped** (71 s). Log: `tests/results/qa/pytest.txt`.
- `tests/run_prompts.py --base-url :8110`, key unset: **10/10 PASS, no 5xx**; wow 4.1–6.2 s, 4 fallbacks per prompt (expected without a key). Report: `tests/results/20260926-214714.md`.

## B. Browser (no password) — PASS with minor findings
| Check | Result |
|---|---|
| `/` start screen, 10 prompt chips, both example cards | OK. Open example → overview in 0.8 s |
| Deep link `/?mode=idea&prompt=Bike%20light…` | Pre-filled (also `mode=prototype`) |
| Overview lamp + tracker: hero image, Studio render / 3D model / Concept toggle | OK. Captions correct: "Rendered from the CAD — direction Column", "AI concept render — illustrative, not the CAD"; model-viewer loads in ≈ 4 s |
| 3 volumes, margins, cash, break-even, shortlist (3, fictional) | OK, all badged |
| All 13 stages × 2 examples | 26/26 render, no NaN/undefined/error text, no broken image, no console error, ≈ 2 s each |
| Factory Pack: 9 sections (§1–§9), CN block | OK. Print view: see B3 |
| PDF export (both) | Downloads in 0.25 s. 25 pages, A4, 611 CJK characters (CN section pages 3–6, 16, rendered with STSong-Light), labels on numbers (Measured 45 / Sourced 60 / Estimate 310 / Fictional 46), legend footer on each page |
| Stage 2 "Render" on a new project | "Render unavailable — 3D shown instead" ✔ (no key) |
| Stage 3 Edit spec → Save spec → reload | Saved and persisted; edited number becomes Estimate |
| Stage 8 (new project) Run → "Approve recommended quote" | "Approved by you", persists after reload |
| Factory portal: Register capacity | New "QA Test Works (fictional)" appears (9 factories) and its page opens (profile, "not audited", 0 RFQs) |
| `/about`, 404, unknown project, unknown factory | All handled with friendly messages + retry/back |
| Reset demo | Confirm dialog → `/projects` shows only the 2 examples, spec edit gone, factories back to 8, recent-projects list empty |
| Autorun on fixtures (new idea) | Modal stepper 1/7 → 3/7 → 7/7, lands on overview in **5.8 s** (real bike-light CAD, 4 parts, 140×90×40 mm Measured) |

## C. Password mode — PASS
- `APP_PASSWORD=qa-pass` + `API_SHARED_KEY=qa-key`: every page 307 → `/login?next=…`; wrong password → "Wrong password. Try again."; correct → returns to the **deep link, prompt still pre-filled**.
- After login: images, 3D and PDF export work (proxy adds the key).
- `/backend/*` without session → 401 (also `/backend/…/export`); API without key → 401 (incl. `/files/…`); `/health` public → 200; API with key → 200.

## D. Honesty sweep — mostly PASS
- Numbers on overview and stages 5, 7, 8, 11, 12 carry badges either per value or at card level (stage 8 quote table, stage 7 scores = "Fictional — demo data" on the card/section).
- Freight options, FOB and insurance lines: Fictional; duties: Sourced; the rest: Estimate. HTS 8513.10.40.00 links to the CROSS ruling and to USITC.
- "Cached example" banner: appears only where `fallback` is true (new project brief). Never on the two demo projects. ✔
- No real company names in factory data (8 fictional names, all "(fictional)"). "Tether" (stage 13 lamp brand option) is a real trademark: see B14.
- Unbadged numbers (polish, see B12): overview "Parts · BOM lines 6 · 18", share-% in cash and landed breakdowns, financing card text ($63,100, $76,000, 626 buyers), stage 7 "62% loaded / 35 days" (covered by card-level label).

## E. Concept coverage (MONITOR §1) — all present, no missing item
| Concept item | Screen | Click path |
|---|---|---|
| Prompt → product + brand (one prompt) | Start `/` → overview `/projects/{id}/wow` → stage 13 | Type prompt (or chip / deep link) → Start → Skip questions → Start autorun → overview; stage 13 for name, packaging, landing copy, Shopify/Amazon drafts |
| Lovable: industrial design | Stage 2 (3 directions, AI concept render + 3D) and overview toggle | Overview → Open all 13 stages → 02 |
| Lovable: CAD files | Stage 3 (STEP / STL / GLB, viewer), Factory Pack §3 | … → 03; download STEP |
| Lovable: technical specification | Stage 3 (editable spec), Factory Pack §2 | … → 03 → Edit spec |
| Lovable: investment needed | Overview cost tiers + cash; stage 5 (3 volumes, tooling, cert, cash breakdown, BOM with LCSC prices); stage 12 (cash curve) | Overview; stage 05 |
| Lovable: how / where to produce | Stage 6 (process + region + lead time per part), stage 7 | … → 06 |
| Lovable: logistics | Stage 11 (landed cost, HTS/duties, freight options) | … → 11 |
| Alibaba: curated network | Factory portal `/factories` (8 fictional factories), stage 7 shortlist with score breakdown | Nav → Factory portal; stage 07 |
| Alibaba: production MCP, factories offer capacity | `/factories` "Offer your capacity" (`register_capacity`), factory page, stage 7 "Queried the production MCP", stage 8 transcript | Factory portal → Register capacity → factory page |
| Infra: DFM | Stage 4 (measured + AI-reviewed alerts, certification map) | … → 04 |
| Infra: factory selection + negotiation | Stages 7-8 (RFQ, side-by-side quotes, agent transcript EN/中文, approve) | overview "Request quotes" → 08 |
| Infra: tooling | Stage 9 (timeline, payments) + cost in stage 5 | … → 09 |
| Infra: quality control | Stage 10 (ISO 2859-1 plan, defects mapped to spec lines) | … → 10 |
| Infra: financing | Stage 12 (cash curve, 6 financing options) | … → 12 |
| Factory Pack (primitive) | `/projects/{id}/factory-pack` (9 sections), PDF | Overview → Read the Factory Pack; Export Launch Dossier |
| Why now | `/about` covers the translation gap; the generative-AI "why now" point is not on screen (deck only) | (not a bug, noted) |

## F. Live run — DONE (26 Sept, on final web/ = be8a720, fresh copy, ports 8110/3110)
No stale lock remained (no listener on 3111, pid 93663 dead). Live key, models main gpt-6-sol / fast gpt-6-luna.
Prompt "Bike light with brake detection" via deep link (pre-filled ✔) → Start → Skip questions → Start autorun.
| Milestone | Wall-clock |
|---|---|
| Start → project created, brief (live) shown with 5 questions | 6.9 s |
| Autorun stepper 1/7 → 2/7 (+14.5 s) → 3/7 (+24.6 s) → 5/7 (+46.7 s) → 6/7 (+50.7 s) → 7/7 (+54.7 s) | advances stage by stage, never stuck |
| Auto-redirect to overview | +56.1 s after autorun, **63 s total from Start** (target < 3 min ✔) |
Server stage times: s1 6.3 s, s2 12.0 s, s3 11.9 s, s4 21.1 s (slowest), s5 0.1 s, s6 3.3 s, s7 0 s. No fallback, no "Cached example" banner, console clean.
Overview: 3D model loads (direction Signal Pebble, 78×34×27 mm Measured), 1 AI concept render (Concept toggle, caption "AI concept render — illustrative, not the CAD"), 3 volumes ($12.46 / $11.48 / $10.54, margins, cash $42,538, break-even 412, retail $39.00, all Estimate), shortlist of 3 fictional factories. (No "Studio render" toggle on a generated project: normal, only cached examples have it.)
"Generate concept render" on direction C: button became "Rendering…", the render was patched in within about a minute (not precisely timed; 2 of 3 directions rendered afterwards, one with a working image at `/backend/files/…/d1.png`, no error). One direction (B) still shows the button, as designed.
**OpenRouter spend** (`GET /api/v1/key`, `usage`): before $7.3917 → after $7.5487 = **≈ $0.157** for the whole run (stages 1-7 + 2 renders; the key endpoint lags by a few seconds; a first read right after the run showed no change). Limit remaining on the key: $42.45 of $50.
New observations from the live run: B1/B2 not reproducible here (no fallback happened, so the fix could not be judged); stage 4 takes 21 s, so it dominates the autorun; two shortlist factories tie at 78/100 (no tie-break note).
Note: the overview redirect worked in one step; routes were pre-warmed, so the cold-compile delay (B13) was not in these times.

## G. Demo-script dry run (PLAN §6, cached lamp) — 6.2 s of app time, 8 clicks
Path measured: `/` → chip click → Open example (0.8 s, lands on overview) → Open all 13 stages → 04 DFM (1.1 s) → 08 negotiation (0.8 s) → 09 timeline (0.8 s) → 12 cash (1.2 s) → Export (0.3 s). Screenshots `g1…g5`.
Friction:
1. "Prompt typed → wow" in the script: with a key, typing the lamp prompt and pressing **Start** launches a live run (≈ 1 min, not cached); the fast path is the **Open example** card. Use it in the video (or add a cached shortcut for the exact lamp prompt).
2. Autorun costs an extra confirm click ("Skip questions, autorun stages 2–7" → modal → "Start autorun").
3. The sidebar stage jumps are fine, but there is no "next stage" button; the video path needs 4 sidebar clicks.
4. Subtitle "From fixture, 26 Sept 2026" on every stage of the cached examples reads as dev jargon.
5. Tracker overview shows a **−7.9 % margin at 500 units** (correct, honest); be ready to explain it.

## Bugs
| id | severity | screen / route | steps to reproduce | expected | actual | owner | screenshot |
|---|---|---|---|---|---|---|---|
| B1 | major | Overview `/projects/{id}/wow` (and PDF header) | New idea with no key / 402 / failing LLM → autorun → overview | Visible "Cached example" flag, since the brief (stage 1) is another product's fixture | Overview shows lamp-derived retail price ($96.12, €89 brief) for a bike light with **no** banner. Only the stage-1 page and the "cached" tag in the sidebar reveal it. Risk: budget is ≈ $3, a 402 mid-demo silently shows a wrong product | W11 web (W7 if the flag must come from the API) | `5x_fx_wow.png`, `50_after_start.png` |
| B2 | minor | Cached banner (any stage) | Same as B1, open stage 1 | Plain wording ("AI unavailable, showing an example") | Raw exception text: "LLMNotConfigured: [main] OPENROUTER_API_KEY or model env var missing" (or the provider error on a 402) | W11 web | `50_after_start.png` |
| B3 | minor | Factory Pack print `/projects/{id}/factory-pack` → Print | Print/PDF (media print) | All columns inside A4 | Right edge clipped: spec table QTY column and "4 files" count cut off (page 2 of the 8-page print) | W11 web | `pk_both.png` |
| B4 | minor | Stage 12 (and stage 5 cash) vs stage 8 | Lamp: stage 8 approved FOB $13.00 / tooling $9,400; look at stage 12 | Cash curve consistent with the approved quote, or an explicit note | Stage 12 keeps stage 5's $12.50 (first order $25,000, tooling $10,100) and says "Matches stage 5 total". Stage 11 does reconcile ("+1.3 %"), stage 12 does not | W7 backend | `stages/demo_desk_lamp_s12.png` |
| B5 | minor | Stage 5 BOM table | Open stage 5 | Stock column filled for LCSC-sourced lines (README says price + stock) | "STOCK" shows "—" on every line; the PDF does show "Stock 1.09M" | W11 web | `stages/demo_desk_lamp_s05.png` |
| B6 | polish | Stage 9 | Open stage 9 | "1 day" | "1 days" | W11 web | `g4_timeline.png` |
| B7 | polish | PDF §2 and stage 7 shortlist | Read spec table / shortlist reasons | "Injection molding" | Raw enums `injection_molding`, `pcba` (wraps as "injection_mol / ding" in the PDF table) | W6/W7 | dossier PDF p. 3 |
| B8 | polish | Every stage subtitle on the demo examples | Open any stage | "Pre-computed example" | "From fixture, 26 Sept 2026" | W11 web | `stages/*.png` |
| B9 | polish | Overview on 390 px viewport | Resize to phone width | No horizontal scroll | Page scrolls horizontally (desktop demo, low priority) | W11 web | `99_mobile_wow.png` |
| B10 | polish | Generated projects (no studio render) | Open overview / stage 2 of a new project | No failing request | `GET /files/{id}/hero_d1.png` → 404 twice (console 404s; UI falls back to 3D correctly) | W11 web | — |
| B11 | polish | Stage 5 / 10 / 11 | Look at "Pre-shipment inspection $540" | Estimate-mixed number labeled Estimate | Badged Sourced although the 2 man-days behind it are an Estimate (rate is Sourced) | W7 backend | `stages/demo_desk_lamp_s05.txt` |
| B12 | polish | Overview, stage 5/11/12 | Numbers without an own badge | Every number badged | Parts · BOM lines "6 · 18", share-%, financing card figures ($63,100, $76,000, 626 buyers) unbadged | W11 web | `10_lamp_wow.png` |
| B13 | polish | `npm run dev` demo | First visit of a route after start | Instant | Cold route compile: first `/wow` ≈ 31 s. Pre-warm every route or demo on a production build | W9 deploy / Orphéo | — |
| B14 | polish | Stage 13 lamp | Read name options | Names not clashing with a known brand | "Tether" is a real trademark (crypto) | W6 fixtures | `stages/demo_desk_lamp_s13.png` |
| B15 | polish | Factory page of a self-registered factory | Register capacity → open its page | Empty stats shown as "no data" | "On-time 0 %, defect 0 %, archetype balanced" shown as facts | W5/W11 | `73_new_factory_page.png` |

Counts: blocker 0 · major 1 · minor 4 · polish 10.

## Not done / known issues
- Section F (live run, spend) — pending "W9e done".
- Tested on a snapshot copy of `web/`, not the final W9e commit; `web/` must be re-smoke-tested after W9e (start, both examples, autorun, export).
- Not tested: the stdio production MCP server, Docker/Railway deployment, non-fixture LLM outputs for stages 8-13 (live path only covers stages 1-7 in autorun).
- CN text quality not judged (machine-translated, labeled as such); STSong-Light is not embedded in the PDF, so a viewer without a CJK fallback font would show boxes (Preview and Acrobat were not checked visually beyond `pdftoppm`).

## Regression (final) — fixtures only, no live calls (26 Sept, evening)
Latest commit, fresh copy of `web/`, API on `:8110` with `OPENROUTER_API_KEY` emptied. Scripts and evidence in `tests/results/qa/reg/` (+ `stages/`).

**Smoke: PASS.** `pytest` 227 passed / 3 skipped; `run_prompts` 10/10, no 5xx; both demo overviews (hero, Studio/3D/Concept toggle, captions correct); all 13 stages of both examples render (no NaN / error text, no broken image, no console error); Factory Pack 9 sections; PDF export of both examples downloads in 0.25 s; portal (register capacity → "(fictional)" factory + page, 8 → back to 8 after reset); `/about`, 404; Reset demo; spec edit persists; login mode (redirect with deep link kept and prompt pre-filled, wrong password message, `/backend` 401 without session, API 401 without key / 200 with key, 3D + PDF work after login).

| id | status | evidence |
|---|---|---|
| B1 | **fixed** | New idea, no key → autorun → overview shows banner "Cached example — AI was unavailable for part of this run — some figures come from a pre-computed example" (`reg/B1_overview.png`); Factory Pack page has it too; PDF cover: "Cached example — AI was unavailable… Numbers derived from those stages describe the example product, not this project", and the stage table marks Brief "cached example (fallback)" (`reg/B1_dossier_newidea.pdf`) |
| B2 | **fixed** | Banner reads "AI unavailable (no API key / credits). This is a pre-computed example…", raw error moved behind a collapsed "Details" (`reg/B2_banner.png`) |
| B3 | **partly fixed** | Print no longer clips (QTY column and counts visible, 11 pages). New residual: in the §2 spec table, Dimensions and Wall text overlap ("180×40×18 mm" runs into "2 mm") — cosmetic, `reg/pkz-02.png`. Downgraded to polish (B3b) |
| B4 | **fixed** | Lamp stage 12 now: "Differs from stage 5 by $+664 ($58,678 vs $58,014) because the negotiated quote qt_orchid_v2 replaced the estimate: FOB $13.00 vs $12.50 × 2,000, tooling $9,400 vs $10,100…"; milestones say "2,000 × negotiated FOB" |
| B5 | **fixed** | Stage 5 BOM Stock column filled (e.g. C210311 → 1.09M) |
| B6 | **fixed** | Stage 9 shows "1 day" |
| B7 | **fixed** | No `injection_molding` / `pcba` enums left in stages 1-13 or in the PDF (spec and tooling tables read "Injection molding") |
| B8 | **fixed** | 0 stage subtitles say "From fixture"; now "Pre-computed example" / "Cached example, …" |
| B9 | **partly fixed** | Overview at 390 px now overflows by 6 px only (scrollWidth 396). Not needed for the Mac demo; polish |
| B10 | **fixed** | New-project run, overview + PDF + pack: console clean, no 404 shown (`p.errs` empty) |
| B11 | **fixed** | Stage 5 "Pre-shipment inspection $540.00" now badged Estimate |
| B12 | **mostly fixed** | Overview now "6 parts · 18 lines" (unit words); financing card figures no longer flagged by the scan; remaining unbadged: share-% in the cash and landed breakdowns (derived values, polish) |
| B13 | **not fixed** (process) | Cold `npm run dev` compile is unchanged by code; use pre-warm or a production build for the jury |
| B14 | **fixed** | Lamp stage 13 names: "Magwick — … coined, short, ownable. Trademark search needed before use.", "Orlune Column" (Tether gone) |
| B15 | **fixed** | Self-registered factory shows "TRACK RECORD — No track record yet / No completed orders on record" instead of 0 % (`reg/B15_factory.png`); archetype still reads "balanced" (cosmetic) |

Remaining open (all polish): B3b print table overlap, B9 6 px mobile overflow, B12 share-% badges, B13 dev-server cold compile, archetype "balanced" on self-registered factories, two-way tie at 78/100 without tie-break note.
Counts now: blocker 0 · major 0 · minor 0 · polish 6 open.

---

# Final QA — pivot (W23, 27 Sept 2026, 03:10-04:10)

**Verdict: ready with fixes.** The scripted live path (Whoop start + 4 refines, restore, `whoop_kitesurf` showcase, Launch Dossier, MCP) runs end to end with no error, no page scroll and 0 console errors. Five lines of the demo script promise something the screen does not show (see B), the SpO2 refine double-counts a sensor, and several gallery showcases show unit economics a VC will not believe (drone 97 % margin, smartphone $36/unit, solar −63 % margin, changing table −108 %). Fix the script wording before the freeze (W18, 30 min). Keep the jury away from the cost panels of those showcases unless W21 fixes them.

Rig: exactly Orphéo's commands, run from this checkout: `cd web && npm run sync-docs` (10 files), then `SKIP_BUILD=0 API_PORT=8123 WEB_PORT=3123 DB_PATH=api/data/w23.db FILES_DIR=api/data/files_w23 scripts/demo_start.sh`, which printed **READY** (every warm-up request ok). Browser: Playwright Chromium. Evidence: `tests/results/final/`. No code was changed. I filled the "Observed diffs" table in `docs/DEMO_SCRIPT.md`.

## A. Automated — PASS
| Check | Result |
|---|---|
| `uv run pytest` (whole) | **527 passed, 31 skipped**, 281 s (`pytest.txt`) |
| `npm run build` | OK, 0 warnings (`npm_build.txt`). The last build was made with the default API URL (:8000), so `SKIP_BUILD=1` works for the standard demo ports |
| `npm run lint` | exit 0 |
| `npx tsc --noEmit` | exit 0 |

## B. Timed rehearsal (live key, one run) — PASS, with script mismatches
| Step | Wall-clock | What changed on screen |
|---|---|---|
| Start: Whoop prompt → v1 | **20.5 s** (AI CAD patched in at 41.8 s; background checks at 43.8 s) | 3D band, 44 × 30 × 10 mm Measured, $30.12 / $28.83 / $27.65, 3 fictional factories, 4 certs, CAD code tab |
| Add SpO2 and skin-temperature sensing | **5.1 s** | 2 LCSC parts (Sourced), unit cost $28.83 → $43.54 |
| Make it pink | **3.9 s** (render at 16.8 s) | Colour chip only |
| Thinner, 8 mm pod | **14.3 s** | 8.0 mm Measured, AI CAD program v1 → v2 (real code diff) |
| Restore v2 → back to v4 | server 0.01-0.03 s, plus a confirm() click each | version switches |
| Target retail $149 | **3.1 s** | Target price chip only |
| **Total waiting** | **46.9 s** | |
| Showcase `whoop_kitesurf` Studio / Overview / stage 8 | 0.7 s / 0.07 s (client-side) / 0.65 s | 13/13, "Auto-approved (autofill mode)" + "Change factory" |
| Launch Dossier PDF (`whoop_kitesurf`) | 0.29 s, 37 pages | EN + CN (1,480 CJK characters on pages 5-8 and 22-23, "machine-translated" note), §10 "Engineering & prototype path" ($317, 4 weeks), "Build strategy — Module assembly", firmware "Generated code — not compiled or tested", assumption **a8_autofill** in the register (id column wraps as "a8_autof / ill"). Labels: Measured 61 · Sourced 76 · Estimate 394 · Fictional 71 |

Full observed-diffs table: `docs/DEMO_SCRIPT.md` → "Observed diffs". **Where the script and the screen disagree:**
1. 1:20: "the certification map changed: [read the row]". **Nothing changed.** SpO2 adds no certification row and shows no certification chip.
2. 1:20: the SpO2 refine adds "Optical heart-rate and SpO2 sensor" LCSC C6454833 $12.18. That is the same part v1 already has as "Optical heart-rate / PPG sensor module". Unit cost rises by +$14.71 (+51 %) for a duplicate part. An engineer on the jury will notice.
3. 2:05: "a colour change shows its cost: [read the delta]". The delta is $0, and the diff does not say "no change".
4. 2:30: "Thinner tightens the battery and sensor stack, and the checks tell me now". **No check changes.** Battery stays 200 mAh, 54 h, warn; there is no DFM or physics chip.
5. 3:30: "Margin at 3 volumes, break-even units". **Not in the Studio.** The $149 refine shows one price chip. The margins (53.7 / 59.3 / 61.5 %) and break-even (193) are on the Overview and stage 5 only.
6. 3:50: "Make it on the recorded `whoop_kitesurf`". The showcase header offers **"Make it again"**, a live re-run (≈ $0.34, 54-88 s), next to "Open overview". Tell the presenter to click **Open overview**, not Make it.

## C. Gallery (11 showcases × Studio, Engineering tab, CAD code tab, Overview, at 1440×900) — PASS on rendering, FAIL on credibility of some numbers
- All 44 views: **no page scroll**, **0 console errors**, **0 HTTP ≥ 400**. Studio opens in ≈ 1.9 s and the Overview in ≈ 2.2 s (full navigation). The four labels show on every Studio view. Also checked at 1280×800 and 1512×982: no page scroll on the app routes.
- Solar: "Cost per installation", "Installer shortlist", "Top installers", site-install build path ✔. PVGIS 1,227.2 kWh/kWp/yr is Sourced, and the 5.59 kWp / 6,860 kWh/yr figures match the docs ✔. **But the numbers conflict:** see F4.
- Drone: thrust-to-weight 3.7 pass, hover time 24.1 min warn, class C1 at 324 g (threshold cites EU 2019/945, checked 2026-09-27) ✔. The checks sit below the fold of the Engineering tab.
- ODM notes on minimal_phone, instant_camera and home_robot ✔. The hair dryer is module assembly.
- "AI-generated CAD (concept level)" appears only as a hover tooltip on the CAD code header, not as visible text (F12).
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

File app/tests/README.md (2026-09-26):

# tests/

**Owner: W6 — Fixtures + Export + Tests.** Only this session edits this folder.

pytest suite + `tests/run_prompts.py` (PRD Appendix A). W0 tests: `test_fixtures.py`, `test_api_flow.py`, `test_discovery.py` — keep them passing.

Contracts: `contracts/artifacts.py`, `contracts/api.md`, `contracts/stage_runner.md`, `contracts/fixtures.md`. Never edit `contracts/`, `api/main.py`, `pyproject.toml`, `web/package.json` — send a CONTRACT CHANGE REQUEST to the Monitor.

## W6 additions
- `test_smoke.py` — no key, temp DB: demo reset, both cached examples through 13 stages + factory pack + export, PDF structure (CN font + outline, labels, banners), Factory Pack provider, tracker card consistency and honesty checks.
- `run_prompts.py` — the 10 prompts of PRD Appendix A against a running API: `uv run python tests/run_prompts.py --base-url http://localhost:8106 [--only 1,2,7]`. Writes `tests/results/<timestamp>.md`; exit code ≠ 0 on 5xx, timeout, invalid artifact or empty PDF (fallbacks pass but are counted).

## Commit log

2026-09-26 PhysicalLovableX — initial export
    [enclosure.step, enclosure.stl, jlcpcb_parts.csv]
2026-09-27 Update: pass-5
    [accounts.csv, d1.step, model_v1.step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]
2026-09-28 Update: pass-7: pro CAD (fasteners, assemblies, drawings) + repository README
    [d1.step, d3.step, enclosure.step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]
